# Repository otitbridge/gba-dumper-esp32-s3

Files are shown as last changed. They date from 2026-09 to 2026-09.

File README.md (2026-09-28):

# GBA専用ダンパー V1 — WeAct ESP32S3-A N16R2

**状態：4層配線・AD6短縮・シルク最終整理・最終DRCまで完了。WeAct版ガーバー・ドリル・CPL出力と照合まで完了。JLCPCBへ5枚発注済み（2026-09-28）。実機未検証。**

正本ブランチは `main`（WeAct版）。識別子 `WEACT_ESP32S3_A_N16R2_GBA_V1_20260928`。WeAct本体の部品取り外し・パターンカットなし。N16R8やESP32S3-Bには適用しない。

- [最終シルク確認PNG](output/pcb/final_review/front_silk.png) / [出力前レビュー](docs/fabrication_review.md)
- [回路図SVG](output/schematic/gba_dumper.svg) / [PNG](output/schematic/gba_dumper.png) / [KiCad回路図](hardware/gba_dumper.kicad_sch)
- [配線概要PNG](output/pcb/routed/routing_overview.png) / [GND面](output/pcb/routed/ground_plane.png) / [配線記録](docs/routing.md) / [配線長比較](docs/routing_comparison.md)
- [配線前配置図PNG](output/pcb/placement.png) / [SVG](output/pcb/placement.svg) / [PCB](hardware/gba_dumper.kicad_pcb)
- [全体BOM](hardware/bom/preliminary.csv) / [調達表](hardware/bom/assembly_parts.csv) / [PCBA BOM](hardware/bom/jlcpcb_pcba.csv)
- [ピンマップ](docs/pinmap.md) / [ファームウェア定義](firmware/main/pinmap.hpp)
- [設計仕様](docs/design_spec.md) / [移行レビュー](docs/weact_migration_review.md)
- [ソケット・機械条件](docs/weact_footprint.md) / [配置条件](docs/pcb_placement.md) / [製造ルール](docs/manufacturing_rules.md)
- [未完了事項](docs/open_items.md) / [立上げ手順](docs/bringup.md)

UART0 TX43/RX44→CH343。GPIO35/36はSAVEデータ兼上位アドレス、GPIO37は/WR。GPIO19/20/48はGBAバスに接続しない。Native USBは本V1では使わずPCはUART端子へ接続。JP1初期OPEN、JP2通常CLOSE。カートリッジ・ジャンパ・子基板の挿抜はUSBを抜いてから。

基板のランド表面仕上げは**鉛含有HASL（通常のHASL）**を指定。注文番号 **[order-id-redacted]**、送料・SMT実装込み **4,609円**でユーザーが注文完了。[注文記録・費用内訳](docs/jlcpcb_order_20260928.md)を参照。

R1〜R33・C1/C2の35個を上面PCBA（5品種、既選定Basic）。J1/J2/J3/JP1/JP2は手はんだ。ソケットは秋月110073の40極品2本から22極を各1本切り出す。WeAct付属ヘッダとの嵌合は到着後確認。ファームウェア成果物はピン定義のみで、ドライバ・ホストは未実装。

旧FNK0099設計は過去コミット `6403600` に保持。[旧製造データ・検査履歴](archive/fnk0099/README.md)はWeAct版に使用禁止。WeAct用Gerber・ドリル・CPLは[製造レビュー出力](output/fabrication_review/README.md)を参照。

## 再生成と確認

KiCad 10.0.5のCLIと、pcbnewを含むKiCad同梱Pythonを使う。`KICAD_PYTHON`と`KICAD_CLI`は各環境の実行パスに設定する。

```sh
python3 tools/generate_design.py
"$KICAD_CLI" sch export netlist --format kicadxml -o hardware/verification/gba_dumper.xml hardware/gba_dumper.kicad_sch
"$KICAD_CLI" sch erc -o hardware/verification/erc.rpt hardware/gba_dumper.kicad_sch
"$KICAD_PYTHON" tools/generate_placement.py
"$KICAD_PYTHON" tools/configure_manufacturing.py
"$KICAD_PYTHON" tools/sync_pcb_metadata.py
"$KICAD_CLI" pcb drc --schematic-parity --format json -o hardware/verification/placement_drc.json hardware/gba_dumper.kicad_pcb
python3 tests/hardware/check_design.py
"$KICAD_PYTHON" tests/hardware/check_placement.py
python3 tests/hardware/check_manufacturing.py
c++ -std=c++17 -Wall -Wextra -pedantic -fsyntax-only tests/pinmap/compile.cpp
```

生成元に変更を反映してから再生成する。配置スクリプトは配線済み基板への上書きを拒否する。配線前の描画手順はtools/export_review.sh。現在の配線画像はtools/export_routing.shで出力する。WeAct向けの配線スクリプトをtoolsへ追加。旧座標に依存するFNK版と製造出力スクリプトはarchiveへ保存。配線済みPCBに対して上記のgenerate_placement.pyは実行せず、配線の再生成は配線前コミットef14faeを別作業コピーに展開して行う。

現行配線の検査はKiCad同梱Pythonでtests/hardware/check_routing.pyとtests/hardware/check_route_lengths.py。前工程の確認記録はdocs/weact_migration_review.md。部品位置・銅箔は維持し、シルク文字のみ更新済み。tests/hardware/check_silkscreen.pyで変更範囲を検証する。

## ライセンス

自作ハードウェア・設計文書はCERN-OHL-P-2.0、ソフトウェアはMIT。[適用範囲と本文](LICENSE.md) / [第三者資料の表示](THIRD_PARTY_NOTICES.md)。実機未検証で、現時点では動作するダンパーファームウェアを提供していません。

## 公開履歴と参照資料

この公開版は新しいGit履歴で開始します。文書中の過去コミットIDは非公開の開発履歴を指し、この公開リポジトリでは参照できません。旧設計の内容はarchive/fnk0099を参照してください。WeAct公式参考PDFは同梱せず、hardware/reference/weact/sources.jsonの公式リポジトリから取得してください。設計・製造ファイルは発注時の内容を維持しています。

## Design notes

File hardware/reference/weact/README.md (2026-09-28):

WeAct公式の回路図・外形図は公開版に同梱していません。原著作権はWeActStudioに帰属します。

公式配布元: https://github.com/WeActStudio/WeActStudio.ESP32S3-AorB

取得時のSHA-256とファイル名はsources.jsonを参照。ファイル名のみASCIIへ変更して記録しています。

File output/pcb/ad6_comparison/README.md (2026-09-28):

# AD6経路比較

変更前はarchive/fnk0099/gba_dumper.kicad_pcb、変更後はAD6再配線前のhardware/verification/ad6_reroute/before.kicad_pcb。上面視・同一縮尺。基板輪郭は100 mm角。全配線を薄灰色、AD6のMCU側とカートリッジ側を層別の色で強調。丸枠はビア、黄色丸は接続パッド、R7両端の破線は抵抗本体。

- before_fnk0099.png: 変更前
- after_weact.png: 変更後
- comparison.png: 左右比較

図の強調はAD6ネット全体（小さな枝も含む）。表示長は比較資料と同じ最短の主経路で、パッド内部・抵抗内部・ビア垂直長は除く。FNKは65.33 mm、WeActは83.23 mm。WeActの全トラック合計は83.32 mmで、主経路との差は約0.09 mm。層間の移動は丸枠で追える。実際のKiCadトラック座標から描画し、線の視認性を上げるため描画幅のみ強調している。基板や配線は変更していない。

再生成: KiCad同梱Pythonでtools/render_ad6_comparison.pyを実行し、SVGをNode sharpでPNGへラスタライズする。

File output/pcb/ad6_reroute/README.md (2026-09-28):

# WeAct AD6再配線前後

左:83.23 mm、右:73.69 mm。詳細は[検証記録](../../../docs/ad6_reroute.md)。実PCB座標を描画。赤F.Cu、橙In2.Cu、青B.Cu。

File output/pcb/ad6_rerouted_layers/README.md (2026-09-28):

# AD6再配線後の4層配線図

2026-09-28。正式PCBからKiCad CLIで各銅箔層とEdge.Cutsを出図。全層を部品面から透視した向き・同一縮尺で表示し、裏面も反転していない。In1.CuはGND面。銅箔・パッド・ビア・穴を表示し、シルクは省略。

- four_layers.png: 4層一覧、上段F.Cu／In1.Cu、下段In2.Cu／B.Cu
- F.Cu.png、In1.Cu.png、In2.Cu.png、B.Cu.png: 各層2000×2000 px
- 同名SVG: ベクトル原図
- source.json: 出図元PCBとSHA-256

AD6主経路73.69 mmの再配線後。PCB自体は変更していない。閲覧用資料であり製造出力ではない。

再生成: 各層について `kicad-cli pcb export svg --layers <layer>,Edge.Cuts --mode-single --page-size-mode 2 --exclude-drawing-sheet -o output/pcb/ad6_rerouted_layers/<layer>.svg hardware/gba_dumper.kicad_pcb`、続いてsharpが使えるNodeで `tools/render_routing_layers.js` を実行。

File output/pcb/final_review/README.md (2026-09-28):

# シルク最終確認

front_silk.png / SVGは上面視。濃紺シルク、灰色マスク開口。tools/export_final_review.shで再生成。製造出力ではない。検証結果はdocs/fabrication_review.mdとhardware/verification/silkscreen/summary.json。

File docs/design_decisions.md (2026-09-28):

# 現行設計の変更履歴

## 2026-09-28 WeAct 4層配線・比較完了

承認済み配置・既存シルクを維持して配線。未配線/DRC/回路図不一致0、In1はGND単一充填領域。総配線長はFNK版比−3.51%、AD6主経路は+27.39%。ユーザー指示に従い比較結果を記録して停止し、シルク最終整理や追加の配線最適化には進まない。詳細はrouting.mdとrouting_comparison.md。

## 2026-09-28 WeAct版・配線前へ移行

ユーザー承認によりWeAct N16R2へ設計変更。GPIO19→35、20→36、48→37。J1/J2は22極・列間27.94 mm、3V3両端子とGND4端子を親基板で接続。ソケット購入は40極品2本。旧Native USB封止部材を除外。回路値・J3・JP・TP・固定脚は維持。子基板無改造。現行仕様はdesign_spec.md、配置判断はpcb_placement.md。旧配線・出力はarchiveへ移し、WeAct版は配線直前で停止。

以下はFNK0099版の過去の判断であり、現行WeAct版を上書きしない。

# 設計判断・変更履歴

## 2026-09-28 WeAct N16R2の調達・機械条件

ユーザーがWeAct ESP32S3-A N16R2を発注済み。販売業者確認として、FNK0099比で長手+5.08 mm・短手+2.54 mm、下面部品なし、USB位置・実装高さは同様との条件を受領。[移行検討記録](weact_n16r2_assessment.md)に採用条件と残作業をまとめた。現行FNK0099のCAD・製造データは未変更。実物の検証済みを意味しない。

## 2026-09-27 初版

提供仕様の論理配線をそのまま採用。28信号、R1〜R33、C1/C2、JP1/JP2、TP12個を作成。FNK0099そのものは購入ボードであり、親基板BOMのJ1/J2ソケットとは別途1台必要。封止部材・固定部材も別途必要。

追記「FNK0099の表面実装部品を外す。改造行為は許容」を、元の無改造制約に優先する変更として採用する。改造は許容されたが、対象部品・実装リビジョン・作業手順は未確定。現時点で部品取り外しは実施していない。

GPIO2 LED負荷の切離し、GPIO48 WS2812入力負荷の切離しは調査候補。部品番号・直列抵抗・分岐点は現物導通で特定する。GPIOへの経路や必須電源部品まで除去しない。GPIO19/20の物理USB配線はソフト設定だけでは消えない。コネクタや保護部品を外す場合も、端子封止不要と即断せず導通・容量を再評価する。

改造許容後もGPIO35〜37予約、UART43/44、GPIO配列、外付けロジックICを追加しない方針は維持する。GPIO割付変更は別途仕様変更として扱う。

## 回路図の表現

J1/J2は独自端子番号とGPIO名を併記した受動ソケットシンボル。J3は論理番号を持つ受動スロットシンボル。FNK0099内部やカートリッジICの駆動能力をERCモデルで推定しない。実在する受動インターコネクトなので全ピンpassiveとした。PWR_FLAGによる警告の一括抑制は行っていない。

電源供給源はJ1-1。JP2→CART_3V3、J2-20→GND。/WRのR31はJP1のカートリッジ側。R32はJP2装着時にGPIO3をR28経由でHIGH保持する。JP2開放時の起動ストラップを保証しない。

ERC 0件は電源余裕・起動時波形・部品改造・基板設計の検証ではない。初版時点ではフットプリントは全て未割付。抵抗0805は候補に留める。PCBとDRCは機械寸法確定後に実施する。

## USB給電についての追加確認

5 V・2 A電源は入力電源の候補とする。ただし、この表示だけではカートリッジを含むシステムの給電能力を確定できない。給電経路はCH343側USB-Cの5 V → FNK0099搭載レギュレータ → 3.3 V → ESP32とカートリッジ。外部電源の2 A定格は3.3 V端子の取り出し可能電流ではない。

搭載レギュレータの型番・供給能力・放熱条件を確認し、対象カートリッジ読出し中の電圧低下・発熱・リセットを評価する。現時点では給電能力を検証済みとしない。

PCへのダンプはCH343側USB一本で給電・データ通信する方針を維持する。充電器だけではPC転送できない。Native USB側はGPIO19/20をGBAバスに使うため、給電目的でも使用しない。複数電源を無検討で並列接続しない。

## FNK0099ソケット形状の採用

2026-09-27のユーザー指定に基づき、kariya-iot-pcbの1×20ソケットをJ1/J2へ割当。ピッチ2.54mm、列中心間25.40mm、穴径1.02mm。詳細は[fnk0099_footprint.md](fnk0099_footprint.md)。現行GPIO割付を維持し、全体の機械干渉確認は未完了。

## FNK0099実装高さ・下面部品の条件採用

2026-09-27のユーザー追加指定により、kariya-iot-pcbのESP32-WROVERと同一として設計する。FH2.54-40U1GF8.5-0.5（ハウジング高さ8.5mm）、下面部品突出最大2.0mm、基板間隔最低2.5mm・目標3.0mm以上を採用。ボード直下にはJ1/J2以外の表面実装部品を配置しない。詳細は[fnk0099_footprint.md](fnk0099_footprint.md)。基板間隔は組立後の受入検査として維持し、既存設計からの採用を新規実測済みとは記録しない。

## PCBA受動部品の選定

2026-09-27、工程1として抵抗3種類・コンデンサ2種類を0805のJLCPCB Basicで選定。片面SMT、手はんだソケット類はPCBA BOMから除外。型番・定格・DCバイアス評価は[pcba_parts.md](pcba_parts.md)に記録。回路値とGPIO配線は変更しない。

## JP1/JP2の型式確定

2026-09-27、秋月PH-1X2SG（108593）とつまみ付き2228GG黒（103890）を共通採用。ヘッダは各1個を手はんだ、キャップは計2個を用意しJP1は初期別保管・JP2は装着。推奨穴径1.02mmのフットプリントへ割当。詳細は[jumper_parts.md](jumper_parts.md)。

## J3フットプリントのユーザー裁定

2026-09-27、「渡してあるGitHubのリポジトリのフットプリントで確定」との明示裁定に従い、GekkioのGameBoy_Cartridge_AGB_1x32_P1.50mm_Socket_Horizontalを原本のままJ3へ割当。説明文および32番端子位置を理由とする採用保留を解除。実測済みへの書換えは行わず、採用根拠をユーザー裁定として記録。

## 2026-09-27 TP・組立部材と調達情報

TP全12点にφ2mm露出銅箔パッドを割当。J1/J2のRonmee型番・秋月110073を回路図/BOMへ補完し、ユーザーの嵌合確認済み回答を記録。J3はユーザー指定AliExpress商品1005005472303111を調達先として記録し、メーカー型番は不明と明示した。承認済みフットプリントを維持。

Native USB封止にTK-CAP6BK＋No.21赤絶縁テープ、親基板下面脚に秋月101861を選定。部材の詳細と配置・組立確認はmechanical_parts.md。調達数量を回路図実装数量から分離したassembly_parts.csvを追加。封止材と脚は選定済みだが実物適合・配置検証済みではない。

## 2026-09-27 PCB仮配置

100×100mm、4層、上面に全52部品と4個の固定穴を配置。J1/J2列間25.40mm、J3原本形状を維持。FNK0099外形・アンテナ・USB位置は仮占有範囲として明示し、未配線86件を残した配置成果物。DRCは未配線以外0件。詳細はpcb_placement.md。製造承認は行わない。

## 2026-09-27 FNK0099機械範囲のユーザー確認

ユーザー回答「ユーザ側で問題ないことが確認できています」に基づき、e5463f8のFNK0099外形・USB・アンテナ範囲と配置を確認済みとして採用。該当範囲の確認待ちを解除し、配置変更なしで次工程へ進める。文書のみ更新し、既存PCB・画像の仮注記より本確認記録を優先する。新規採寸・電気検証・製造承認の完了は意味しない。

## 2026-09-27 配置・アクセスのユーザー確認

「配置調整、固定穴・ジャンパ・TPへのアクセス確認」について、ユーザーから問題ないことを確認済みとの回答を受領。現配置のH1〜H4、JP1/JP2、TP1〜TP12へのアクセスを確認完了とし、追加の配置調整は不要とする。文書のみ更新し、PCB形状・座標は維持。新規実測や固定強度・封止保持性・電気的検証の完了とは区別する。

## 2026-09-27 製造ルール設定

JLCPCB公式能力に照合し、最小配線幅・間隔0.20mm、標準ビア0.60/0.30mm、電源標準0.80mm・最小0.50mm等をKiCadに設定。配置・機械寸法は変更せず、製造シルク基準による既存120警告を残項目として記録。カスタムルールの読込とDRC実行に成功。未配線86件。製造承認は行わない。

## 2026-09-27 4層配線完了

既存配置を維持してF.Cu/In2.Cu/B.Cuを配線、In1.Cuを連続GND面とした。未配線0、電気・幾何DRCエラー0、回路図等価性問題0。貫通ビア63個。シルク120警告は別工程で修正。詳細はrouting.md。製造承認は行わない。

## 2026-09-27 シルク整理・出図前CAD確認

可視シルク文字を高さ1.0mm以上・線幅0.15mmへ統一し、Native USB禁止・USBを抜いてからの操作・ジャンパ初期状態を表示。既知120警告を全解消。配線・ビア・パッド・部品位置は維持。DRC違反0・未配線0・回路図不一致0。PCBA上面35部品と5行BOMも照合。実機条件未完了のため製造承認は行わない。

## 2026-09-28 — AD6のみの再配線

ユーザー指示により他配線を固定し、AD6のGPIO10→R7区間だけを短縮。全主経路83.23→73.69 mm、ビア2→3個。他ネットとCART_AD6のトラック・ビア624要素は変更前と完全一致。配置・シルク不変、DRC/未配線/回路図等価性問題0。最短性の証明ではなく、長さ短縮とビア追加のトレードオフを採用。[記録](ad6_reroute.md)。

## 2026-09-28 — WeAct版シルク最終整理

ユーザー承認の工程範囲に従い、WeAct型番とUSB-UART通信経路、Native USB非使用、電源を抜いてからの操作対象を表示。UNROUTED表記を更新。シルク文字のみ変更し、AD6再配線後の全銅箔・配置・パッド・穴を維持。DRC/未配線/回路図等価性問題0。ガーバー・ドリル・CPLは出力せず停止。[出力前レビュー](fabrication_review.md)。

### シルク表示の追加修正

ユーザー指示によりNATIVE USB: UNUSEDを削除。J1/J2間の手前（USB側）のJ1寄りX=64、Y=98 mmへPCを追加。PC通信UART0→CH343の方針は維持し、Native USBホスト機能の正式採用を意味しない。DRC・未配線・回路図等価性問題0、銅箔と部品配置は不変。

ユーザーの追加指示により左側のPC: USB-UART表示を削除。J1寄りのPC表示とUART0→CH343の通信方針は維持。

ユーザー指示によりR32手前を「GBA DUMPER / WEACT ESP32S3-A」「S3-WROOM-1-N16R2 / REMOVE USB FIRST」の2行へ変更。中央左の旧型番表示と独立したREMOVE USB FIRSTを削除。配線・配置は維持。

ユーザー承認によりジャンパ表示を用途→初期状態の順に統一。JP1はWR ENABLE / DEFAULT OPEN、JP2はPOWER LINK / DEFAULT CLOSED。シルクのみ変更し、電気的仕様は維持。

ユーザー指示により中央のJP1 / JP2 / CARTRIDGEを削除。JP2をCARTRIDGE / POWER LINK / DEFAULT CLOSED、JP1をCARTRIDGE / WR ENABLE / DEFAULT OPENの3行へ変更。

ユーザー確定のリポジトリURLとQRを左中央へ追加。読み取り先はhttps://github.com/otitbridge/gba-dumper-esp32-s3。リポジトリ作成・公開は未実施。DRC0、画像復号一致、銅箔・配置不変。詳細はfabrication_review.md。

2026-09-28、ユーザーが「シルクは以上で確定」と承認。URL・QRを含む現行シルクを確定し、コミットする。次工程のGerber・ドリル・CPL出力と照合は、ユーザーの「まだ作業はしない」に従い未着手。シルク確定は実機検証完了や発注承認を意味しない。

## 2026-09-28 — 鉛含有HASLを指定

費用低減のため、ユーザー指定により現行WeAct版の裸基板ランド表面仕上げを鉛含有HASL（通常のHASL）へ確定。「HASL候補」の曖昧な表記を修正。PCBAはんだペースト組成の指定とは区別する。旧FNK版の見積り・製造前提は履歴として保持し、現行仕様には適用しない。金額はWeAct版の見積り時に確認する。

## 2026-09-28 WeAct製造レビュー出力

ユーザー指示によりHASL指定文書をd64897fでコミット後、Gerber・ドリル・CPLを作成・照合。output/fabrication_reviewにWeAct専用レビュー出力を保存。DRC0、PTH142、NPTH6、PCBA35個/BOM5品種一致、Gerber上のQR復号一致。実機ゲートと製造承認は未完了のまま維持。

## 2026-09-28 WeAct版をユーザーが発注完了

JLCPCB注文番号 **[order-id-redacted]**、送料・上面SMT実装込み **4,609円**で注文完了とのユーザー報告を記録。5枚、鉛含有HASL、Economic PCBA、35部品/枚、配送OCS Express。[注文記録と費用内訳](jlcpcb_order_20260928.md)。注文完了と実機検証完了は区別し、残件はopen_items.mdに維持する。

## 2026-09-28 WeAct版をmainの正本へ移行

ユーザー承認により、注文記録を `275fde3` でコミット後、`main` を `6403600` から `feat/weact-n16r2` の `275fde3` へfast-forwardで更新。main側に独自の追加コミットがなかったため、マージコミットや履歴の強制上書きは不要だった。正本はmainのWeAct ESP32S3-A N16R2版とし、旧FNK0099版は過去コミットとarchive/fnk0099に保持。作業ブランチは削除せず残す。

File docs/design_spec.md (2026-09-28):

# WeAct ESP32S3-A N16R2 設計仕様

2026-09-28。正本識別子 `WEACT_ESP32S3_A_N16R2_GBA_V1_20260928`。元のGBAバス・ROM/SAVE・UART要求を継承し、ボード固有条件は本書とpinmap.mdを優先する。初期引継ぎ原文はarchive/fnk0099/docs/handoff.mdの履歴に保存。

- ESP32-S3-WROOM-1-N16R2（16 MB Flash、2 MB Quad SPI PSRAM）搭載のWeAct ESP32S3-A専用。GPIO35/36/37を使用可能な型番であることを到着時に確認。R8やB版へ転用しない。
- 子基板は無改造。GPIO2にLED負荷なし。RGB用48、Native USB用19/20、BOOT0、KEY45、ストラップ46、UART43/44はGBAバスに使わない。
- GPIO3=/CS2は100 Ω直列＋カートリッジ側10 kΩでHIGH保持。JP2装着で共通給電し、起動・リセット・UART書込み確認が必要。GPIO39〜42は通常GPIOへ設定。
- AD16本、AH8本、制御4本。ADはbank0内、AHはbank0/1跨ぎ。方向切替の排他制御、制御線HIGHを先にラッチして出力有効化、異常終了時の非選択復帰を維持。64ビットGPIOマスクを使用。
- R1〜24=330 Ω、R25〜28=100 Ω、R29〜32=10 kΩプルアップ、R33=10 kΩ PHIプルダウン。/REQはTPのみ。/WRはR27→JP1→カートリッジ、R31はJP1よりカートリッジ側。
- BOARD_3V3はJ1-1/2、GNDはJ1-22とJ2-1/21/22を接続。JP2→CART_3V3。C1=100 nF、C2=10 µF。5 Vは親基板NC。3.3 Vの供給能力は未検証。
- JP1初期OPEN、JP2通常CLOSE。EEPROM要求・Flash識別/バンク選択にはJP1装着が必要。読出し用プロトコル書込みとSAVE内容変更の許可を分離する。
- PCはUART側USB-C→CH343→UART0 TX43/RX44。115200 bpsで立上げ、921600は検証後。Native USBはV1では使用しない。GBAバスとは非接続なのでバス保護用の封止部材はBOMから除外。二つのUSB端子を同時給電しない。
- ESP-IDF+C/C++、内部RAM約4 KiBバッファ、PSRAMはV1では初期化しない。無線・RGB LEDドライバは起動しない。PSRAM無効化はGPIO解放のためではない。
- ROMはワードアドレス=byte_offset/2、16ビットをリトルエンディアンで保存。1ワードごとにアドレス再提示、初期待ち各1 µs・読出し待ち2 µsを評価出発点にする。容量は明示指定、ヘッダと境界検査、独立2回SHA-256照合。
- SAVEはSRAM/FRAM・Flash・EEPROM別ドライバ。未知種別への試し書き禁止。変更許可・バックアップ・型番/サイズ照合後のみ書戻し、全量ベリファイ。特殊カートリッジは対象外または個別検証。
- 通信のCRC・連番・オフセット・ACK/再送・タイムアウト・ABORT・書込み冪等性はprotocol.mdの要求を維持。ドライバ、確定通信仕様、無負荷試験FWは本段階では未実装。
- 100×100 mm FR-4 4層。In1.Cuを連続GND面として使う計画。配線工程でトラック・ビア・In1 GND面を作成済み。シルクの最終整理は次工程。Gate1〜3完了前は発注不可。

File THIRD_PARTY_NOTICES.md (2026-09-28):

# Third-party notices

## Gekkio cartridge socket footprint

Author: Gekkio. Source: https://github.com/Gekkio/gekkio-kicad-libs

`hardware/lib/Gekkio_Connector_PCBEdge.pretty/GameBoy_Cartridge_AGB_1x32_P1.50mm_Socket_Horizontal.kicad_mod` is redistributed unmodified under CC BY 4.0. Its placement within boards and rendered design outputs does not transfer ownership of the original library material. Attribution and hash: [docs/slot_footprint.md](docs/slot_footprint.md). License: [Gekkio-CC-BY-4.0.txt](hardware/lib/licenses/Gekkio-CC-BY-4.0.txt). Archived copies retain these same terms.

## KiCad libraries

Copyright: KiCad library contributors. Source: https://github.com/KiCad/kicad-footprints

KiCad standard footprints used or embedded in the design include 0805 resistors/capacitors, mounting holes and test points. The redistributed TestPoint_Pad_D2.0mm in GBA_Mechanical.pretty retains KiCad library terms. KiCad-derived library material and any modified copies retain CC BY-SA 4.0 with the KiCad library exception; project-level hardware licensing does not replace their terms. See [KiCad license and exception](hardware/lib/licenses/KiCad-LICENSE.md) and https://www.kicad.org/libraries/license/.

## WeAct reference documents

Source: https://github.com/WeActStudio/WeActStudio.ESP32S3-AorB

Reference circuit and mechanical PDFs are vendor documents, not original project material. Public snapshots omit these PDFs pending redistribution review; source URLs and SHA-256 records remain under hardware/reference/weact. Obtain originals from the vendor.

## External tools

KiCad, Gerbonara, sharp, macOS Vision, Freerouting and KiCad's bundled QR library are external build/review dependencies. Their executables/source packages are not bundled here. Their licenses are not replaced by this project's licenses.

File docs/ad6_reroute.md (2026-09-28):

# AD6単独再配線の結果

2026-09-28。ユーザー指示「他の線は変更せず、この線だけ再配線」に基づく。正式PCBへ短縮案を反映。シルク整理・製造出力には進んでいない。

|項目|再配線前|再配線後|
|---|---:|---:|
|GPIO10 / J1-16 → R7-1|35.66 mm|26.12 mm|
|R7-2 → J3-12|47.57 mm|47.57 mm（変更なし）|
|AD6主経路合計|83.23 mm|73.69 mm|
|AD6ビア数|2|3|

9.54 mm（11.47%）短縮できたため、旧経路には改善余地があった。新経路はIn2.Cuから追加の貫通ビアでB.Cuへ移動し、下側への迂回を短縮する。R7側の既存F.Cu引出し・ビア、カートリッジ側全経路は維持。追加ビアは径0.60 mm／穴0.30 mm、変更区間の線幅は0.25 mm。任意角度の直線を含む。設計ルールの緩和はしていない。

短い経路とビア1個追加の交換条件であり、波形品質の改善を保証するものではない。可能な全経路の探索・最短性の証明はしていない。長さはトラック中心線の主経路で、ビア垂直長・パッド内部・抵抗内部を含めない。

## 他配線の保持と検証

- /MCU_AD6以外の全トラック・ビア624要素をKiCadファイルのブロック単位で比較し、完全一致。/CART_AD6も含む。
- 部品位置・回転、パッドネット、部品フィールド、シルク、図形は承認済み配置と一致。
- GNDゾーンは再充填。追加ビアに伴う局所的な銅箔除外が変化するが、In1.Cuは連続1領域を維持（8936.57 mm²）。
- 正式PCBの再充填・保存・回路図等価性を含むDRC: 違反0、未配線0、等価性問題0。
- ピンマップ/BOM/ERC、配置、製造ルール、配線、経路長計算・元ファイルハッシュ、C++17定義の検査が合格。

## 比較画像と再現資料

[変更前後PNG](../output/pcb/ad6_reroute/comparison.png)。左が再配線前、右が再配線後。実PCB座標、同一縮尺の上面視。赤=F.Cu、橙=In2.Cu、青=B.Cu、白丸=ビア。灰色は他の配線。

hardware/verification/ad6_reroute/に変更前PCB、変更前集計、探索用障害物、採用座標manual_path.json、結果result.jsonを保存。router.logは既存配線を保護したFreerouting試行がMCU側を完結できなかった記録で、採用結果ではない。続いて0.15 mm格子の層別探索と経路簡略化で短縮案を生成し、KiCad DRCで実際の形状に対して検証した。

再現時は同ディレクトリのbefore.kicad_pcbとmanual_path.jsonをtmp/ad6-reroute/へコピーし、KiCad同梱Pythonでtools/apply_ad6_path.pyを実行する（候補PCBのみ生成）。正式採用時にはプロジェクトルール下でDRC・再充填が必要。tools/export_ad6_obstacles.pyとtools/search_ad6_path.pyは探索補助（後者はNumPyが必要）。画像生成はtools/render_ad6_reroute.pyとNode sharp。画像は線幅を視認用に強調している。

旧FNK比較画像output/pcb/ad6_comparison/は、AD6再配線前の83.23 mm時点の履歴として維持。現行のFNK比較は[配線長比較](routing_comparison.md)を参照。

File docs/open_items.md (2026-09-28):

# WeAct N16R2 未完了事項

今回の区切りはWeAct版ガーバー・ドリル・CPLの作成と照合完了。DRC違反・未配線・回路図不一致は0。2026-09-28、ユーザーがJLCPCB注文完了を報告（[order-id-redacted]、4,609円）。[注文記録](jlcpcb_order_20260928.md)を参照。実機未確認項目は維持する。

2026-09-28、ユーザーがコミット `797bb73` の設計変更を配置含めて確認し、問題なしと回答。配置レビュー待ちは解消済み。以下は到着品の照合・実機試験・後続工程の残件として維持する。

|項目|残る作業・根拠|
|---|---|
|到着品|N16R2刻印、ESP32S3-A基板版、公式22極端子順・GPIO35〜37の照合|
|ソケット|秋月110073の細ピン用22極カット品とWeAct付属ヘッダの嵌合。旧FNKの確認を転用しない|
|機械|未寸法の端子〜外形起点、USB突出とプラグ空間、到着品寸法・組立間隔・挿抜性・固定強度の確認。下面部品なし・高さ同等は販売業者回答を採用済み|
|GPIO3|JP2装着＋10 kΩプルアップで起動・リセット・UART書込み確認|
|GPIO・波形|全28本を安全な無負荷治具で確認。35/36/37および39〜42通常GPIO設定、制御線HIGH・起動グリッチ|
|電源|レギュレータ型番・許容電流・放熱、カートリッジ負荷で3.3 V・温度・リセットを確認|
|シルク・出力前レビュー|シルク文字整理・最終DRC完了。確認画像と結果はfabrication_review.md。2026-09-28、ユーザーがURL・QRを含むシルクを確定。製造出力と照合まで完了|
|製造出力|WeAct版Gerber・ドリル・CPL作成・照合済み（output/fabrication_review）。旧FNK版は使用禁止。注文画面で5品種Basic・実装プレビューを確認し発注済み。メーカー最終CAM・DFM、追加穴・捨て板の確認は残る|
|FW/ホスト|ピン定義のみ。ESP-IDF版固定、無負荷試験、ROM/SAVE・通信実装は後続工程|

GPIO19/20はGBAバス非接続、GPIO48も使用しない。部品取り外しとNative USBバス保護用封止は不要。V1のPC接続はUART端子のみ、二つのUSBを同時給電しない。元の発注条件はGate1〜3の完了だったが、未確認項目を残した状態でユーザーが発注を完了した。Gate完了・実機検証済みとは記録しない。

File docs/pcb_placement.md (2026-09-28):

# WeAct N16R2 配線前配置の記録

以下は承認済み配置の記録。部品位置は維持して4層配線を完了した。現行PCBの接続・DRC状態は[routing.md](routing.md)を参照。

## ユーザー配置確認（2026-09-28）

コミット `797bb73` の設計変更・配置図について、ユーザーから「配置含めて問題ありません」と回答を受領。USB側本体が親基板から約2.4 mm出る想定、ソケット・固定穴・ジャンパ・TPの配置を含む現配置を承認済みとして維持する。配置レビュー待ちは解除する。これは提示設計への確認であり、到着品の寸法照合・嵌合・電気試験を実施済みとするものではない。今回、CADや部品位置は変更していない。

2026-09-28。100×100 mm、4層、1.6 mm。52個の回路図部品＋固定穴4個。トラック0・ビア0・銅箔ゾーン0、ルール領域のみ。未配線90接続。DRC違反0、回路図等価性問題0。

|部品|配置（mm、上面視）|
|---|---|
|J1|1番=(57,44.5)、回転0°、22極|
|J2|1番=(84.94,44.5)、回転0°、22極|
|J3|基準=(28,27)、従来のユーザー指定フットプリントを維持|
|JP1|=(32,72)、WeAct本体より左側|
|JP2|=(13,38)、WeAct本体より左側|
|H1〜H4|=(5,5),(95,5),(5,95),(95,95)、φ3.2 mm丸穴、8 mm角銅箔禁止域|

J1/J2の列中心間27.94 mm、最終端子Y=97.84 mm。旧基板の22極化に合わせ両列位置を調整。C1/C2はJ3電源付近、R1〜16はJ1左、R17〜24はJ2右に配置。部品・JP・TPはWeAct本体の投影外。JPキャップと指・測定リードの空間は左側へ確保し、旧ソケット範囲のまま流用しない。

配置用本体枠はX=55.349〜86.591、Y=39.635〜102.391。USB側で親基板から約2.4 mm出る想定で、USBケーブルは親基板の下辺外へ抜ける。元図で未寸法の端子起点は読み取り値のため、外形枠とUSB突出は到着後照合する。USBプラグの実物寸法は未評価。アンテナ側はGBAスロットの外接範囲Y≈28.6より下に置き、投影が重ならない。

アンテナの投影周辺を全4銅層で禁止（X=59.97〜81.97、Y=32.595〜39.635）。これは無線を使わないV1のアンテナ直下保護領域で、メーカーのRF性能を狙う周囲15 mm空間を満たす保証ではない。Wi-Fi/BLE/ESP-NOWを将来有効化するならGBAスロットを含め配置を再評価する。WeAct直下にはソケット以外の部品を置かず、内側を部品禁止領域で保護する。

画像: [PNG](../output/pcb/placement.png) / [SVG](../output/pcb/placement.svg)。回路図と全パッドネットを照合済み、固定穴周囲への銅箔パッド侵入なし。実物の挿抜性・固定強度・ソケット嵌合は未確認であり、CADチェックとは区別する。

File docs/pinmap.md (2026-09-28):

# GPIO・ソケット配線正本

識別子: `WEACT_ESP32S3_A_N16R2_GBA_V1_20260928`。実機未検証。

J1/J2は部品面、アンテナ上・USB下で左/右、上から1–22。

|GBA端子|信号|GPIO|ソケット|直列抵抗|
|---:|---|---:|---|---|
|1|3V3|—|J1-1 → JP2|—|
|2|PHI|—|R33 → GND + TP|—|
|3|nWR|37|J2-11|R27 / 100 Ω|
|4|nRD|2|J2-5|R26 / 100 Ω|
|5|nCS|47|J2-17|R25 / 100 Ω|
|6|AD0|4|J1-4|R1 / 330 Ω|
|7|AD1|5|J1-5|R2 / 330 Ω|
|8|AD2|6|J1-6|R3 / 330 Ω|
|9|AD3|7|J1-7|R4 / 330 Ω|
|10|AD4|8|J1-12|R5 / 330 Ω|
|11|AD5|9|J1-15|R6 / 330 Ω|
|12|AD6|10|J1-16|R7 / 330 Ω|
|13|AD7|11|J1-17|R8 / 330 Ω|
|14|AD8|12|J1-18|R9 / 330 Ω|
|15|AD9|13|J1-19|R10 / 330 Ω|
|16|AD10|14|J1-20|R11 / 330 Ω|
|17|AD11|15|J1-8|R12 / 330 Ω|
|18|AD12|16|J1-9|R13 / 330 Ω|
|19|AD13|17|J1-10|R14 / 330 Ω|
|20|AD14|18|J1-11|R15 / 330 Ω|
|21|AD15|21|J2-18|R16 / 330 Ω|
|22|A16_D0|1|J2-4|R17 / 330 Ω|
|23|A17_D1|35|J2-13|R18 / 330 Ω|
|24|A18_D2|36|J2-12|R19 / 330 Ω|
|25|A19_D3|38|J2-10|R20 / 330 Ω|
|26|A20_D4|39|J2-9|R21 / 330 Ω|
|27|A21_D5|40|J2-8|R22 / 330 Ω|
|28|A22_D6|41|J2-7|R23 / 330 Ω|
|29|A23_D7|42|J2-6|R24 / 330 Ω|
|30|nCS2|3|J1-13|R28 / 100 Ω|
|31|nREQ|—|TPのみ|—|
|32|GND|—|J2-22 (共通GND)|—|

|位置|J1|J2|
|---:|---|---|
|1|3V3|GND|
|2|3V3|GPIO43|
|3|EN|GPIO44|
|4|GPIO4|GPIO1|
|5|GPIO5|GPIO2|
|6|GPIO6|GPIO42|
|7|GPIO7|GPIO41|
|8|GPIO15|GPIO40|
|9|GPIO16|GPIO39|
|10|GPIO17|GPIO38|
|11|GPIO18|GPIO37|
|12|GPIO8|GPIO36|
|13|GPIO3|GPIO35|
|14|GPIO46|GPIO0|
|15|GPIO9|GPIO45|
|16|GPIO10|GPIO48|
|17|GPIO11|GPIO47|
|18|GPIO12|GPIO21|
|19|GPIO13|GPIO20|
|20|GPIO14|GPIO19|
|21|5V|GND|
|22|GND|GND|

GPIO0/19/20/43/44/45/46/48、EN、5Vは親基板でNC。UART0はWeAct上のCH343に接続されたまま。/WRはR27→JP1→CART_nWR、R31はJP1よりカートリッジ側。/CS2プルアップはJP2装着時のみ給電される。

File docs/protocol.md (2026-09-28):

# PC通信仕様 — 要求のみ、未確定・未実装

UART0→CH343、115200bps 8N1、RTS/CTSなし。HELLO/GET_INFO/READ_HEADER/READ_ROM/READ_SAVE/WRITE_SAVE/ABORTを候補とする。

各フレームに版・種別・連番・絶対バイトoffset・長さ・CRC。チャンクACK/再送、同期前ブートログ破棄、バイナリ開始後非フレームログ禁止。CRC検査後のみファイルへ反映し、未完了は.partial。奇数ROMアドレス、不正長、範囲外、timeoutはエラー。WRITE_SAVEは成功済みIDを認識し再送で二重実行しない。

同期語、CRC多項式・初期値、エンディアン、フィールド幅、ACK/timeout/再送回数、切断検出と冪等性保持期間は実装前に固定する。本ファイルを完成したwire protocolと扱わない。

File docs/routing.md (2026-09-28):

# WeAct N16R2 4層配線 — シルク最終整理前

この文書は配線工程の記録。現在はシルク整理・最終DRCも完了し、[出力前レビュー](fabrication_review.md)で停止。以下のシルク未更新の記述は配線工程当時の履歴。

2026-09-28。ユーザー承認済み配置を維持して配線。DRC違反0、未配線0、回路図等価性問題0。**シルクの最終整理・追加と製造出力には進まず、この工程で停止。実機未検証、発注不可。**

|層|役割|トラック数|延長 mm|
|---|---|---:|---:|
|F.Cu|部品面の信号・電源・GND引出し|228|849.60|
|In1.Cu|連続GND面、トラック禁止|0|0|
|In2.Cu|主な信号・電源経路|297|1705.30|
|B.Cu|補助経路|45|346.72|

総トラック長2901.62 mm、貫通ビア62個。信号最小幅0.20 mm、電源/GND最小幅0.50 mmを確認。GND充填領域は1個、面積8936.57 mm²。禁止領域と非GND穴の離隔を反映し、接続検査で未配線なし。面の連続性は確認したが、実機の信号品質を保証するものではない。

## 検証と比較

- 全52回路図部品の位置・回転、全パッドのネット、固定穴を確認。部品フィールド・シルク・図形も配線前と一致。hardware/verification/routing/approved_layout.jsonへ照合用情報を保存。
- ERC、ピンマップ/BOM、C++17定義、配置、製造ルール、配線の検査が合格。ゾーン再充填・保存と回路図等価性を含む最新DRCはhardware/verification/routing_drc.json。
- [FNK0099比較](routing_comparison.md): 総延長−3.83%、最長主経路+0.18%。AD6は個別再配線後、FNK比+8.35 mm（+12.79%）。[AD6のみの再配線記録](ad6_reroute.md)を参照。
- [配線概要PNG](../output/pcb/routed/routing_overview.png) / [SVG](../output/pcb/routed/routing_overview.svg)。赤F.Cu・橙In2.Cu・青B.Cuを上面から表示。
- [GND面PNG](../output/pcb/routed/ground_plane.png) / [SVG](../output/pcb/routed/ground_plane.svg)。In1.Cuは別図で表示し、概要図で他の配線を塗りつぶさない。

## 手順と再現資料

ローカルFreerouting 2.4.1とTemurin JRE 25を既存環境から使用。GUI・API/MCPサーバー・利用状況送信を無効化し、外部配線APIを使わない。JAR SHA-256は251101c3eeac22d7e7dfcf6796603279e5d1000283eb82d8f093780f7afc6aa9。

prepare_routing.pyはWeActの配置からGND引出しを作り、DSN/層ルールを準備する。KiCadのDSN変換が部品禁止領域を銅箔禁止に解釈するため、出力用コピーのみWEACT_UNDERSIDE_NO_COMPONENTSを除去。正式PCBには残す。アンテナ・固定穴の銅箔禁止域とJ3長穴の追加余裕を維持。旧FNKのA16固定経路は持ち込まない。

run_router.shでローカル配線、import_routing.pyでSESとIn1 GND面を取り込み。finish_routing.pyは最小線幅未満だったAD0の2セグメント（0.1874 mm）を0.20 mmへ修正。正式PCBをKiCad DRCで再充填・保存・検査し、違反0を確認。DRC除外や製造ルールの緩和は行っていない。

DSN・ルール・SES・実行ログはhardware/verification/routing/。SESは幅修正・面追加前の中間結果。正本はhardware/gba_dumper.kicad_pcb。配線前の検査記録とplacement画像は履歴として残し、現行結果と区別する。

## 次工程に残すもの

シルクのV1 PLACEMENT / UNROUTEDは意図的に配線前のまま残している。次工程で恒久表記・ボード識別・端子用途表示等と合わせて更新する。DRCが0件でも文言の最終整理完了を意味しない。ガーバー・ドリル・CPL、製造承認、到着品の寸法・嵌合・GPIO起動・電源試験は未完了。

参照: [Freerouting 2.4.1](https://github.com/freerouting/freerouting/releases/tag/v2.4.1)、[同版CLI仕様](https://github.com/freerouting/freerouting/blob/v2.4.1/docs/command_line_arguments.md)。閲覧用出図はtools/export_routing.sh。

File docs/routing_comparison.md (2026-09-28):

# FNK0099版とWeAct版の配線長比較

2026-09-28。同じ集計スクリプトで配線済みPCBを比較。FNK0099はmainの6403600時点を保存したarchive/fnk0099/gba_dumper.kicad_pcb、WeActは今回のhardware/gba_dumper.kicad_pcb。元ファイルのSHA-256はJSONに記録。

**総延長は約3.8%減、最長のGPIO〜カートリッジ経路はほぼ同じ。個別信号には増減があるため、全信号が同等とは扱わない。ユーザー指示によりAD6のみを追加短縮した。シルク整理には進んでいない。**

|項目|FNK0099|WeAct|差|
|---|---:|---:|---:|
|総トラック長|3017.07 mm|2901.62 mm|-115.45 mm（-3.83%）|
|信号トラック長（分岐含む）|2678.75 mm|2568.69 mm|-110.06 mm（-4.11%）|
|3.3 V電源トラック長|157.54 mm|152.84 mm|-4.70 mm（-2.98%）|
|GNDトラック長（面を除く）|180.78 mm|180.09 mm|-0.70 mm（-0.38%）|
|貫通ビア数|63|62|-1|
|最長の主経路（AD15）|134.84 mm|135.08 mm|+0.24 mm（+0.18%）|

AD6は当初65.33→83.23 mm（+17.90 mm、+27.39%）だったが、[単独再配線](ad6_reroute.md)により73.69 mm（FNK比+8.35 mm、+12.79%）へ短縮。現在も増加率・増加量ともAD6が最大。最大減少はAD13:113.20→86.69 mm（−26.50 mm、−23.41%）。部品位置は承認済みWeAct配置を維持しており、これらはピン配置・禁止域・ルーター経路の違いを含む今回の結果である。ボード変更だけによる必然的増減や、最短配線の限界を示すものではない。

## 測定方法と限界

- 総延長・ネット合計はKiCadの全トラック中心線長の総和。TPやプルアップへの枝線を含む。GND面は長さに換算せず、面積・連結領域数を別集計。
- 主経路はGPIOソケット→抵抗pin1と、抵抗pin2→J3の中心線グラフ最短経路を合算。/WRはR27→JP1とJP1→J3も含む。T分岐を分割し、同ネットの導電パッドと貫通ビアで層間を接続する。
- 抵抗内部、ジャンパシャント、パッド内部、ビアの垂直バレル長、子基板上のESP32からヘッダまでの配線は含めない。親基板上の経路比較であり、電気的遅延・実装全体の配線長ではない。
- 経路を「合計ネット長」と混同しない。枝線を除いた主経路と、枝線を含む合計をCSVで併記。アークは今回存在せず、将来アーク追加時はスクリプトが拒否する。
- 等長配線、高速動作、波形品質を保証しない。立上げは従来の低速タイミングで行う。個別の増加が許容できるかは波形・実機読出しで確認する。

## 全28信号の主経路

|信号|FNK0099 mm|WeAct mm|差 mm|差 %|
|---|---:|---:|---:|---:|
|AD0|48.55|48.02|-0.53|-1.08|
|AD1|41.52|43.23|+1.71|+4.13|
|AD2|45.58|48.32|+2.74|+6.02|
|AD3|47.00|48.24|+1.23|+2.62|
|AD4|54.85|60.62|+5.77|+10.52|
|AD5|62.77|65.27|+2.50|+3.98|
|AD6|65.33|73.69|+8.35|+12.79|
|AD7|64.95|69.89|+4.95|+7.62|
|AD8|74.20|74.08|-0.12|-0.16|
|AD9|73.61|69.79|-3.82|-5.19|
|AD10|77.96|81.07|+3.11|+3.99|
|AD11|103.55|82.23|-21.33|-20.59|
|AD12|101.87|86.43|-15.44|-15.15|
|AD13|113.20|86.69|-26.50|-23.41|
|AD14|108.46|116.65|+8.20|+7.56|
|AD15|134.84|135.08|+0.24|+0.18|
|A16_D0|79.43|61.82|-17.61|-22.17|
|A17_D1|100.85|81.87|-18.98|-18.82|
|A18_D2|104.95|86.62|-18.32|-17.46|
|A19_D3|80.88|77.25|-3.63|-4.49|
|A20_D4|85.34|70.27|-15.08|-17.67|
|A21_D5|85.48|79.76|-5.72|-6.69|
|A22_D6|91.32|82.60|-8.72|-9.55|
|A23_D7|100.53|91.72|-8.80|-8.76|
|nCS|125.15|121.71|-3.44|-2.75|
|nRD|121.36|119.20|-2.15|-1.78|
|nWR|132.53|128.80|-3.73|-2.81|
|nCS2|134.33|130.29|-4.04|-3.01|

## 層別トラック長

|層|FNK0099 mm|WeAct mm|
|---|---:|---:|
|F.Cu|801.24|849.60|
|In1.Cu|0.00|0.00|
|In2.Cu|1908.07|1705.30|
|B.Cu|307.77|346.72|

[信号別CSV](../hardware/verification/routing_comparison.csv) / [ネット別CSV](../hardware/verification/routing_nets.csv) / [全数値・ハッシュJSON](../hardware/verification/routing_comparison.json)。再計算はKiCad同梱Pythonでtools/compare_routing.py。tests/hardware/check_route_lengths.pyでT分岐・ビア・枝線除外と元ファイルの一致を検査する。

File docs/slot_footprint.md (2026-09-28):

# J3スロットの確定フットプリント

2026-09-27、ユーザー裁定により提示GitHubフットプリントを確定採用。原本を変更せずプロジェクト内ライブラリに保存し、J3へ割当済み。採用根拠はユーザー裁定であり、新規実測の完了を意味しない。

- 著者・配布元: Gekkio / [gekkio-kicad-libs](https://github.com/Gekkio/gekkio-kicad-libs)
- [取得URL](https://raw.githubusercontent.com/Gekkio/gekkio-kicad-libs/main/Gekkio_Connector_PCBEdge.pretty/GameBoy_Cartridge_AGB_1x32_P1.50mm_Socket_Horizontal.kicad_mod)
- ライセンス: CC BY 4.0。原文はhardware/lib/licenses/Gekkio-CC-BY-4.0.txt。原本は無保証で提供される。
- KiCad形式: version 20260206、generator_version 10.0。
- SHA-256: `4a1884ea326590eea102b43216ce3d89ce4204e4d52d5eff547ab522a2feaf7b`
- 取得時のmainから保存。コミットIDは未取得。内容の同定には上記ハッシュを用いる。

## ファイルから確認できる寸法（mm）

|項目|内容|
|---|---|
|信号パッド|1〜32、各番号1個、スルーホール|
|X方向配置|1.5刻み。1番(0,0)、31番(45,0)|
|通常の偶数端子|2〜30番はY=-1.5|
|32番端子|**(46.5,-3)**。通常の偶数列と異なる|
|信号穴|直径1.0|
|銅箔パッド|1番1.4×1.4の矩形、2〜32番直径1.6の円|
|固定用NPTH|中心(-15.2,-1.4)、(54.7,-1.4)、穴1.6×4.6の長穴|
|Courtyard外接寸法|72.9×22.1（X=-16.7〜56.2、Y=-20.5〜1.6）|

上記外接寸法にはカートリッジの挿入・取り外し空間やWeActを含まない。100mm角への全体配置成立は別途確認する。

## 原本の特徴と裁定記録

ファイル名はAGBだがdescrは「Game Boy cartridge slot, Super Game Boy and Super Game Boy 2」。この説明文と32番端子のY=-3mm配置を含め、ユーザー裁定で原本のまま採用する。これらを理由とするフットプリント採用・割付の保留は解除した。

購入するスロットの型番または購入先は調達記録として別途記載する。組立時には採用形状に合う部品であることと接点の導通を受入検査する。汎用1×32一直線コネクタと交換可能とは扱わない。

3Dモデル参照は${KICAD10_3DMODEL_DIR}/Gekkio_Connector_PCBEdge.3dshapes/...wrl。モデル本体は未取得なので表示できると保証しない。今回のフットプリント確定は基板全体のGate3完了・製造承認とは別である。

調達先追記（2026-09-27）：ユーザーから https://ja.aliexpress.com/item/1005005472303111.html を指定。商品番号を調達識別子としてBOMへ反映。商品ページ本文は取得できず、メーカー型番や注文バリエーションは推測していない。フットプリント確定の裁定は維持する。

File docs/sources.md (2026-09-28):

# 現行WeAct版の参照資料

2026-09-28: WeActStudio公式ESP32S3-A回路図・外形図を取得、回路・ピン配列と機械寸法を確認。原本とSHA-256はhardware/reference/weact、照合結果はweact_footprint.md。Espressif WROOM-1データシートv1.8のTable1-1（N16R2 Quad SPI PSRAM）と3-1を再確認。秋月110073の切断可能構造、寸法、推奨穴径を再確認。下記S1/S2と旧S3のGPIO35〜37 NC方針はFNK0099版の履歴でありWeActへ適用しない。

# 参照資料・確認状況

基準日2026-09-27。ユーザー提示のS番号を維持する。再取得・再確認済みと、提供仕様から継承した根拠を区別する。

|ID|資料|今回の扱い|
|---|---|---|
|S1|[Freenove Preface](https://docs.freenove.com/projects/fnk0099/en/latest/fnk0099/codes/Python/Preface.html)|2026-09-27閲覧。ボードとCH343の背景確認。35〜37再利用記述は設計に採用しない|
|S2|[公式ピンアウト](https://raw.githubusercontent.com/Freenove/Freenove_ESP32_S3_WROOM_Board_Lite/main/ESP32S3_Lite_Pinout.png)、[公式リポジトリ](https://github.com/Freenove/Freenove_ESP32_S3_WROOM_Board_Lite)|2026-09-27画像を取得しJ1/J2全端子を視認照合。リポジトリmainツリーのパス検索では回路図を特定できず。現物寸法・取り外し部品番号は未確認|
|S3|[Espressif WROOM-1/1U datasheet](https://www.espressif.com/sites/default/files/documentation/esp32-s3-wroom-1_wroom-1u_datasheet_en.pdf)|提供資料のv1.8、印刷p12 Table3-1注bという根拠を継承。今回PDFの版を再確認していない。35〜37をNCとするユーザー指定を厳守|
|S4|[ESP-IDF GPIO](https://docs.espressif.com/projects/esp-idf/en/stable/esp32s3/api-reference/peripherals/gpio.html)|実装時に採用ESP-IDF版へ固定して再確認。今回ドライバ未実装|
|S5|[GBATEK GBA-only mirror](https://rust-console.github.io/gbatek-gbaonly/)|提示仕様のGBA論理番号・バス要求を継承。今回はプロトコル詳細を新規確定していない|
|S6|[gba-cartridge](https://github.com/jojolebarjos/gba-cartridge)|バス実装参考として継承。今回コードの転用なし|
|S7|[sanni/cartreader GBA.ino](https://github.com/sanni/cartreader/blob/master/Cart_Reader/GBA.ino)|提示blob SHA 6990b7c7b9d02da5d35fb39be63d971dfa922ccfはコミットではない。実装採用コミット・ライセンスは未確認、転用なし|
|S8|[ESP-IDF UART](https://docs.espressif.com/projects/esp-idf/en/stable/esp32s3/api-reference/peripherals/uart.html)|実装時に採用版と照合。今回未実装|

本回路図の値・GPIO配置・検証条件の直接の正本はユーザー提示仕様。閲覧していない資料を今回検証済みとはしない。

## S9 — ユーザー指定J3候補

Gekkio/gekkio-kicad-libsのAGB 32極ソケットフットプリントを2026-09-27に取得。原本・CC BY 4.0本文を同梱。出典URL、SHA-256、寸法、不整合は[slot_footprint.md](slot_footprint.md)へ記録。実物適合は未検証。

## S10 — PCBA部品とC2特性

2026-09-27にJLCPCB公式のC17630/C17408/C17414/C49678/C15850の商品ページで仕様とBasic区分を確認。Samsung公式製品ページおよび同社特性図を確認。各URLと確認範囲は[pcba_parts.md](pcba_parts.md)へ記録。

## S11 — JP1/JP2の秋月選定

2026-09-27、秋月電子108593/103890商品ページおよび添付メーカー図面を照合。ヘッダ・キャップの定格3A、寸法、推奨穴径、価格と販売単位を[jumper_parts.md](jumper_parts.md)へ記録。

## TP・組立部材（2026-09-27取得・確認）

- KiCad 10.0.5同梱TestPoint_Pad_D2.0mm：F.Cu/F.Maskのみ、φ2mm。https://www.kicad.org/libraries/license/ （標準ライブラリのライセンス）
- https://akizukidenshi.com/catalog/g/g110073/ ：Ronmeeソケット型番と分割使用。嵌合は同日のユーザー回答で確認。
- https://ja.aliexpress.com/item/1005005472303111.html ：ユーザー指定のJ3調達先。ページ本文は取得不可、MPN未確認。
- https://www.sanwa.co.jp/product/syohin?code=TK-CAP6BK ：PE製Type-Cメス用キャップ、寸法・数量。
- https://www.nitto.com/jp/ja/products/construction/protection002/ ：No.21赤色絶縁テープ19mm。
- https://akizukidenshi.com/catalog/g/g101861/ ：樹脂スペーサー14mm×4、ネジ7mm×8のセット。
- https://akizukidenshi.com/goodsaffix/OS-SCREW-3PL-1_oldvsnew_20250321.pdf ：新旧寸法図。現行供給品は販売ページ上Bタイプ。

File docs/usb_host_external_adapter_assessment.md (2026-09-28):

# 外付けUSBホスト給電アダプターの追加調査

調査日: 2026-09-28。検討資料でありV1の採用仕様・動作確認済みBOMではない。PC通信UART0→CH343を維持。PCB、BOM、シルク、製造状態は変更しない。

## 結論

外部5VでUSB機器を給電し、ESP32-S3のNative USBをホストとして使う方法には公開事例がある。一方、WeAct ESP32S3-A N16R2＋下記市販アダプター＋USBメモリの組合せを検証した一次資料は今回の検索では確認できなかった。したがって「基板無改造で評価可能な候補」であり、「購入して挿すだけで動作保証」とはしない。

## 動作実績の範囲

1. Espressif ESP-IDF v5.5のMSCホスト公式例はESP32-S3対象を明記し、USBメモリ上の作成・読出し・書込みを実装。FATを対象とする。READMEの速度例をESP32-S3の実測値として転用しない（複数チップ向け）。[公式MSC例](https://github.com/espressif/esp-idf/blob/v5.5/examples/peripherals/usb/host/msc/README.md)
2. K7MDL2のIC-905 Band DecoderはESP32-S3でUSB-UARTとUSBホストを併用する実動プロジェクト。非給電OTG端子にはYケーブル等による5V追加が必要と説明。ただし周辺機器は無線機のCDC/VCPで、USBメモリではない。筆者が最終的に1kΩジャンパを使用した記述もあり、Yケーブル単体の型式付き実測保証とは扱わない。無線機のVBUS検知向け1kΩ接続はバス給電USBメモリへ流用しない。[作者README](https://github.com/K7MDL2/IC-905_Band_Decoder_on_ESP32-S3/blob/main/README.md)
3. touchgadgetのUSBホスト実験ではUSBブレークアウトへの別5V供給、ケーブルVBUSを切り離す接続方法と動作例を公開。対象はESP32-S2・MIDI等であり、S3＋MSCの直接実績ではない。[作者README](https://github.com/touchgadget/esp32-usb-host-demos)

## WeAct回路に対する判断

保存済み公式ESP32_S3_A_Sch.pdf（SHA-256 ad44dcae89c68d47c769958268a52bd499d6cb76730602efbe738c1fd79d63f7）のUSB2がNative USB。GPIO19=D−、GPIO20=D+。D5はUSB2 VBUS→基板+5V方向で、基板+5V→USB2へは給電できない。CC1/CC2はR4/R8の5.1kΩでGNDへ接続。USB-Cホスト用のRp・電源供給制御はない。

[公式Hardware](https://github.com/WeActStudio/WeActStudio.ESP32S3-AorB/tree/main/ESP32S3-A/Hardware) / [保存回路図](../hardware/reference/weact/README.md)

ESP-IDF v5.5のusb_phy_otg_set_mode()はHOST時にIDDIG、VBUSVALID、AVALIDを内部定数へ接続し、ホスト動作を設定する。従ってWeAct Native端子のVBUSを給電しない構成でも、外部給電した機器とD+/D−で通信する技術的根拠はある。ただしファームウェアによる固定ホスト設定はType-CのCC制御を追加するものではない。[Espressif実装](https://github.com/espressif/esp-idf/blob/v5.5/components/usb/usb_phy.c)

## 具体的な市販候補

|役割|製品|確認済み|残る確認|
|---|---|---|---|
|Type-C→A変換|StarTech USB31CAADGCP|メーカー資料でPassive、USB2.0互換、Type-Cオス→Aメス|WeActでの接続実測、内部回路図は未確認|
|VBUS遮断|PortaPow USB Power Blocker / PPUSBBP1|メーカーがD+/D−/GNDを通し5Vを遮断、USB2.0対応と明記|実物導通と電源投入時の遮断確認。メーカーも機器によって通信不可と注記|
|USBメモリへ外部5V注入|Comprehensive USB3-AMF-PT|USB-Aホスト側オス／機器側メス／電源側オス、USB1.1/2.0/3.0、最大5V 0.9A、Bulk対応|内部回路・逆流防止・電流制限特性は公開記述から確定できない。ホスト側VBUSなしで機能するか確認が必要|

メーカー資料:
- [StarTech USB31CAADGCPデータシート](https://media.startech.com/cms/pdfs/usb31caadgcp_datasheet.pdf)
- [PortaPow PPUSBBP1](https://portablepowersupplies.co.uk/product/usb-power-blocker)
- [Comprehensive USB3-AMF-PT](https://comprehensiveco.com/products/usb-3-0-power-injector-adapter-cable-with-up-to-5gbps-data-transfer.html)

価格比較・国内調達確定・購入は未実施。Comprehensiveの0.9Aは表示上の最大仕様であり、過電流遮断値や各USBメモリの利用可能電流を保証しない。インジェクターの逆流防止を推測せず、別のVBUS遮断器でWeAct側への電源経路を断つ。

## 基板無改造で評価する接続案（未検証）

```text
PC または5V電源 ── WeAct UART端子（従来どおり）

WeAct Native USB-C
  └─ USB31CAADGCP
       └─ PPUSBBP1（ここでVBUSを遮断。D+/D−/GNDのみ通す）
            └─ USB3-AMF-PTのHOST側
                 ├─ DEVICE側 ── USB-Aメモリ
                 └─ POWER側  ── 保護された安定化5V電源
```

WeActへの外部5V逆給電と、PC電源・USBメモリ電源の直接並列を遮断する。GNDは共通で、ガルバニック絶縁ではない。電源は5V固定、必要な過電流保護を備えたものとする。ハブを介さないため、機器が単一MSCならハブドライバーを不要にできる構成。

この構成はNative Type-Cの標準的な接続・電源役割交渉によるものではなく、データ線を利用してS3を固定ホストにする専用評価接続。WeAct側Rdは変わらず、C→Aアダプターを挿しても標準準拠のType-Cホストにはならない。汎用スマートフォンOTG、PDパススルー、Type-Cハブの動作へ一般化しない。[TIのCC役割説明](https://www.ti.com/product/TUSB322I)

## 回路を明確にした自作外付け案

市販インジェクターがホストVBUSを必要とする場合は、外付けケーブル／小基板を製作すれば接続を明確にできる。WeActやGBA親基板を改造する必要はない。

- Native側D−→USB-Aメモリ端子2、D+→端子3、GND→端子4。
- Native側VBUSはメモリのVBUSへ接続しない。
- 外部安定化5V→電流制限付きUSB電源スイッチ→メモリ端子1。
- メモリ電源のコンデンサと必要なESD保護、シールド・短いUSBデータ配線を用意する。
- EspressifのESP32-S3-USB-OTGにはMIC2005Aを使った500mA電流制限回路の公開例がある。これを回路参考とするが、部品・容量・ENの接続を確定した完成設計は今回作成していない。[公式給電回路説明](https://docs.espressif.com/projects/esp-dev-kits/en/latest/esp32s3/esp32-s3-usb-otg/user_guide.html)

## 採用前の評価条件

1. 無通電でD+/D−/GND導通、VBUSの確実な遮断を確認。
2. WeAct/カートリッジへ接続する前に、外部給電でメモリ側5V・Native側への非給電を測定。PC側から外部電源コネクタへの逆供給も確認。
3. S3をUSBホストに固定し、MSC公式例で認識・ファイル書込み・読戻し・ハッシュ一致を検証。消去してよい検証用FAT32メモリを使う。
4. Cプラグ両向き、電源投入順、挿抜、突入時電圧、連続書込みを確認。基板OFF時はメモリ側も切り、データ線経由の部分給電を避ける。
5. その後GBA読出しと組み合わせ、チャンク境界でバスを非選択にしてファイル書込み。USB切断・電源断時に完了扱いにしない。

セルフパワーハブは外部電源があるだけでは成立を保証できない。上流VBUS検知で接続を拒む製品があり、Type-CハブはCC/PD条件も増える。現状では具体的な検証済みハブを採用候補に確定しない。

判断: ハード改版前に上記の外付け構成で単体PoCを行う価値はある。現行PCBへの部品追加は必須とまでは言えないが、未検証のためUSBメモリ保存対応済みとは表示しない。

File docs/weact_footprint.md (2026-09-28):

# WeAct N16R2のソケットと機械条件

公式ESP32S3-A外形図と回路図はhardware/reference/weactへ原本保存。各列22極・ピッチ2.54 mm・列中心間27.94 mm、端子列長53.34 mm。上面視でアンテナ上・USB下、左J1/右J2、上から1〜22の独自番号。モジュール端子番号と区別する。

J1/J2は `GBA_Mechanical:PinSocket_1x22_P2.54mm_D1.02mm`。穴径1.02 mm、パッド1.70 mm、1番矩形。2.54 mmピッチの22極形状を生成し、公式の列間隔で配置。旧20極の電気接続を流用しない。

採用品はRonmee FH2.54-40U1GF8.5-0.5（秋月110073）。40極品を2本購入し、各1本から22極を切り出す。計44極実装、余り各18極。メーカー/販売ページのピッチ2.54 mm、ハウジング高さ8.5 mm、推奨実装穴1.02 mmを2026-09-28再確認。細ピン用なのでWeAct付属ヘッダとの嵌合は未確認。FNK0099での嵌合確認をWeActへ転記しない。

[販売ページ](https://akizukidenshi.com/catalog/g/g110073/)

公式図の本体外形62.756×31.242 mm、アンテナ側の突出6.040 mm、モジュール幅18.017 mm。USB側の突出を除く長さ68.796 mm。端子中心と基板端のオフセットのうち幅方向1.651 mmは図示値。長手方向の1番端子〜アンテナ側基板端約4.865 mmは図の形状からの読み取り値であり、公差付きの寸法指示ではない。Dwgs.Userの外形配置はこの読み取り値を用いた配置レビュー用。到着時に照合する。

ユーザーから販売業者確認として、下面部品なし、USB位置・実装高さはFNK0099と同様との条件を受領。基板間隔最低2.5 mm・目標3.0 mm以上を組立検査の条件として維持する。下面のはんだ・端子突出にも接触しないこと。ハウジング高さをそのまま基板間隔と扱わない。

前のFNK0099配置に対するユーザー確認は新配置の実機検証とはしない。新しい配置はpcb_placement.mdと配置画像でレビューする。

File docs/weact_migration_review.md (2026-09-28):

# WeAct移行レビュー — 4層配線直前の履歴

この記録は前工程（797bb73/ef14fae）。現在は4層配線と比較まで完了し、最新状態は[routing.md](routing.md)を参照。

2026-09-28。ユーザーと合意した区切りまで実施。**未配線・実機未検証・製造不可。**

- 回路図52部品と28 GPIOを変更。公式22極端子配列と独立テストで照合。AH=[1,35,36,38,39,40,41,42]、/WR=37。他のGBA信号番号・抵抗値・JP1保護構造は維持。
- ERC 0件、ピン配列C++17コンパイル成功、PCBA 5品種35個と手はんだBOMの照合成功。
- 新22極フットプリント、列間27.94 mm。固定穴4個とJ3の形状は維持。配置チェックは全パッドネット・部品UUID・ネジ銅箔離隔を照合。
- DRC違反0、未配線90接続、回路図不一致0。トラック0・ビア0・銅箔ゾーン0。GND面は次工程で作成。
- 回路図とPCB配置のSVG/PNGを作成。旧FNK0099の出力・検査・座標依存スクリプトをarchive/fnk0099へ分離。旧mainの6403600を保持。
- 40極ソケットは2本購入し各22極を切出し。GPIO19/20非使用のためNative USB封止キャップ・テープを必須BOMから除外。WeAct本体の改造なし。

## レビュー上の注意

外形寸法は公式図、未寸法の長手方向起点は図からの読み取り。USB側本体は親基板より約2.4 mm外へ出す配置。無線不使用V1としてアンテナ投影直下の銅箔を禁止し、RF性能を保証する周囲15 mm空間は確保していない。これらを含む配置の詳細はpcb_placement.md。

到着品の細ピンソケット嵌合・USBプラグ空間・起動と給電試験は未完了。旧FNK版のユーザー確認やDRC合格を新基板の実物検証へ転用しない。詳細はopen_items.md。

2026-09-28、ユーザーから「配置含めて問題ありません」と回答を受領。コミット `797bb73` の設計変更・現配置のレビューを完了し、配置レビュー待ちを解除した。到着品の実物検証は別途残る。

次工程は4層配線。今回は確認記録のコミットのみで、配線には着手しない。配線スクリプトはWeAct座標へ適合させてから使用し、旧FNK版のスクリプトを直接実行しない。Gerber・ドリル・CPLは配線と検査の完了後に再作成する。

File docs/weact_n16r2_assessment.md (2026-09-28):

# WeAct ESP32S3-A N16R2への移行検討

## 状態（2026-09-28）

ユーザーがAliExpressで発注済み。販売業者への問い合わせ結果をユーザーから受領し、以下を移行設計の入力条件として採用する。到着品の実測・電気試験を完了した記録ではない。本節は調査時点の記録。その後ユーザー承認によりWeAct版へ移行し、配線前までの更新を実施。現在の状態はweact_migration_review.md参照。

## 機械条件

|項目|受領した条件|
|---|---|
|長手方向|FNK0099比 +5.08 mm（各列2極増加、20極→22極）|
|短手方向|FNK0099比 +2.54 mm（1ピッチ広がる）|
|下面部品|なし|
|USB位置|FNK0099と同様|
|実装高さ|FNK0099と同様|

ソケットピッチ2.54 mmの場合、各列の1番〜22番の中心距離は53.34 mm。列中心間は、現行25.40 mmに2.54 mmを加えた27.94 mmを移行設計の想定とする（「短手方向1ピッチ増」を列間隔にも適用した値）。基板外形幅と列中心間は別の寸法として扱い、到着時に照合する。現行図のFNK0099占有枠は厳密な基板外形寸法ではないため、その枠からWeActの絶対外形寸法を断定しない。

USB位置が同様との回答はケーブル取り回しの設計条件として採用する。22極ヘッダの1番端子を基準にしたUSB・外形・アンテナ位置の座標は、フットプリント作成時に資料と照合する。下面部品なしは受領条件として確定し、はんだ突出やソケットによる組立後の間隔は別途確認する。

## 公式外形図との照合（2026-09-28）

GitHubの[ESP32S3-A Board Shape 外形.pdf](https://github.com/WeActStudio/WeActStudio.ESP32S3-AorB/blob/main/ESP32S3-A/Hardware/ESP32S3-A%20Board%20Shape%20%E5%A4%96%E5%BD%A2.pdf)を描画して確認した。

|寸法|公式図の値・読み取り|既存設計との照合|
|---|---|---|
|端子ピッチ|2.540 mm|一致|
|左右列中心間|27.940 mm|現行25.40 mm比+2.54 mm、想定を公式図で確認|
|端子数|各列22極|現行20極比+2極|
|端子列の端から端の中心距離|53.34 mm（21×2.54から算出）|現行48.26 mm比+5.08 mm|
|基板本体の長さ|62.756 mm|FNK0099の厳密な外形基準値が未記録のため外形長差は未照合|
|基板本体の幅|31.242 mm|同上、外形幅差は未照合|
|アンテナ側のモジュール突出|6.040 mm|基板長に加えると68.796 mm。USB側突出はこの合計に含めない|

販売業者回答の「2極増・1ピッチ広がる」は端子配置として公式図と一致する。一方、基板外形そのものがFNK0099比で正確に+5.08/+2.54 mmであることまでは、比較元の公式外形寸法なしに確定しない。前述の列間隔27.94 mmは想定から公式図確認済みへ更新する。

この図は上面の外形・部品配置図であり、下面部品なし・実装高さが同一であることは検証できない。USB位置の厳密な比較寸法も記載されていない。これらは販売業者確認という出典を維持する。

## 電気的な移行案

N16R2は2 MB Quad SPI PSRAM搭載であり、N16R8のOctal SPI PSRAMによるGPIO35〜37占有とは異なる。WeAct ESP32S3-Aの公開回路図ではGPIO35〜37はヘッダへ接続され、GPIO2にはLED負荷がない。GPIO48のRGB LEDとGPIO19/20のNative USBをバスから外すことで、部品取り外し・パターンカットなしの構成を目指す。

```text
AD[0..15] = [4,5,6,7,8,9,10,11,12,13,14,15,16,17,18,21]
AH[0..7]  = [1,35,36,38,39,40,41,42]
/CS=47, /RD=2, /WR=37, /CS2=3
UART TX=43, RX=44
```

28本の重複なしを機械的に確認済み。現行案との差はA17/D1:19→35、A18/D2:20→36、/WR:48→37。GPIO3の起動ストラップ条件と/CS2の10 kΩプルアップは維持する。GPIO0/19/20/43/44/45/46/48はGBAバスに使用しない。現行FNK0099のGPIO35〜37使用禁止は解除せず、この案を別ボード用として管理する。

## 移行時の作業と残る確認

- J1/J2を各22極へ変更し、電源・GNDを含む全端子番号をWeAct回路図に合わせる。既存20極ソケットへの差し替えは不可。
- ソケット型式・フットプリント、配置、アンテナ禁止領域、配線、BOM、ファームウェアのピン定義を改版する。
- 変更後の固定穴・ジャンパ・TP・カートリッジへのアクセスを確認する。従前の配置確認はFNK0099版に対するもの。
- 到着品のN16R2刻印・基板版・端子配列、寸法、ソケット嵌合を照合する。
- GPIO3の電源投入・リセット・UART書込み、全28 GPIOの無負荷試験、制御線の起動波形を確認する。
- 3.3 Vレギュレータとカートリッジ負荷時の電圧・発熱を確認する。5 V・2 A入力だけで給電余裕を確定しない。
- ERC/DRCと出力照合をやり直し、新しいガーバー・ドリル・CPLを生成する。既存製造データはWeAct版には使用しない。

## 根拠

- 機械条件・発注状況：2026-09-28のユーザー回答（販売業者への問い合わせ結果）。
- [WeAct公式リポジトリ](https://github.com/WeActStudio/WeActStudio.ESP32S3-AorB)
- [ESP32S3-A公式回路図](https://github.com/WeActStudio/WeActStudio.ESP32S3-AorB/blob/main/ESP32S3-A/Hardware/ESP32_S3_A_Sch.pdf)
- [Espressifモジュールデータシート](https://www.espressif.com/sites/default/files/documentation/esp32-s3-wroom-1_wroom-1u_datasheet_en.pdf) v1.8、Table 1-1／3-1。

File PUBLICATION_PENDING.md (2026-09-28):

# GitHub公開状況

公開リポジトリ https://github.com/otitbridge/gba-dumper-esp32-s3 は作成済みで、mainへpush済みです。

公開用初回コミット: `dff766035c589fe986bd2bf9e1148445d33679bf`。GitHub側のコミットSHAとの一致を確認済み。元の開発履歴は送信せず、独立した公開履歴で開始しました。

設計・製造データは公開時点のローカル正本と同一で、既存ハードウェア検査は合格しています。文書中の過去コミットIDは非公開開発履歴です。

個人情報・認証情報は既知値と代表パターンの検査で該当なしでした。あらゆる秘密情報の不在を保証する検査ではありません。

ファイル名は従来のPUBLICATION_PENDING.mdを維持していますが、公開待ちではありません。実機未検証の状態は公開後も変わりません。

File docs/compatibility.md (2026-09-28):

# 実機対応表

確認済みの組合せはまだありません。対応目標を動作確認済みとして記載しません。

今後の記録項目: カートリッジ識別、ROM長/SHA-256、SAVE種別/容量/ID、WeAct N16R2刻印・基板版（本設計は無改造）、FW/ESP-IDF版、JP1状態、電圧・波形、読出し/書戻し結果、試験日。

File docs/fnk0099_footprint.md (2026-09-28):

# FNK0099版の履歴資料

この資料は現行WeAct設計には適用しません。

[保存したFNK0099版](../archive/fnk0099/docs/fnk0099_footprint.md)を参照。履歴内の相対リンクは旧mainの構成を前提とします。旧完成設計はGitコミット6403600からも参照できます。

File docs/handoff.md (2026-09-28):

# FNK0099版の履歴資料

この資料は現行WeAct設計には適用しません。

[保存したFNK0099版](../archive/fnk0099/docs/handoff.md)を参照。履歴内の相対リンクは旧mainの構成を前提とします。旧完成設計はGitコミット6403600からも参照できます。

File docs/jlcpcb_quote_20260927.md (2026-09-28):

# FNK0099版の履歴資料

この資料は現行WeAct設計には適用しません。

[保存したFNK0099版](../archive/fnk0099/docs/jlcpcb_quote_20260927.md)を参照。履歴内の相対リンクは旧mainの構成を前提とします。旧完成設計はGitコミット6403600からも参照できます。

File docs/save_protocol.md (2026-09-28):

# SAVEプロトコル — 未確定・未実装

SRAM/FRAM 32KiB、Flash64/128KiB、EEPROM512B/8KiBを独立ドライバで検証する。EEPROMはAD0専用シリアルでありI²CやSRAMルーチンを使わない。

allow_protocol_writesは既知の読出し要求/識別/バンク選択だけ。allow_save_mutationは既定false、種別確認・バックアップとハッシュ保存・明示許可後のみ。未知Flash IDへ消去や試し書きをしない。JP1 OPENでは全SAVE形式を読めない。

メーカー別コマンド、EEPROMビット列、アドレス長、タイムアウト、復帰シーケンスは部品仕様と参照実装を確認後に確定する。既存実装のコピーは未実施。使用時にはライセンスとコミットを記録。書込み後は全量読出し比較し、送信完了を成功判定にしない。

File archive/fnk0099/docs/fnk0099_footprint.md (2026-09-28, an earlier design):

# FNK0099ソケットの採用形状

2026-09-27、ユーザーから「FNK0099は../kariya-iot-pcbのFreenove ESP32-WROOMとフットプリントが同一」と指定。これを根拠として、同プロジェクトのソケットフットプリントと列間隔を採用する。新規実測を実施したという意味ではない。

- 取得元: `../kariya-iot-pcb/kicad/kariya_IoT_PCB.pretty/PinSocket_1x20_P2.54mm_D1.02mm.kicad_mod`
- 元ファイルSHA-256: `38db4e1f582338bfe43e85dd4059aa29d27521afe2348da5d606d1a33de4c56f`
- プロジェクト内コピー: `hardware/lib/GBA_Mechanical.pretty/PinSocket_1x20_P2.54mm_D1.02mm.kicad_mod`（変更なし）
- ライブラリID: `GBA_Mechanical:PinSocket_1x20_P2.54mm_D1.02mm`
- 元プロジェクト資料ではFNK0060B WROVER表記。WROOM対応の記録もあるが、その電気接続は本設計へ流用しない。
- 元形状はKiCad標準PinSocket_1x20_P2.54mm_Verticalから穴径等を調整したもの（元プロジェクトdocs/FOOTPRINT_ASSIGNMENTS.md）。

|寸法・定義|採用値|
|---|---|
|ソケット|1×20を2本、手はんだ|
|ピッチ|2.54 mm|
|1番〜20番の中心距離|48.26 mm|
|左右列の中心距離|25.40 mm|
|完成穴径|1.02 mm|
|パッド|1.70×1.70 mm、1番は矩形、2〜20番は円|
|上面視|アンテナ上、USB下。左J1・右J2、上から1〜20|

## PCB配置時の拘束

PCB上面でJ1 pad1を(X,Y)、J2 pad1を(X+25.40,Y)に置き、両フットプリントを0度とする。各pad nの位置はY+2.54×(n−1)。上面視でY増加方向がUSB側。2つの独立ソケットフットプリントなので、列間隔はフットプリントファイル自体には含まれない。配置時に相対位置を拘束・検査する。

元PCBの配置はJ1=(57.3,70.47)、J2=(82.7,70.47)、どちらも回転0度で25.40mmの列間隔を確認した。絶対座標は今回へ流用しない。

## 実装高さ・下面部品の採用条件

2026-09-27の追加指定「FNK0099の実装高さ・下面部品はkariya-iot-pcbのFreenove ESP32-WROVERと同一」に基づき、以下を設計入力として採用する。高さ・下面部品は未確定事項から外し、組立後の検査項目と区別する。

出典: `../kariya-iot-pcb/docs/MECHANICAL_LAYOUT.md` §4.1〜4.2、`docs/DECISIONS.md` D-012。

|項目|採用値・条件|
|---|---|
|ソケット|FH2.54-40U1GF8.5-0.5、1本を1×20の2本に分割|
|ソケットのハウジング高さ|8.5 mm|
|ボード下面からの最大部品突出|2.0 mm|
|ボード下面〜親基板表面の間隔|最低2.5 mm、目標3.0 mm以上|
|最大下面部品と親基板表面の空隙|最低条件で0.5 mm、目標条件で1.0 mm以上|
|親基板上のボード直下|J1/J2を除く表面実装部品を置かない|

ハウジング高さ8.5 mmを基板間隔そのものとは扱わない。基板間隔はヘッダ・ソケットの嵌合状態を含む組立寸法であり、上記は組立後の受入条件。今回新規実測した数値ではなく、ユーザーの同一性指定と既存設計に基づく。

USB・カートリッジ・アンテナ周辺の全体配置干渉は引き続き確認する。今回の追加指定から基板外形寸法やアンテナの禁止領域までは自動確定しない。

J1/J2へ形状を割当済み。GPIO35〜37 NC、UART43/44などの現行電気配線は維持。Gate3の寸法根拠は前進したが、基板全体の干渉確認・DRCは未完了。

2026-09-27：細ピンソケットとの嵌合についてユーザーから「確認済みです。問題ないです」と回答あり。採用を維持し、BOMへRonmee製FH2.54-40U1GF8.5-0.5／秋月110073を記載した。購入は40極1本、実装は20極2本。

## 現配置の確認（2026-09-27）

ユーザーがFNK0099外形・USB・アンテナ範囲と現PCB配置に問題ないことを確認済み。上記のこれらに関する全体配置干渉確認待ちは解除する。新規採寸値の提供ではなく現配置の成立確認として記録する。対象は[PCB配置記録](pcb_placement.md)を参照。

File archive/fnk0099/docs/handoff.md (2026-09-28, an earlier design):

# 引き継ぎ仕様の実装用要約

出典: ユーザーが2026-09-27に本タスクへ提示した「GBA専用ダンパー V1 — FNK0099 N16R8 / Codex・KiCad引き継ぎ仕様」全14章。**このファイルは原文の逐語保存ではなく要約。原文と食い違う場合は提示原文と最後の改造許容追記を優先する。**

- 識別子FNK0099_GBA_DIRECT_V1_20260927。GPIO割付はpinmap.mdおよびpinmap.hppへ転記。
- FNK0099 N16R8を1台使用。最後の追記により搭載表面実装部品の取り外し改造を許容。対象は未確定。
- GPIO35〜37はPSRAM無効化後も使用禁止。0/45/46も不使用、43/44はCH343 UART専用。
- GBA専用3.3V・32極、AD16+AH8+制御4本。GB/GBC/SFC、特殊機能、ROM書換えは対象外。
- R1〜24=330Ω、R25〜28=100Ω、R29〜32=10kΩでCART_3V3へ制御プルアップ。R33=10kΩでPHIをGNDへ。/REQはTPのみ。
- JP1はR27後段、初期OPEN。R31はJP1後段。JP2は3.3V電流測定・切離し用、通常CLOSE。C1=100nF/C2=10µF。
- Native USB端子を封止し使用禁止表示。GPIO19/20を通常GPIO化。RGB/LEDライブラリを起動しない。
- 電源投入前に装着。カートリッジ、ジャンパ、FNK0099の挿抜は全体無給電で行う。別電源並列・5V給電を禁止。
- まず無負荷→192Bヘッダ→ROMを2回取得・SHA-256比較→SAVE読出し→許可後の書戻し。
- バス所有者は単一タスク。制御ラッチHIGHを先に用意し、出力有効化。AD/AH待機時入力・内部プルなし。/CSと/CS2同時選択を禁止。
- ROMはバイトオフセット/2を24bitワードアドレスとして出力。読出しはlittle endian。1ワード毎に/CS解除し、方向切替前後に待機。
- 初期評価待機は設定/保持/切替/終了各1µs、/RD後2µs程度。保証値ではない。UART待ちを選択中にしない。
- ROM長1/2/4/8/16/32MiBは明示指定又は検証済情報。ヘッダだけでサイズ断定しない。未実装領域とEEPROM重複に注意。
- ESP-IDF+C/C++、16MB Flash、PSRAMなし、無線なし、内部RAM約4KiB、UART0 TX43/RX44 115200 8N1 フロー制御なし。921600は検証後の目標。
- SAVEはSRAM/FRAM 32KiB、Flash64/128KiB、EEPROM512B/8KiBを別ドライバで対応目標。未知SAVEへ試し書き禁止。
- allow_protocol_writesとallow_save_mutationを分離。後者は初期false、バックアップ・種別確認・利用者の明示許可が必要。書戻し後は全量比較。
- チャンク版/種別/連番/絶対offset/長さ/CRC、ACK再送、ABORT、範囲検査、書込み重複実行防止が必要。正式通信仕様は未確定。
- Gate1〜3完了前の発注禁止。機械寸法と実機試験は生成ソフトで代替しない。

現時点の成果は回路図とピンマップ。完成基板、動作FW、確定フットプリントは含まない。

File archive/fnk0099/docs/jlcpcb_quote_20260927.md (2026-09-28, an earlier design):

# JLCPCB製造・実装見積もり

確認日：2026-09-27。JLCPCBの実際の見積画面・注文確定前画面で確認した金額。

**5枚・実装・日本向け送料込みの見積総額：5,286円（1枚あたり約1,057円）。注文送信・支払いは未実施。**

## 見積条件

- 対象：GBA専用ダンパー FNK0099 N16R8。製造データを保存したコミットは `d452ee6`。
- ガーバー：`output/fabrication_review/gba_dumper_gerbers_REVIEW_ONLY.zip`。
- 部品表・座標：同フォルダの `assembly/jlcpcb_bom.csv`、`assembly/jlcpcb_cpl.csv`。
- 基板：FR-4、4層、100×100mm、5枚、厚さ1.6mm、緑、白シルク、鉛フリーHASL。
- 実装：Economic PCBA、上面、5枚。抵抗33個・コンデンサ2個／枚、計175個。
- 5品種すべてBasicとして一致。JLCPCB配置プレビューで部品の位置・向きを目視確認。
- 位置決め穴：JLCPCB追加。追加CAMの確認は別途必要。
- 通常納期：基板3〜4日、実装3〜4日と表示。輸送日数は別。
- 配送：日本、郵便番号[postal-code-redacted]の配送先で計算。見積重量644.7g。
- 別売ステンシルや追加加工などの任意オプションは追加せず、選択可能な配送方法を比較。

## 費用内訳

| 項目 | 5枚分 |
|---|---:|
| 4層基板製造 | 1,257円 |
| 鉛フリーHASL | 833円 |
| 実装セットアップ | 1,295円 |
| 実装用ステンシル | 244円 |
| 部品代（Basic 5品種・計175個） | 198円 |
| SMT実装作業 | 93円 |
| 詳細見積と注文確定前画面の商品計の差額 | 4円 |
| 送料：OCS Express | 1,362円 |
| **合計** | **5,286円** |

詳細見積画面の商品小計は3,920円（基板2,090円＋PCBA1,830円）、注文確定前画面の商品計は3,924円。上表は差額を明示して注文確定前総額と整合させたもので、差額の原因は確認していない。

詳細見積画面にはVia Covering、Panel、Large Size、通常納期の各欄に「¥1」という表示もあったが、それらを加算すると表示小計と一致しないため、確定した追加料金として上表に重ねて計上していない。

部品照合時の行別表示は以下。合算197.80円に対し、費用内訳の部品計は198円と表示された。

| 部品 | JLCPCB番号 | 数量（5枚分） | 行別表示額 |
|---|---|---:|---:|
| C1・100nF | C49678 | 5 | 15.00円 |
| C2・10µF | C15850 | 5 | 61.90円 |
| R1〜R24・330Ω | C17630 | 120 | 92.38円 |
| R25〜R28・100Ω | C17408 | 20 | 13.20円 |
| R29〜R33・10kΩ | C17414 | 25 | 15.32円 |

## 配送比較

| 配送方法 | 送料 | 表示輸送日数 |
|---|---:|---|
| **OCS Express（選択）** | **1,362円** | **4〜6営業日** |
| UPS Worldwide Express Saver | 1,566円 | 2〜4営業日 |
| DHL Express | 2,982円 | 1〜3営業日 |
| S.F Express Economy | 3,002円 | 5〜9営業日 |
| FedEx Express | 3,924円 | 4〜5営業日 |

基板だけの初期見積ではOCS NEPが最安候補だったが、実装後の見積重量644.7gが同サービスの600g上限を超え、最終配送候補には表示されなかった。最終比較ではOCS Expressが最安。

## HASL（鉛入り）への変更時の差額

2026-09-27、JLCPCBで同じ基板条件（4層・100×100mm・厚さ1.6mm・5枚）の表面処理料金を比較した。

| 表面処理 | 追加料金（5枚分） |
|---|---:|
| HASL（鉛入り） | 0円 |
| 鉛フリーHASL | 833円 |

**通常のHASL（鉛入り）なら5枚分で833円安い。送料・実装費などが変わらなければ、総額は5,286円 − 833円 ＝ 4,453円（1枚あたり約891円）となる。**

4,453円は確認済み差額を元の総額から引いた計算値であり、変更後の決済前総額は未確認。カートの仕様は鉛フリーHASLのままで、設計・製造仕様の変更や注文は行っていない。

## 金額に含まないもの・状態

- 配送条件はCPT。輸入時の税金・通関取扱手数料等は別途となる表示であり、上記総額へ含めたとは扱わない。
- FNK0099、J1/J2/J3、JP1/JP2などの手はんだ部品、封止・固定部材、手はんだ作業費は含まない。
- クーポン割引は計上していない。価格・在庫・為替換算・送料は再見積もり時に変動し得る。
- JLCPCBカートへ基板・実装セットを保存し、注文確定前画面まで確認した。**Submit Orderは押していない。注文送信・支払い・製造承認は未実施。**
- 製造前の実機確認と追加CAM確認は引き続き残る。見積取得を製造承認と扱わない。

参照：[JLCPCBカート](https://cart.jlcpcb.com/shopcart/cart)。個別の配送先氏名・番地・電話番号や決済セッションURLは本記録に保存しない。

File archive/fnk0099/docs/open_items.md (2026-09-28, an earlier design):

# 未確定事項 — 発注を止める項目

以下に残る確認項目を管理する。ユーザー指定で採用した寸法と、新規実測・動作検証を区別する。

2026-09-28：WeAct ESP32S3-A N16R2をユーザーが発注済み。販売業者確認の機械条件を[移行検討記録](../../../docs/weact_n16r2_assessment.md)へ反映した。以下は現行FNK0099版の管理表であり、WeAct版の確認状態と混同しない。

|項目|必要な証拠・次の作業|
|---|---|
|FNK0099現物|N16R8刻印、リビジョン、J1/J2論理端子順の導通照合|
|改造対象|GPIO2 LEDとGPIO48 WS2812の回路・部品番号を現物で特定。取り外し前後の写真・導通・負荷を記録|
|GPIO3|JP2装着・R32相当のプルアップで電源投入、リセット、CH343経由の書込み復旧を試験|
|GPIO19/20|Native USB未接続、機能無効化後の入出力と残存負荷を測定。封止はTK-CAP6BK＋赤色No.21を採用、装着・保持確認|
|GPIO39〜42|パッドJTAGを使わず通常GPIOとして動作確認|
|制御線|/CS、/CS2、/WRの起動時HIGHと、/RD駆動時HIGH電圧・立上がり・負荷測定|
|電源|搭載レギュレータ型番・余裕電流・発熱、選定C2（C15850、3.3V時典型約7µF）との適合、実負荷で3.3V維持を確認|
|ソケット|ピッチ2.54mm・列間25.40mm・穴径1.02mmはユーザー指定の既存形状から採用済み。実装高さ・下面部品も追加指定で既存条件を採用済み。J1/J2との嵌合はユーザー確認済み。FNK0099外形・USB・アンテナ範囲と現配置はユーザー確認済み。組立後の基板間隔検査は残る|
|GBAスロット|フットプリントはユーザー裁定で確定・J3へ割当済み。購入先はユーザー指定AliExpress商品1005005472303111。メーカー型番と注文バリエーションは未記録（フットプリント確定を妨げない）|
|機械|FNK0099外形・USB・アンテナ範囲と現配置はユーザー確認済み。配置調整・固定穴・JP1/JP2・TP1〜TP12へのアクセスもユーザー確認済み。残りはカートリッジ挿抜・組立後の固定強度と安定性などの確認|
|PCB|100mm角・4層の仮配置を作成。部品ネット照合済み、未配線以外DRC違反0。FNK0099外形・USB・アンテナ範囲との配置照合はユーザー確認で完了。製造ルール設定済み。配線・連続GND面は作成済み、未配線0・電気幾何エラー0・回路図等価性問題0。シルク整理後のDRC違反0・未配線0・回路図不一致0を確認済み。製造データ出力・出力後の照合と実機検証が残る|
|FW|ESP-IDF版を固定してから無負荷試験FWを実装。現時点ではピン定義のみ|

GPIO2/48の部品を外しても、そのまま検証済みにしない。改造が必要と判明した場合、実機対応表には未改造品と区別した構成を記録する。

## J3確定（2026-09-27）

ユーザー裁定によりGekkio製AGBフットプリントを原本のまま確定採用・J3へ割当。従前の採用保留を解除。[寸法と裁定記録](../../../docs/slot_footprint.md)を参照。

## FNK0099ソケット形状採用（2026-09-27）

ユーザー指定のkariya-iot-pcbからJ1/J2形状と列間隔を採用。[採用記録](fnk0099_footprint.md)を参照。電気接続は流用せず本プロジェクトのピンマップを維持。

## PCBA部品選定完了（2026-09-27）

R1〜R33、C1/C2の5品種35個をBasic・0805で選定し、BOMと回路図へ反映。[選定記録](../../../docs/pcba_parts.md)を参照。発注時の在庫・区分再確認、PCB配線とCPL出力・照合は完了。実機検証は残る（fabrication_review.md参照）。

## TP・封止・脚（2026-09-27）

TP全12点はφ2mmの銅箔パッドを割当済み。親基板の脚は秋月101861、Native USB封止はTK-CAP6BK＋赤色No.21を採用。脚穴の位置とアクセス、ジャンパ・TPへのアクセスはユーザー確認済み。組立後の固定強度・安定性と封止材の保持性は別途確認する。詳細は[機械部材](mechanical_parts.md)。

## FNK0099外形・USB・アンテナ範囲（2026-09-27）

ユーザーが現配置で問題ないことを確認済み。該当範囲の保留を解除し、現配置を維持する。根拠・対象座標・既存図中の仮表記の扱いは[PCB配置記録](pcb_placement.md)を参照。

## 配置・アクセス確認完了（2026-09-27）

現配置の固定穴H1〜H4、JP1/JP2、TP1〜TP12へのアクセスと配置調整について、ユーザーが問題ないことを確認済み。該当する確認待ちを解除し、現配置を維持する。[確認記録](pcb_placement.md)を参照。

## 製造ルール設定（2026-09-27）

[製造ルール](manufacturing_rules.md)を設定済み。現在のDRC記録はmanufacturing_drc.json。未配線86件、シルク高さ68件・線幅52件の警告。エコノミーPCBA用の位置決め穴はJLCPCB追加を基本とし、CAM確認で位置を照合する。M3固定穴とは別物。捨て板・フィデューシャルの注文条件確認も残る。

## 4層配線完了（2026-09-27）

[配線記録](routing.md)を参照。最新検査はrouting_drc.json。未配線0件、電気・幾何エラー0件、回路図等価性問題0件。従前のmanufacturing_drc.jsonとplacement_drc.jsonは配線前の履歴。シルク警告120件・PCBA製造準備・実機確認は残る。

## シルク整理・製造前CADチェック（2026-09-27）

120件のシルク警告を解消。現在のrouting_drc.jsonは違反0・未配線0・回路図不一致0。上記の120警告は以前の履歴であり現在の残件ではない。製造前CADチェックでもPCBA上面35部品・BOM5行の整合を確認。残項目は[製造前レビュー](fabrication_review.md)に記録。

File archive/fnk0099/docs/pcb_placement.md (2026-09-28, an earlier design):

# PCB仮配置 V1

2026-09-27、KiCad 10.0.5で生成・再読込・DRC確認。**仮配置、未配線、製造不可。**

- ネイティブデータ：`hardware/gba_dumper.kicad_pcb`
- 上面確認図：`output/pcb/placement.svg` / `output/pcb/placement.png`
- 配置座標：`hardware/verification/placement.json`
- DRC：`hardware/verification/placement_drc.json`

## 外形・層構成

外形100×100mm、基板厚1.6mmを仮採用。F.Cu / In1.Cu / In2.Cu / B.Cuの4層。内層1を連続GND面とする計画だが、今回銅箔ゾーンや配線は作成していない。積層材・各層厚・表面処理・配線ルールは製造設計段階で確定する。

上面に回路図の全52部品、基板専用の固定穴H1〜H4を配置。PCBA対象の35個は上面に統一。TPは無部品、固定穴はBOM/CPL対象外。

|部品|位置・意図|
|---|---|
|J3|原点(28,27)mm、0°。承認済み形状を変更せず上辺側へ配置。カートリッジの挿抜方向・突出範囲は実物確認対象|
|J1|pad1=(58,46)mm、0°。pad20はY=94.26mm|
|J2|pad1=(83.4,46)mm、0°。列間25.40mm、J1と同じ向き|
|R1〜R16|J1左側、交換・測定可能な配置|
|R17〜R24|J2右側。経路長や交差は配線検討で調整|
|C1/C2|J3電源ピン付近。実配線で電源・GNDループを短くする|
|JP1/JP2|FNK0099下を避けて手操作可能な左側に配置|
|TP1〜TP12|仮の占有範囲外へ配置、信号名を表示。近傍GNDパッドの追加は波形測定位置とともに配線工程で検討|
|H1〜H4|中心(5,5)、(95,5)、(5,95)、(95,95)mm。φ3.2mm NPTH、14mm樹脂脚用|

ネジ周囲8×8mmは配線・ビア・ゾーン禁止。NPTH自体が禁止されないよう領域ではパッド禁止を無効にし、銅箔パッドの侵入は別検査で確認する。部品実体・工具の空間も配置更新時に再確認する。

## FNK0099の機械範囲・配置のユーザー確認

2026-09-27、ユーザーから「仮表示になっているFNK0099外形・USB・アンテナ範囲の確定と配置調整」について「ユーザ側で問題ないことが確認できています」と回答を受領。コミット `e5463f8` の現配置について、FNK0099外形・USB・アンテナ範囲と配置上の成立性をユーザー確認済みとして採用し、この範囲の確認待ちを解除する。追加の配置変更は必要なしとする。

Dwgs.UserのFNK0099占有枠はX=54〜88、Y=35〜100mm。アンテナ用の全銅層禁止領域はX=51〜91、Y=30〜43mm、ソケット間の部品禁止領域はX=60〜81、Y=43〜99mm。これらの設計範囲と現配置を維持する。確認根拠はユーザー回答であり、正確な外形寸法の新規採寸やメーカー指定寸法の独立検証を行った記録ではない。

今回の変更は文書への確認記録で、PCB・生成スクリプト・既存画像のTBD/VERIFY表記は変更していない。これらは確認前の作図注記であり、上記範囲の確認状態は本記録を優先する。Native USB使用禁止の恒久シルクは、製造用シルク整理時に配置する。

今回の確認はFNK0099外形・USB・アンテナ範囲と現配置に適用する。カートリッジ挿抜、固定部・封止材の保持性など、別項目の組立検査や電気的な検証を一括完了とはしない。ジャンパ・固定穴・TPへのアクセスは後述の追加ユーザー確認で完了した。今後部品配置を変更する場合は、変更箇所への影響を確認する。

## 検証結果

- 全52部品のフットプリントと回路図UUIDの対応を照合。
- すべての番号付きパッドのネットをエクスポート済み回路図ネットリストと照合。GPIO35〜37等のNCは維持。
- 外形100mm角、4銅層、列間25.40mm、1〜20ピン間48.26mm、固定穴径とネジ周囲の銅箔パッド離隔を検査。
- KiCad DRC：**未配線以外の違反0、未配線86件**。未配線を除外設定で隠していない。全DRC合格・発注可能という意味ではない。
- SVGをPNGへ変換し、ラベル・上面配置を目視確認。3Dモデル・筐体・カートリッジ形状の検証は未実施。

macOSサンドボックス内ではDRCがGUI初期化時に異常終了したため、許可されたサンドボックス外実行で検査完了した。pcbnewスクリプト実行時にはwxApp関連の診断が出るが、保存後のCLI再読込・SVG出力・DRCと独立検査は成功。

## 再生成

`tools/generate_placement.py` をKiCad同梱Pythonで実行。ネットリストが入力で、既存PCBを上書きするため、手動配置を保存したい場合は実行しない。配線があるPCBは上書き拒否する。生成後にKiCad DRCと `tests/hardware/check_placement.py` を実行する。

次工程は製造ルール設定と配線検討。FNK0099外形・USB・アンテナ範囲の確認待ちは解消済み。カートリッジ挿抜範囲などの残項目とGate1〜3の電気的確認条件は引き続き管理する。

回路図生成器は既存 `.kicad_pro` を上書きしないよう変更した。KiCadが保存したPCBルール・設定を回路図再生成で失わないため。今回のプロジェクト設定はKiCad標準値であり、JLCPCB向け製造ルールの最終設定ではない。

## 配置・固定穴・ジャンパ・TPアクセスのユーザー確認（2026-09-27）

ユーザーから「配置調整、固定穴・ジャンパ・TPへのアクセス確認」について「ユーザ側で問題ないことが確認できています」と回答を受領。現配置の固定穴H1〜H4、JP1/JP2、TP1〜TP12へのアクセスと配置をユーザー確認済みとして記録し、この範囲の確認待ちを解除する。追加の配置調整は不要とする。

確認対象の固定穴は中心(5,5)、(95,5)、(5,95)、(95,95)mm、φ3.2mm丸穴・NPTH。PCBデータは変更していない。根拠はユーザー確認であり、Codexによる新規実測ではない。以後この配置を変更した場合は、変更箇所のアクセスへの影響を確認する。カートリッジ挿抜、封止材の保持性、組立後の固定強度・安定性および電気的な検証は別項目として管理する。

## 配線への引継ぎ（2026-09-27）

現在のPCBは本配置を維持して4層配線済み。本文の未配線86件は仮配置時点の履歴。最新状態はrouting.mdとrouting_drc.jsonを参照。全52部品の位置と回転が維持されたことを再検査済み。

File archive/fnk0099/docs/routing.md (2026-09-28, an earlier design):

# 4層配線 V1

2026-09-27。確認済み配置を維持して配線を完了した。**未配線0件、電気・幾何DRCエラー0件、回路図等価性の問題0件。** シルク文字の既知警告120件と製造前の残項目があるため、発注承認ではない。

## 層構成と結果

|層|用途|配線セグメント数|
|---|---|---:|
|F.Cu|部品面の信号・電源、GND引出し|197|
|In1.Cu|連続GND面、信号トラック禁止|0|
|In2.Cu|信号・電源の主配線|361|
|B.Cu|補助経路・電源|38|

貫通ビア63個、配線総延長約3017mm。信号線は原則0.25mm（一部0.20mm）、電源の配線幅は最小0.50mm以上。集計は `hardware/verification/routing_summary.json`。ネット別延長は分岐を含む総和で、端点間の電気長・伝搬遅延ではない。等長配線・高クロック動作の保証は行っていない。立上げは仕様の低速タイミングから開始する。

GND面は1個の連続した充填領域、面積約8582.84mm²。アンテナ・ネジ周辺の禁止領域と非GND穴の離隔を反映済み。GNDのSMD部品・TP2からビアで接続し、J2/J3のGNDも面へ接続。GND面を信号で分断しないようIn1.Cu上のトラック禁止ルールを追加した。銅箔が連続していることはKiCadの充填ポリゴン数と接続検査で確認したもので、実機信号品質の保証ではない。

## 配置・接続の維持

- 52部品の位置・回転を仮配置座標と照合し、変更なし。M3固定穴・スロット形状・ソケット列間隔も維持。
- 全パッドのネットを回路図ネットリストと独立照合。GPIO35〜37、BOOT/UART等の予約ピンへ配線を追加していない。
- 回路図とPCBの等価性検査に備えてメーカー・型番等の非表示フィールドをPCBへ同期。TPは論理BOMへ含める回路図側の属性と一致させた。PCBA対象から除外する既存BOM/CPL方針は維持。
- H1〜H4を「基板のみ」の属性として明示。穴を電気シンボルとして新設していない。

## 配線手順・ツール

KiCad 10.0.5のDSN/SESインターフェースと、ローカル実行の[Freerouting 2.4.1](https://github.com/freerouting/freerouting/releases/tag/v2.4.1)を使用。JavaランタイムはEclipse Temurin 25.0.4.1+1 JRE、ツール本体は一時フォルダへ配置。配線時はGUI/APIサーバー・利用状況送信を無効にした。配線データを外部配線APIへ送っていない。

`prepare_routing.py` は無配線PCBの作業コピーにGND引出しとA16経路を準備。KiCad DSN出力が「部品だけ禁止」のFNK下面領域を銅箔禁止として出力するため、エクスポート用コピーからその領域だけを除いた。正式PCB上の部品禁止領域は維持。アンテナとネジの銅箔禁止は常に有効。スロット長穴には配線用の追加マージンを設定した。

内層1をルーターの非配線層とし、GND面はKiCad側で追加・充填。長穴の距離不足、細すぎる局所配線、TP9の未接続をKiCad検査で検出・修正した。最終的に `import_routing.py`、`finish_routing.py`、`sync_pcb_metadata.py` とKiCad DRCで仕上げた。製造ルールやDRC除外を緩めて解消していない。

経路入力・出力を `hardware/verification/routing/` に保存。SESはルーター出力であり、TP9補完・局所線幅修正・GND面充填・属性同期前の中間成果物。正本は `hardware/gba_dumper.kicad_pcb`。配線済みPCBを仮配置生成器で上書きしない。再実行する場合は無配線版を別作業コピーで使用する。

## 検証・閲覧

- `hardware/verification/routing_drc.json`：ゾーン再充填、保存、回路図等価性を含む最終DRC。
- `tests/hardware/check_routing.py`：位置・パッドネット・線幅・ビア・内層1・GND領域・DRC結果の照合。
- 既存の回路図、配置、製造設定の検査も合格。
- `output/pcb/routed/routing_overview.png` / `.svg`：4層の上面透視図。B.Cuも裏返さず上面基準で表示。
- `output/pcb/placement.*` は配線前の配置確認図として保存。

残り：シルク文字高さ68件・線幅52件の修正、恒久注意表示の整理、PCBA位置決め穴・捨て板等の製造準備、出図前の最終確認、ガーバー／ドリル／BOM・CPL出力。Gate1〜3の実機確認条件は引き続き管理する。

使用ツールのSHA-256：

- Freerouting JAR: `251101c3eeac22d7e7dfcf6796603279e5d1000283eb82d8f093780f7afc6aa9`
- Temurin JRE配布アーカイブ: `5b02bcc908da092e7e00b9772d4f9bbb87f44a60b7c90f7cf5a91a1d98f37e1b`

## シルク整理後の状態（2026-09-27）

既存120警告を解消し、現在のrouting_drc.jsonは違反0・未配線0・回路図等価性問題0。配線・ビア・パッドの形状とネット、全部品位置が配線完了コミット8d5587cと一致することを照合した。本文の120警告は整理前の履歴。[製造前レビュー](fabrication_review.md)を参照。

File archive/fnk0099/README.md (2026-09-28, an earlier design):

# FNK0099 N16R8の履歴専用

WeAct版に使用禁止。mainの6403600までの回路・製造出力・検査結果を保存。内部の相対リンクは旧構成のまま。現行WeAct版は未配線、製造出力なし。

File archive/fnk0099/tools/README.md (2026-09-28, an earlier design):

FNK0099版の履歴用。ハードコードした座標・シルク条件を含むためWeAct版には実行しない。Git 6403600の旧ディレクトリ構成用。次工程でWeAct向けに適合させる。

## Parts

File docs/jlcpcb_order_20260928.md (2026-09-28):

# WeAct版 JLCPCB注文記録 — 2026-09-28

**注文番号：[order-id-redacted]／注文総額：4,609円。**

ユーザーから「注文完了」と注文番号・金額の報告を受領。注文の確定操作はユーザーが実施した。注文完了の根拠はユーザー報告であり、注文履歴・決済明細・製造進捗を別途取得した記録ではない。

## 注文内容

- WeAct ESP32S3-A N16R2用GBAダンパー親基板、5枚。
- FR-4、100×100 mm、4層、厚さ1.6 mm、外層1 oz・内層0.5 oz、緑マスク・白シルク。
- ランド表面仕上げ：HASL(with lead)、鉛含有HASL。
- Economic PCBA、上面35部品×5枚＝175部品。R1〜R33・C1/C2、5品種すべてBasicとして一致確認。
- J1/J2/J3/JP1/JP2は手はんだ。子基板・スロット等の別途調達費は今回の金額に含めない。
- 配送：OCS Express。画面の輸送目安は4〜6営業日で、製造日数を含まない。
- 注文準備対象はWeAct版のカート項目Y6。旧FNK版Y5は今回のチェックアウト対象から除外した。

## 金額

|項目|金額|
|---|---:|
|基板5枚＋PCBA・部品代（最終チェックアウト）|3,243円|
|送料：OCS Express|1,366円|
|**注文総額（ユーザー報告と一致）**|**4,609円**|

想定4,500円との差は＋109円。到着時に税・通関手数料等が発生する場合は別途とする配送条件だった。

### PCBA見積画面の参考内訳

|項目|表示額|
|---|---:|
|裸基板5枚|1,261円|
|実装セットアップ費|1,298円|
|ステンシル費|244円|
|部品代（175個）|199円|
|SMT実装作業費|94円|
|窒素リフロー費|143円|
|上記の単純合計|3,239円|

PCBA見積画面の集計は3,240円、最終チェックアウトの商品合計は3,243円だった。表示項目の単純合計との相違理由は未確認。円換算・端数処理等と断定せず、注文総額は最終チェックアウトおよびユーザー報告の4,609円を採用する。

窒素リフローは設定画面で「Yes (for Economic)」と表示され、143円が計上された。こちらから追加オプションとして選択したものではない。Economicで必須か、解除可能かは未確認。

## 製造データと確認範囲

対象はコミット `20030d6` の[製造出力一式](../output/fabrication_review/README.md)。Gerber・ドリルZIP、BOM、CPLはユーザーがアップロードし、画面でWeAct型番・確定シルク・QRを含むプレビュー、5品種の部品番号、上面35部品の位置・向きを確認した。

出力一式のREVIEW_ONLY表記とmanifestは、出力時点の検査記録として変更しない。本注文記録を後続の発注実績とする。メーカーによる最終CAM・DFM確認済みとは扱わない。

発注完了によって、[未完了事項](open_items.md)の到着品照合・ソケット嵌合・GPIO起動試験・電源評価が検証済みになるわけではない。元のGate 1〜3の未確認項目を残した状態でユーザーが発注を完了した事実を記録する。以後はメーカー確認事項への対応、到着品検査、手はんだ組立、無負荷試験・ROM読出しの順に進める。

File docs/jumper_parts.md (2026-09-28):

# JP1・JP2の部品選定 — 2026-09-27

ユーザー合意の2.54mmピッチ・1×2ピンヘッダ＋着脱キャップ方式を採用。JP1/JP2は同一部品とし手はんだする。購入操作は未実施。

|用途|メーカー・型番|秋月販売コード|1基板分|販売単位・確認時価格|
|---|---|---|---:|---|
|JP1・JP2ヘッダ|Chang Enn PH-1X2SG|[108593](https://akizukidenshi.com/catalog/g/g108593/)|2個|10個入25円（税込）|
|着脱キャップ|Neltron 2228GG、黒、つまみ付き|[103890](https://akizukidenshi.com/catalog/g/g103890/)|2個|20個入150円（税込）|

両商品とも確認時に在庫あり表示。1基板なら各1パックで足り、商品合計175円（送料別）。価格・在庫は注文時に再確認する。JP1用キャップは初期状態では装着せず保管し、JP2用だけ装着する。初期OPENはヘッダ自体を未実装にする意味ではない。

## 寸法・定格確認

- ヘッダ: 2.54mmピッチ、0.64mm角ピン、定格3A、接触抵抗20mΩ以下。推奨完成穴径1.02mm。ハウジング約5.08×2.5mm、高さ約2.5mm、基板側リード3.0±0.25mm。
- ヘッダの差込み側長さは商品欄6.1mm、[メーカー図面](https://akizukidenshi.com/goodsaffix/PH-1xXXSG_20260114.pdf)6.00±0.25mm。図面の寸法公差範囲で扱い、6.1mmを独立した厳密値としない。
- キャップ: 2.54mmピッチ、外形約5.0×2.44×13.5mm。メーカーの[2228XGシリーズ図面](https://akizukidenshi.com/goodsaffix/2228XG-XX.pdf)に定格3A AC/DC、接触抵抗30mΩ以下、2228GGつまみ付き形状を確認。
- 図面上の規格・構造から組合せを選定。実物での嵌合・着脱・導通確認は組立受入時に実施する。3A定格はWeActの3.3V出力が3A供給できるという意味ではない。

## フットプリントと接続

`GBA_Mechanical:PinHeader_1x02_P2.54mm_D1.02mm`をJP1/JP2へ割当。KiCad 10.0.5標準`Connector_PinHeader_2.54mm:PinHeader_1x02_P2.54mm_Vertical`を元に、穴径のみ1.00→1.02mmへ変更。パッドは1.70mm、pad1は矩形、中心は(0,0)/(0,2.54)。元形状の出典はKiCad同梱ライブラリ（kicad-footprints、CC-BY-SA-4.0 with KiCad libraries exception）。3Dモデルは標準ヘッダの参考表示で、キャップの高さは含まれない。

|部品|pad1|pad2|初期状態|
|---|---|---|---|
|JP1|WR_LINK（R27後段）|CART_nWR|OPEN、キャップ別保管|
|JP2|BOARD_3V3|CART_3V3|CLOSE、キャップ装着|

## 配置・運用

キャップ底面がヘッダハウジング上に近接すると、親基板面から約16mmの高さになる。これは概算。高さ公差・完全嵌合位置と着脱空間は配置レビューで確認し、WeAct下、カートリッジ下、USBプラグの通路には置かない。つまみを指で掴め、JP2の2ピンへ絶縁付き測定リードを接続できる空間を確保する。

JP1はWR ENABLE、JP2はPOWER LINK - REMOVE USB FIRSTと表示。操作は必ずUSB電源を抜いてから行う。JP2で電流測定する際も、無給電でキャップを外し電流計を直列接続してから給電し、再び無給電にして復旧する。JP1の状態をソフトで検出できるとはしない。

## BOM

全体BOMにはJP1/JP2のMPN・秋月販売コード・フットプリントを記録。`hardware/bom/akizuki_jumpers.csv`はヘッダとキャップの購入表。キャップは回路図の追加部品ではなく着脱付属品として扱う。JLCPCB PCBA BOMは5種類35個のまま。

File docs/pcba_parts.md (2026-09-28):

# PCBA受動部品選定 — 2026-09-27

抵抗33個とコンデンサ2個、計5種類35個を選定。全て0805、JLCPCB商品ページでBasicおよびEconomic and Standard対応を確認。片面SMTとし、J1/J2/J3およびJP1/JP2は手はんだ、TPは露出パッドとしてPCBA部品から除外する。

|Ref|数量|値・定格|メーカー型番|LCSC・根拠|
|---|---:|---|---|---|
|R1〜R24|24|330 Ω、1%、125 mW|UNI-ROYAL 0805W8F3300T5E|[C17630](https://jlcpcb.com/partdetail/C17630)|
|R25〜R28|4|100 Ω、1%、125 mW|UNI-ROYAL 0805W8F1000T5E|[C17408](https://jlcpcb.com/partdetail/0805W8F1000T5E/C17408)|
|R29〜R33|5|10 kΩ、1%、125 mW|UNI-ROYAL 0805W8F1002T5E|[C17414](https://jlcpcb.com/partdetail/0805W8F1002T5E/C17414)|
|C1|1|100 nF、50 V、X7R、10%|YAGEO CC0805KRX7R9BB104|[C49678](https://jlcpcb.com/partdetail/YAGEO-CC0805KRX7R9BB104/C49678)|
|C2|1|10 µF、25 V、X5R、10%|Samsung CL21A106KAYNNNE|[C15850](https://jlcpcb.com/partdetail/CL21A106KAYNNNE/C15850)|

抵抗は最大使用電圧150 V、温度係数±100 ppm/℃の掲載。電圧定格は許容電力の制限を解除しない。3.3 Vが抵抗両端に掛かる場合の計算は330 Ωで33 mW、100 Ωで109 mW、10 kΩで1.09 mW。特に100 Ωは125 mW定格に近い。通常の制御信号は入力負荷であり、この計算は短絡を許容する根拠ではない。GPIO保護はバス方向制御と非選択状態の確保が主対策。

## フットプリント

- 抵抗: `Resistor_SMD:R_0805_2012Metric`
- コンデンサ: `Capacitor_SMD:C_0805_2012Metric`

KiCad 10.0.5同梱の標準SMTパッドを採用。HandSolder拡大パッドではない。R1〜R33/C1/C2に割当済み。メーカー・MPN・LCSC・定格を回路図の非表示プロパティにも記録。J1/J2の既存割付は維持し、J3は後続のユーザー裁定で提示GitHubフットプリントに確定。

## C2のDCバイアスと電源適合

[メーカー製品情報](https://product.samsungsem.com/mlcc/CL21A106KAYNNN.do)で0805、2.00±0.20×1.25±0.20×1.25±0.20 mm、10 µF、25 V、X5Rを確認。

[Samsung特性図（DigiKey配布）](https://media.digikey.com/pdf/Data%20Sheets/Samsung%20PDFs/CL21A106KAYNNNE_Char.pdf)のDC Bias図を視認した。3.3 V付近では容量減少が約30%であり、公称10 µFに対して典型的に約7 µFという読み取り。曲線の概算であり、温度・公差・経時変化・測定AC条件を含む最低容量保証ではない。25 V定格だけを根拠に3.3 V時の容量低下を無視しない。

本仕様の10 µFはPoC初期の公称値なので、本品を選定する。実効10 µF以上という新規要件が生じた場合は容量・サイズを見直す。WeActのレギュレータ型番、セラミック容量追加との安定性、立上がり、対象負荷での電圧低下・発熱は未検証として残す。

## BOMと発注時の確認

- `hardware/bom/selected_parts.json`: 5品種の型番・定格・出典の生成元。
- `hardware/bom/preliminary.csv`: 全52参照部品の一覧。選定部品も実機未検証と明示。
- `hardware/bom/jlcpcb_pcba.csv`: 5行・35個、JLCPCB用Comment/Designator/Footprint/LCSC Part Number形式。

同じMPNでも別LCSC番号にExtended区分の登録があるため、上表のLCSC番号で指定する。Basic区分は確認日時点の掲載であり固定保証ではない。在庫全5品種の数量を確定したとは扱わず、注文数量と実装ロスを含め発注画面で在庫・Basic区分・Economic対応を再確認する。

WeAct版は配線・シルク・DRC・CPL作成と照合まで完了。CPLはoutput/fabrication_review/assembly/jlcpcb_cpl.csv。2026-09-28、注文画面で5品種すべてBasicとして一致確認し、ユーザーが発注完了（[order-id-redacted]、送料込み4,609円）。[注文記録](jlcpcb_order_20260928.md)を参照。実機検証済みとはしない。

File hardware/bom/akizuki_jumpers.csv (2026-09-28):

Usage | MPN | Akizuki Code | Quantity per board | Pack Quantity | Source
JP1,JP2 | PH-1X2SG | 108593 | 2 | 10 | https://akizukidenshi.com/catalog/g/g108593/
JP1 cap supplied loose; JP2 cap installed | 2228GG | 103890 | 2 | 20 | https://akizukidenshi.com/catalog/g/g103890/

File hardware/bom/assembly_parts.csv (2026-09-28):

Usage | MPN | Supplier | Supplier Code | Quantity per board | Pack Quantity | Source | Status
JP1,JP2 | PH-1X2SG | Akizuki | 108593 | 2 | 10 | https://akizukidenshi.com/catalog/g/g108593/ | SELECTED_NOT_BENCH_VERIFIED
JP1 cap supplied loose; JP2 cap installed | 2228GG | Akizuki | 103890 | 2 | 20 | https://akizukidenshi.com/catalog/g/g103890/ | SELECTED_NOT_BENCH_VERIFIED
J1/J2: two 40-way strips, one 22-way socket cut from each | FH2.54-40U1GF8.5-0.5 | Akizuki | 110073 | 2 | 1 | https://akizukidenshi.com/catalog/g/g110073/ | SELECTED_WEACT_MATING_PENDING
J3 | N/A - manufacturer part number not identified | AliExpress | 1005005472303111 | 1 | Listing variant not recorded | https://ja.aliexpress.com/item/1005005472303111.html | FOOTPRINT_APPROVED_USER_SUPPLIED_SOURCE
Carrier feet: four 14mm spacers and four screws; four screws spare | M3 plastic screw 7mm + spacer 14mm set | Akizuki | 101861 | 1 | 4 spacers + 8 screws | https://akizukidenshi.com/catalog/g/g101861/ | SELECTED_LAYOUT_PENDING
MCU daughterboard | WeAct ESP32S3-A ESP32-S3-WROOM-1-N16R2 | AliExpress / user ordered | N/A | 1 | 1 | https://github.com/WeActStudio/WeActStudio.ESP32S3-AorB | ORDERED_USER_20260928_NOT_BENCH_VERIFIED

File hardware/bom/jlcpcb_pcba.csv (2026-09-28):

Comment | Designator | Footprint | LCSC Part Number
330 | R1,R2,R3,R4,R5,R6,R7,R8,R9,R10,R11,R12,R13,R14,R15,R16,R17,R18,R19,R20,R21,R22,R23,R24 | R_0805_2012Metric | C17630
100 | R25,R26,R27,R28 | R_0805_2012Metric | C17408
10k | R29,R30,R31,R32,R33 | R_0805_2012Metric | C17414
100nF | C1 | C_0805_2012Metric | C49678
10uF | C2 | C_0805_2012Metric | C15850

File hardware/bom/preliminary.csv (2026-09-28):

Reference | Value | Footprint | Status | MPN | LCSC Part Number | Rating | Source | Supplier | Supplier Code
J1 | WEACT_LEFT | GBA_Mechanical:PinSocket_1x22_P2.54mm_D1.02mm | SELECTED_WEACT_MATING_PENDING | FH2.54-40U1GF8.5-0.5 |  | 3A; 2.54mm; housing 8.5mm; WeAct header mating pending | https://akizukidenshi.com/catalog/g/g110073/ | Akizuki | 110073
J2 | WEACT_RIGHT | GBA_Mechanical:PinSocket_1x22_P2.54mm_D1.02mm | SELECTED_WEACT_MATING_PENDING | FH2.54-40U1GF8.5-0.5 |  | 3A; 2.54mm; housing 8.5mm; WeAct header mating pending | https://akizukidenshi.com/catalog/g/g110073/ | Akizuki | 110073
J3 | GBA_32_LOGICAL_PINS | Gekkio_Connector_PCBEdge:GameBoy_Cartridge_AGB_1x32_P1.50mm_Socket_Horizontal | FOOTPRINT_APPROVED_USER_SUPPLIED_SOURCE | N/A - manufacturer part number not identified |  | GBA 32 contacts; user-approved footprint; AliExpress item 1005005472303111 | https://ja.aliexpress.com/item/1005005472303111.html | AliExpress | 1005005472303111
R1 | 330 | Resistor_SMD:R_0805_2012Metric | SELECTED_NOT_BENCH_VERIFIED | 0805W8F3300T5E | C17630 | 125mW; 150V; +/-1%; +/-100ppm/C | https://jlcpcb.com/partdetail/0805W8F3300T5E/C17630 | JLCPCB | C17630
R2 | 330 | Resistor_SMD:R_0805_2012Metric | SELECTED_NOT_BENCH_VERIFIED | 0805W8F3300T5E | C17630 | 125mW; 150V; +/-1%; +/-100ppm/C | https://jlcpcb.com/partdetail/0805W8F3300T5E/C17630 | JLCPCB | C17630
R3 | 330 | Resistor_SMD:R_0805_2012Metric | SELECTED_NOT_BENCH_VERIFIED | 0805W8F3300T5E | C17630 | 125mW; 150V; +/-1%; +/-100ppm/C | https://jlcpcb.com/partdetail/0805W8F3300T5E/C17630 | JLCPCB | C17630
R4 | 330 | Resistor_SMD:R_0805_2012Metric | SELECTED_NOT_BENCH_VERIFIED | 0805W8F3300T5E | C17630 | 125mW; 150V; +/-1%; +/-100ppm/C | https://jlcpcb.com/partdetail/0805W8F3300T5E/C17630 | JLCPCB | C17630
R5 | 330 | Resistor_SMD:R_0805_2012Metric | SELECTED_NOT_BENCH_VERIFIED | 0805W8F3300T5E | C17630 | 125mW; 150V; +/-1%; +/-100ppm/C | https://jlcpcb.com/partdetail/0805W8F3300T5E/C17630 | JLCPCB | C17630
R6 | 330 | Resistor_SMD:R_0805_2012Metric | SELECTED_NOT_BENCH_VERIFIED | 0805W8F3300T5E | C17630 | 125mW; 150V; +/-1%; +/-100ppm/C | https://jlcpcb.com/partdetail/0805W8F3300T5E/C17630 | JLCPCB | C17630
R7 | 330 | Resistor_SMD:R_0805_2012Metric | SELECTED_NOT_BENCH_VERIFIED | 0805W8F3300T5E | C17630 | 125mW; 150V; +/-1%; +/-100ppm/C | https://jlcpcb.com/partdetail/0805W8F3300T5E/C17630 | JLCPCB | C17630
R8 | 330 | Resistor_SMD:R_0805_2012Metric | SELECTED_NOT_BENCH_VERIFIED | 0805W8F3300T5E | C17630 | 125mW; 150V; +/-1%; +/-100ppm/C | https://jlcpcb.com/partdetail/0805W8F3300T5E/C17630 | JLCPCB | C17630
R9 | 330 | Resistor_SMD:R_0805_2012Metric | SELECTED_NOT_BENCH_VERIFIED | 0805W8F3300T5E | C17630 | 125mW; 150V; +/-1%; +/-100ppm/C | https://jlcpcb.com/partdetail/0805W8F3300T5E/C17630 | JLCPCB | C17630
R10 | 330 | Resistor_SMD:R_0805_2012Metric | SELECTED_NOT_BENCH_VERIFIED | 0805W8F3300T5E | C17630 | 125mW; 150V; +/-1%; +/-100ppm/C | https://jlcpcb.com/partdetail/0805W8F3300T5E/C17630 | JLCPCB | C17630
R11 | 330 | Resistor_SMD:R_0805_2012Metric | SELECTED_NOT_BENCH_VERIFIED | 0805W8F3300T5E | C17630 | 125mW; 150V; +/-1%; +/-100ppm/C | https://jlcpcb.com/partdetail/0805W8F3300T5E/C17630 | JLCPCB | C17630
R12 | 330 | Resistor_SMD:R_0805_2012Metric | SELECTED_NOT_BENCH_VERIFIED | 0805W8F3300T5E | C17630 | 125mW; 150V; +/-1%; +/-100ppm/C | https://jlcpcb.com/partdetail/0805W8F3300T5E/C17630 | JLCPCB | C17630
R13 | 330 | Resistor_SMD:R_0805_2012Metric | SELECTED_NOT_BENCH_VERIFIED | 0805W8F3300T5E | C17630 | 125mW; 150V; +/-1%; +/-100ppm/C | https://jlcpcb.com/partdetail/0805W8F3300T5E/C17630 | JLCPCB | C17630
R14 | 330 | Resistor_SMD:R_0805_2012Metric | SELECTED_NOT_BENCH_VERIFIED | 0805W8F3300T5E | C17630 | 125mW; 150V; +/-1%; +/-100ppm/C | https://jlcpcb.com/partdetail/0805W8F3300T5E/C17630 | JLCPCB | C17630
R15 | 330 | Resistor_SMD:R_0805_2012Metric | SELECTED_NOT_BENCH_VERIFIED | 0805W8F3300T5E | C17630 | 125mW; 150V; +/-1%; +/-100ppm/C | https://jlcpcb.com/partdetail/0805W8F3300T5E/C17630 | JLCPCB | C17630
R16 | 330 | Resistor_SMD:R_0805_2012Metric | SELECTED_NOT_BENCH_VERIFIED | 0805W8F3300T5E | C17630 | 125mW; 150V; +/-1%; +/-100ppm/C | https://jlcpcb.com/partdetail/0805W8F3300T5E/C17630 | JLCPCB | C17630
R17 | 330 | Resistor_SMD:R_0805_2012Metric | SELECTED_NOT_BENCH_VERIFIED | 0805W8F3300T5E | C17630 | 125mW; 150V; +/-1%; +/-100ppm/C | https://jlcpcb.com/partdetail/0805W8F3300T5E/C17630 | JLCPCB | C17630
R18 | 330 | Resistor_SMD:R_0805_2012Metric | SELECTED_NOT_BENCH_VERIFIED | 0805W8F3300T5E | C17630 | 125mW; 150V; +/-1%; +/-100ppm/C | https://jlcpcb.com/partdetail/0805W8F3300T5E/C17630 | JLCPCB | C17630
R19 | 330 | Resistor_SMD:R_0805_2012Metric | SELECTED_NOT_BENCH_VERIFIED | 0805W8F3300T5E | C17630 | 125mW; 150V; +/-1%; +/-100ppm/C | https://jlcpcb.com/partdetail/0805W8F3300T5E/C17630 | JLCPCB | C17630
R20 | 330 | Resistor_SMD:R_0805_2012Metric | SELECTED_NOT_BENCH_VERIFIED | 0805W8F3300T5E | C17630 | 125mW; 150V; +/-1%; +/-100ppm/C | https://jlcpcb.com/partdetail/0805W8F3300T5E/C17630 | JLCPCB | C17630
R21 | 330 | Resistor_SMD:R_0805_2012Metric | SELECTED_NOT_BENCH_VERIFIED | 0805W8F3300T5E | C17630 | 125mW; 150V; +/-1%; +/-100ppm/C | https://jlcpcb.com/partdetail/0805W8F3300T5E/C17630 | JLCPCB | C17630
R22 | 330 | Resistor_SMD:R_0805_2012Metric | SELECTED_NOT_BENCH_VERIFIED | 0805W8F3300T5E | C17630 | 125mW; 150V; +/-1%; +/-100ppm/C | https://jlcpcb.com/partdetail/0805W8F3300T5E/C17630 | JLCPCB | C17630
R23 | 330 | Resistor_SMD:R_0805_2012Metric | SELECTED_NOT_BENCH_VERIFIED | 0805W8F3300T5E | C17630 | 125mW; 150V; +/-1%; +/-100ppm/C | https://jlcpcb.com/partdetail/0805W8F3300T5E/C17630 | JLCPCB | C17630
R24 | 330 | Resistor_SMD:R_0805_2012Metric | SELECTED_NOT_BENCH_VERIFIED | 0805W8F3300T5E | C17630 | 125mW; 150V; +/-1%; +/-100ppm/C | https://jlcpcb.com/partdetail/0805W8F3300T5E/C17630 | JLCPCB | C17630
R25 | 100 | Resistor_SMD:R_0805_2012Metric | SELECTED_NOT_BENCH_VERIFIED | 0805W8F1000T5E | C17408 | 125mW; 150V; +/-1%; +/-100ppm/C | https://jlcpcb.com/partdetail/0805W8F1000T5E/C17408 | JLCPCB | C17408
R26 | 100 | Resistor_SMD:R_0805_2012Metric | SELECTED_NOT_BENCH_VERIFIED | 0805W8F1000T5E | C17408 | 125mW; 150V; +/-1%; +/-100ppm/C | https://jlcpcb.com/partdetail/0805W8F1000T5E/C17408 | JLCPCB | C17408
R27 | 100 | Resistor_SMD:R_0805_2012Metric | SELECTED_NOT_BENCH_VERIFIED | 0805W8F1000T5E | C17408 | 125mW; 150V; +/-1%; +/-100ppm/C | https://jlcpcb.com/partdetail/0805W8F1000T5E/C17408 | JLCPCB | C17408
R28 | 100 | Resistor_SMD:R_0805_2012Metric | SELECTED_NOT_BENCH_VERIFIED | 0805W8F1000T5E | C17408 | 125mW; 150V; +/-1%; +/-100ppm/C | https://jlcpcb.com/partdetail/0805W8F1000T5E/C17408 | JLCPCB | C17408
JP1 | WR ENABLE / DEFAULT OPEN | GBA_Mechanical:PinHeader_1x02_P2.54mm_D1.02mm | SELECTED_NOT_BENCH_VERIFIED | PH-1X2SG |  | 3A; 2.54mm pitch; 0.64mm square pins | https://akizukidenshi.com/catalog/g/g108593/ | Akizuki | 108593
R29 | 10k | Resistor_SMD:R_0805_2012Metric | SELECTED_NOT_BENCH_VERIFIED | 0805W8F1002T5E | C17414 | 125mW; 150V; +/-1%; +/-100ppm/C | https://jlcpcb.com/partdetail/0805W8F1002T5E/C17414 | JLCPCB | C17414
R30 | 10k | Resistor_SMD:R_0805_2012Metric | SELECTED_NOT_BENCH_VERIFIED | 0805W8F1002T5E | C17414 | 125mW; 150V; +/-1%; +/-100ppm/C | https://jlcpcb.com/partdetail/0805W8F1002T5E/C17414 | JLCPCB | C17414
R31 | 10k | Resistor_SMD:R_0805_2012Metric | SELECTED_NOT_BENCH_VERIFIED | 0805W8F1002T5E | C17414 | 125mW; 150V; +/-1%; +/-100ppm/C | https://jlcpcb.com/partdetail/0805W8F1002T5E/C17414 | JLCPCB | C17414
R32 | 10k | Resistor_SMD:R_0805_2012Metric | SELECTED_NOT_BENCH_VERIFIED | 0805W8F1002T5E | C17414 | 125mW; 150V; +/-1%; +/-100ppm/C | https://jlcpcb.com/partdetail/0805W8F1002T5E/C17414 | JLCPCB | C17414
JP2 | POWER LINK / DEFAULT CLOSED | GBA_Mechanical:PinHeader_1x02_P2.54mm_D1.02mm | SELECTED_NOT_BENCH_VERIFIED | PH-1X2SG |  | 3A; 2.54mm pitch; 0.64mm square pins | https://akizukidenshi.com/catalog/g/g108593/ | Akizuki | 108593
C1 | 100nF | Capacitor_SMD:C_0805_2012Metric | SELECTED_NOT_BENCH_VERIFIED | CC0805KRX7R9BB104 | C49678 | 50V; X7R; +/-10% | https://jlcpcb.com/partdetail/CC0805KRX7R9BB104/C49678 | JLCPCB | C49678
C2 | 10uF | Capacitor_SMD:C_0805_2012Metric | SELECTED_NOT_BENCH_VERIFIED | CL21A106KAYNNNE | C15850 | 25V; X5R; +/-10% | https://jlcpcb.com/partdetail/CL21A106KAYNNNE/C15850 | JLCPCB | C15850
R33 | 10k / PHI pulldown | Resistor_SMD:R_0805_2012Metric | SELECTED_NOT_BENCH_VERIFIED | 0805W8F1002T5E | C17414 | 125mW; 150V; +/-1%; +/-100ppm/C | https://jlcpcb.com/partdetail/0805W8F1002T5E/C17414 | JLCPCB | C17414
TP1 | 3V3 | GBA_Mechanical:TestPoint_Pad_D2.0mm | PCB_FEATURE_NO_PURCHASE
TP2 | GND | GBA_Mechanical:TestPoint_Pad_D2.0mm | PCB_FEATURE_NO_PURCHASE
TP3 | nCS | GBA_Mechanical:TestPoint_Pad_D2.0mm | PCB_FEATURE_NO_PURCHASE
TP4 | nRD | GBA_Mechanical:TestPoint_Pad_D2.0mm | PCB_FEATURE_NO_PURCHASE
TP5 | nWR | GBA_Mechanical:TestPoint_Pad_D2.0mm | PCB_FEATURE_NO_PURCHASE
TP6 | nCS2 | GBA_Mechanical:TestPoint_Pad_D2.0mm | PCB_FEATURE_NO_PURCHASE
TP7 | AD0 | GBA_Mechanical:TestPoint_Pad_D2.0mm | PCB_FEATURE_NO_PURCHASE
TP8 | AD15 | GBA_Mechanical:TestPoint_Pad_D2.0mm | PCB_FEATURE_NO_PURCHASE
TP9 | A16_D0 | GBA_Mechanical:TestPoint_Pad_D2.0mm | PCB_FEATURE_NO_PURCHASE
TP10 | A23_D7 | GBA_Mechanical:TestPoint_Pad_D2.0mm | PCB_FEATURE_NO_PURCHASE
TP11 | PHI | GBA_Mechanical:TestPoint_Pad_D2.0mm | PCB_FEATURE_NO_PURCHASE
TP12 | nREQ | GBA_Mechanical:TestPoint_Pad_D2.0mm | PCB_FEATURE_NO_PURCHASE

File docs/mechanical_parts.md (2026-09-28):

# TP・固定部材・ソケット

WeAct版、2026-09-28。TP1〜12は直径2 mmの露出銅箔パッド。F.Cu＋F.Mask、ペーストなし、穴なし。無部品でPCBA対象外。TP信号はpinmap.mdと回路図で確認。

H1〜4はφ3.2 mm NPTH丸穴。秋月101861のM3樹脂ねじ7 mm＋スペーサ14 mmセット1組（脚4個・ねじ8本、4本余り）を維持。固定穴周囲8 mm角はトラック・ビア・銅箔ゾーン禁止。機械寸法はpcb_placement.md参照。組立後の安定性と固定強度は未確認。

J1/J2は各22極へ変更し、秋月110073を2本購入。weact_footprint.md参照。JP1/JP2のヘッダとキャップはjumper_parts.mdの選定を維持。

GPIO19/20をGBAから外したため、以前のNative USB封止キャップTK-CAP6BKと赤テープNo.21は必須調達品から除外。V1はUART側USBを使用し、二つのUSBから同時給電しない。

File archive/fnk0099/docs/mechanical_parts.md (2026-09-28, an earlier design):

# TP・封止・固定部材の選定

選定日：2026-09-27。部材選定と配置・実機検証を区別する。PCBAは従来の5品種35個、手はんだはJ1/J2/J3/JP1/JP2。封止・脚は手組立。

## テストポイント

TP1〜TP12を `GBA_Mechanical:TestPoint_Pad_D2.0mm` に割当。KiCad 10.0.5同梱 `TestPoint:TestPoint_Pad_D2.0mm` を変更せずローカルへコピー。銅箔φ2.0mm、表面レジスト開口、F.Pasteなし、穴なし、別購入部品なし。KiCad標準ライブラリ由来（CC-BY-SA 4.0＋ライブラリ例外）。

測定針・ポゴピン用。フックを保持するループ端子ではない。PCBでは上面からアクセスでき、ボードやカートリッジで隠れない場所に配置する。TPを信号から長く引き出さず、信号名をシルク表示。波形測定用GNDは測定対象の近傍に追加の同形状パッドを配置する方針とし、追加点はPCB設計時に回路図にも反映する。購入MPN/LCSCが空欄なのは基板そのものの形状だからである。

## BOM補完

- J1/J2：Ronmee FH2.54-40U1GF8.5-0.5、[秋月110073](https://akizukidenshi.com/catalog/g/g110073/)。40極1本を20極2本へ分割。BOM回路図行はJ1とJ2、調達数量は合計1本。細ピン用である点を照会し、ユーザーが嵌合確認済み・問題なしと回答。新規測定結果ではなくユーザー確認として記録。
- J3：[ユーザー指定購入先](https://ja.aliexpress.com/item/1005005472303111.html)、商品番号1005005472303111、必要数1個。追跡パラメータは保存しない。商品本文は取得できず、メーカー型番・注文バリエーション・梱包数は推測しない。商品番号をメーカーMPNと混同しない。確定済みGekkio形状は維持する。
- FNK0099 N16R8本体、ジャンパキャップ、封止材、脚を `assembly_parts.csv` に含めた。TPは調達品に含めない。PCB本体の外形・製造データ・表面処理はレイアウト後に確定する。

## Native USB封止

[サンワサプライTK-CAP6BK](https://www.sanwa.co.jp/product/syohin?code=TK-CAP6BK)を1個使用。PE製、Type-Cメス用、9.8×4×6.5mm、5個入り。導電接点を持つUSBプラグや金属キャップで代用しない。

キャップ装着後、[日東電工No.21](https://www.nitto.com/jp/ja/products/construction/protection002/)赤・19mm×10mの絶縁テープを必要幅へ切り、外側から覆って保持する。1台あたり使用長は実装時に決定。テープ上と基板に `DO NOT CONNECT - GBA BUS` を表示。CH343側ポート、ボタン、アンテナ、発熱部を塞がない。接着剤をコネクタ内部へ注入しない。

これは誤挿入防止用の取り外し可能な封止であり、鍵付きロックではない。USBを抜いて施工し、キャップが浮かずケーブルを挿せないこと・テープが剥がれないことを確認する。TK-CAP6BKのFNK0099への適合は組立確認項目。保持できない場合は封止完了にしない。

## 親基板の固定・脚

[秋月101861](https://akizukidenshi.com/catalog/g/g101861/)「3mmプラネジ(7mm)＋六角スペーサー(14mm)セット」を1セット採用。セットは樹脂ネジ8個・スペーサー4個。4個のスペーサーを親基板の下面脚とし、上面から4個のネジで固定、残り4個は予備。FNK0099と親基板の間隔を決める部品ではない。

PCB設計条件：H1〜H4はM3用φ3.2mm NPTH、銅箔パッドなし。穴中心から半径4mm以上を全部品・配線・全層銅箔の禁止領域として初期確保し、ネジ頭と工具の干渉を確認する。穴中心は基板端から5mm以上離し、支持範囲を広くとる。四隅相当の位置はJ3・USB・アンテナと調整し、基板外形と一緒に確定する。現段階では座標やPCB上の穴は未作成。

寸法資料：[秋月新旧寸法図](https://akizukidenshi.com/goodsaffix/OS-SCREW-3PL-1_oldvsnew_20250321.pdf)。販売ページに2025-09-24以降はBタイプと記載。配置時に実際の供給品の頭径・ネジ長・ねじ込み深さを照合する。樹脂ネジは過締付けしない。脚下端よりリード・はんだが突出しないこと、挿抜時に傾かないことを組立で確認する。

FNK0099はJ1/J2の嵌合で保持する既存方針を維持。ボードに未知の固定穴を仮定してネジを追加しない。GBAスロットは承認フットプリントの構造に従って取り付ける。カートリッジの挿抜時はスロット付近を手で支える。筐体への取付けや挿抜荷重に耐える追加ブラケットは今回の卓上試作構成には含めない。

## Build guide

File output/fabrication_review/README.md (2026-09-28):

# 製造前レビュー用出力

2026-09-28 / KiCad 10.0.5 / WeAct ESP32S3-A N16R2 / PCB正本コミット d64897f。
**REVIEW ONLY — 製造承認前。実機ゲートとメーカー追加CAM確認が残る。**

- [ガーバー・ドリルZIP](gba_dumper_gerbers_REVIEW_ONLY.zip)：11層＋PTH/NPTHドリル。100×100mm、4層。
- [CPL](assembly/jlcpcb_cpl.csv)：上面35個、R1〜R33とC1/C2。
- [BOM](assembly/jlcpcb_bom.csv)：5品種。手はんだ・機構部品を含まない。
- [上面画像](review/gerber_top.png) / [裏面画像](review/gerber_bottom.png)：Gerbonaraによる実出力の再描画。SVGも同じフォルダ。
- [照合結果](review/verification.json) / [SHA-256一覧](manifest.json)。

全データはPCB絶対原点を共有し、Y座標は−100〜0mm。CPLだけを移動・反転しない。
メッキ穴142個、非メッキ穴6個（固定穴4・長穴2）、上面ペースト開口70個を照合済み。
JLCPCB側プレビューでは部品の重なり・向き、追加位置決め穴と銅箔離隔を別途確認する。

## 再生成

プロジェクトルートで以下を実行（kicad-cliはKiCad 10.0.5、prepareはpcbnew対応Python、verifyはGerbonara 1.6.3を使用）。

```sh
kicad-cli pcb export gerbers --layers F.Cu,In1.Cu,In2.Cu,B.Cu,F.Mask,B.Mask,F.Silkscreen,B.Silkscreen,F.Paste,B.Paste,Edge.Cuts --subtract-soldermask --disable-aperture-macros -o output/fabrication_review/gerbers hardware/gba_dumper.kicad_pcb
kicad-cli pcb export drill --format excellon --drill-origin absolute --excellon-units mm --excellon-zeros-format decimal --excellon-oval-format alternate --excellon-separate-th -o output/fabrication_review/gerbers hardware/gba_dumper.kicad_pcb
kicad-cli pcb export pos --side front --format csv --units mm --smd-only --exclude-fp-th --exclude-dnp -o output/fabrication_review/review/kicad_positions.csv hardware/gba_dumper.kicad_pcb
python3 tools/prepare_fabrication_review.py
python3 tools/verify_fabrication_exports.py
```

画像はGerbonara LayerStack.open(gerbers)のto_pretty_svg(side='top'/'bottom')から作成。画像更新後にverifyを再実行しmanifestを更新する。検査スクリプトは現在の部品・形状に限定した照合であり、設計変更時には検査条件も見直す。

## 注文条件・検査記録

表面仕上げは鉛含有HASL、4層・1.6 mm・外層1 oz/内層0.5 oz・緑マスク・白シルク。表面仕上げは注文画面で指定する。PCBAは上面の抵抗・コンデンサ35個のみで、J1/J2/J3/JP1/JP2は手はんだ。旧FNK版の見積額をWeAct版へ流用しない。

DRCは[記録](review/drc.json)のとおり違反・未配線・回路図等価性問題すべて0。実Gerberのシルクを白、背景を暗緑色として[QR確認画像](review/gerber_silk_qr.png)を生成し、予定URLへの復号一致を確認（[記録](review/qr_decode.json)）。画像上の細いQR横線はSVGラスタライズの境界表現で、矩形の座標は接している。実物印刷は未確認。

画像の再生成はtools/render_fabrication_review.py（Gerbonara 1.6.3）でSVGを生成後、sharpでPNG化。画像・文書更新後にverify_fabrication_exports.pyを再実行してmanifestを更新する。

### Gerber jobの扱い

KiCadが生成した.gbrjobは監査用としてgerbersフォルダに残すが、アップロードZIPから除外した。自動メタデータには外形線幅を含む100.1 mm、Finish=None、内層銅厚0.035 mmという既定値が含まれるため。実際の外形中心線は100×100 mm。注文は製造ルール文書の1.6 mm・外層1 oz/内層0.5 oz・鉛含有HASLを指定し、メーカー標準積層を確認する。PCBの積層メタデータはメーカー確定積層を意味しない。

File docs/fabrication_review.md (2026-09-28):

# WeAct N16R2 — 製造データ出力・照合レビュー

2026-09-28。ユーザー指示により鉛含有HASLの文書変更をd64897fでコミット後、WeAct版ガーバー・ドリル・CPLを作成し照合完了。**出力時点では実機未検証・製造承認なし。その後ユーザーが発注完了（下記）。**

## シルク

- R32手前にGBA DUMPER / WEACT ESP32S3-AとS3-WROOM-1-N16R2 / REMOVE USB FIRSTの2行を配置（X=28、Y=96.5/98.3 mm）。旧WEACT ESP32S3-A / N16R2と独立したREMOVE USB FIRSTは削除。
- PC: USB-UARTはユーザー指示により削除。ユーザー指示によりNATIVE USB: UNUSEDは削除し、J1/J2間のUSB側のJ1寄り（X=64、Y=98 mm）へPCを追加。PCは子基板装着時に隠れる可能性がある位置。子基板の下へ隠れる位置を避けた説明表示であり、端子位置を指す矢印ではない。WeActはGPIO19/20非使用のため旧FNKの「GBA BUS接続禁止」は追加しない。
- 中央のJP1 / JP2 / CARTRIDGE表示を削除。各ジャンパの用途表示の上にCARTRIDGEを配置。WR ENABLE / DEFAULT OPEN、POWER LINK / DEFAULT CLOSED、GBA ONLY / 3.3V、全TP信号名と部品番号は維持。
- 可視シルク文字の高さ・幅は1.0 mm以上、線幅0.15 mm以上。パッド・穴との干渉はDRC、表示の重なりと配置は確認画像で点検。部品位置から見た可視性の確認であり、到着実物の組立試験ではない。

[シルク確認PNG](../output/pcb/final_review/front_silk.png) / [SVG](../output/pcb/final_review/front_silk.svg)。上面視、濃紺がシルク、灰色がソルダーマスク開口。閲覧用に色のみ変更し、基板のシルク形状はKiCadから直接出力。

## 最終検証

- 基準コミット2289d84のPCBをhardware/verification/silkscreen/before.kicad_pcbに保存。シルク文字以外の内容が不変であることを機械比較。全銅箔、ビア、GND面、部品配置、パッド、穴、禁止域を維持。
- ゾーン再充填・保存と回路図等価性を含むDRC: 違反0、未配線0、等価性問題0。ルール緩和・違反除外なし。結果はhardware/verification/routing_drc.json。
- ピンマップ/BOM/ERC記録、配置、製造ルール、配線、シルク変更範囲、配線長とファイルハッシュ、C++17ピン定義を照合。
- AD6主経路73.69 mm、総トラック長2901.62 mm、貫通ビア62個を維持。
- hardware/verification/silkscreen/summary.jsonに対象PCBハッシュを保存。final_layout.jsonは今回作成した最終文字配置の検査用スナップショットであり、ユーザーの追加承認や実機検証を意味しない。

## 次工程

WeAct用Gerber・ドリル・CPL出力と照合は完了。[出力一式と検査結果](../output/fabrication_review/README.md)を参照。次は発注前の実機ゲートとJLCPCB側CAM・実装プレビューの確認。Gate1〜3の未完了事項（到着品、嵌合、起動GPIO、電源等）は[未完了事項](open_items.md)に維持し、DRC合格を発注承認へ読み替えない。

旧FNK版レビューは[履歴](../archive/fnk0099/docs/fabrication_review.md)へ分離。

ジャンパ表示は用途を上段、初期状態を下段に統一。JP1はWR ENABLE / DEFAULT OPEN、JP2はPOWER LINK / DEFAULT CLOSED。各表示はCARTRIDGEを最上段に加えた3行構成で、中心と行間2.5 mmを揃えた。

## リポジトリURLとQR

公開URL https://github.com/otitbridge/gba-dumper-esp32-s3 をQRへ格納。リポジトリは作成済みで、公開用初回コミット `dff766035c589fe986bd2bf9e1148445d33679bf` をmainへpush済み。GitHub側のコミットSHAとの一致を確認した。QRの画像復号一致は公開前に確認済みであり、実物の印刷・読取り確認とは区別する。左中央に追加し、表示URLはhttps://を省略してQR左側で4行に折り返す（改行はURLの一部ではない）。

QRは33×33セル、誤り訂正M、セル0.32 mm、周囲4セルの余白を含め13.12 mm角、中心X=29.5 / Y=53.3 mm。白シルクを背景とし、基板色を暗いモジュールに利用する反転シルク。通常の濃紺シルク確認図ではQRの明暗が逆に見える。実基板では白シルクに対して十分に暗いソルダーマスク色を用いる前提。

KiCadの描画を明暗反転したqr_decode_preview.pngからmacOS Visionで完全なURLを復号し一致。結果はhardware/verification/silkscreen/qr_decode.json。画面上の読取り確認であり、実物のシルク印刷・実装後の読取りは未検証。DRC0、銅箔・配置不変。

再生成はKiCad同梱Pythonでtools/add_repository_qr.py（同梱kicad_qrcodeを使用）。既存QRを置換するためのUUID・形状記録はqr.json。白背景の塗りつぶしはF.Silkscreenのみで、銅箔・マスク・ペーストは追加しない。

2026-09-28、ユーザーが「シルクは以上で確定」と承認。URL・QRを含む現行シルクを確定し、コミットする。この時点ではGerber・ドリル・CPL出力は未着手だったが、その後のユーザー指示で作成・照合を実施した。シルク確定は実機検証完了や発注承認を意味しない。

## 表面仕上げの注文指定

2026-09-28のユーザー指定により、裸基板のランド表面仕上げは鉛含有HASL（通常のHASL）とする。鉛フリーHASLではない。注文条件はmanufacturing_rules.mdを正本とし、WeAct版の見積額は別途確認する。HASL指定の変更自体は文書のみ。今回作成したガーバーには表面仕上げの選択は符号化されないため、注文画面で鉛含有HASLを指定する。

## 製造出力照合結果

11層のGerberとPTH/NPTHドリルをZIPへ格納。Gerbonara 1.6.3で再読込みし、100×100 mm外形、4銅層、PTH142個、NPTH6個（丸穴4・長穴2）、上面ペースト70開口をPCBと照合。CPL35部品の座標・回転とBOM5品種が一致。最終DRCは違反0・未配線0・回路図等価性問題0。PCB・配線・確定シルクは変更していない。

実Gerberから上下面PNG/SVGを生成し、上面シルク画像のQRをmacOS Visionで復号、予定URLと一致。実物の印刷品質検証ではない。ZIP、BOM、CPL、検査記録のSHA-256はmanifest.jsonへ記録。

### Gerber jobの扱い

KiCadが生成した.gbrjobは監査用としてgerbersフォルダに残すが、アップロードZIPから除外した。自動メタデータには外形線幅を含む100.1 mm、Finish=None、内層銅厚0.035 mmという既定値が含まれるため。実際の外形中心線は100×100 mm。注文は製造ルール文書の1.6 mm・外層1 oz/内層0.5 oz・鉛含有HASLを指定し、メーカー標準積層を確認する。PCBの積層メタデータはメーカー確定積層を意味しない。

## 2026-09-28 発注実績

ユーザーから注文完了の報告を受領。注文番号 **[order-id-redacted]**、総額 **4,609円**（5枚・SMT実装・OCS Express送料込み）。[注文記録](jlcpcb_order_20260928.md)に条件・内訳・確認範囲を保存。出力時点のmanifestとREVIEW_ONLYファイルは履歴として維持し、実機未確認項目を検証済みに変更しない。

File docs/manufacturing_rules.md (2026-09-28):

# 製造ルール — JLCPCB / GBA DIRECT V1

更新日：2026-09-28。WeAct N16R2版。KiCad 10.0.5。現在の配置を維持し、配線開始用の設計ルールを設定した。製造承認・注文は行っていない。

## 製造前提

FR-4、100×100mm、4層、1.6mm厚、外層1oz・内層0.5oz、緑レジスト・白シルクを基準とする。表面処理はユーザー指定により**鉛含有HASL（通常のHASL）**とする。鉛フリーHASLではない。費用低減を目的とした2026-09-28の確定方針で、WeAct版の金額は未見積り。これらは注文に入力する設計前提であり、発注・見積り済みではない。特定スタックアップの誘電体厚・材質は注文時に照合する。インピーダンス制御は要求しない。

この指定は裸基板のランド表面仕上げに適用する。PCBAで用いるはんだペーストの組成を指定するものではない。旧FNK0099版の鉛フリーHASL見積り・HASL差額記録は履歴として残し、旧計算額4,453円を現行WeAct版の確定見積りとは扱わない。

エコノミーPCBAは上面のR1〜R33・C1/C2のみ（5品種35個）。J1/J2/J3/JP1/JP2は手はんだ、TPは露出パッド、H1〜H4は固定穴。Basic区分・在庫は発注時に再確認。

## KiCadへ設定した値（mm）

|項目|設定|
|---|---|
|異ネット銅箔間隔の最小値|0.20|
|信号線幅|標準0.25、最小0.20|
|電源・GNDの線幅|標準0.80、最小0.50（カスタムDRCで強制）|
|銅箔〜基板端|0.50|
|穴〜異ネット銅箔|0.35|
|穴端〜穴端|0.45（ビアを含めて保守的に統一）|
|ビア|貫通のみ、標準外径0.60／穴0.30|
|最小ビア外径／最小穴径|0.60／0.30|
|最小ビア環状幅|0.15|
|PTHパッド最小環状幅|0.20（カスタムDRC）|
|NPTH最小径／長穴最小幅|0.50／1.00（カスタムDRC）|
|SMDパッド〜ビア穴|0.20以上（via-in-pad禁止）|
|レジスト拡張|0.00（パッドと1:1）、最小ブリッジ幅0.10|
|レジスト開口〜隣接銅箔|0.10|
|ペースト拡張・縮小率|0.00／0%（0805標準）|
|シルク文字高さ／線幅|最小1.00／0.15|
|シルク離隔|0.15|
|ゾーン初期値|離隔0.20、最小幅0.25、サーマルギャップ／スポーク幅各0.30|

上記は本設計の採用値であり、製造業者の絶対限界値一覧ではない。電源線幅は給電能力の保証ではなく、電源回路の評価・実負荷測定は別途必要。J3形状と固定穴位置は維持し、J1/J2は22極・列間27.94 mmへ更新。

`Default` と `GBA_SIGNAL` は0.25mm配線、`POWER_3V3` は0.80mm配線。BOARD_3V3、CART_3V3、GNDを電源クラスへ、MCU_*、AD/AH・制御信号・PHI・WR_LINKを信号クラスへ割当。実ネット名のルートシート接頭辞 `/` を含めて全62接続ネットのクラス照合を実施。ネットクラスの線幅はルーター初期値であるため、電源最小幅0.50mmは `.kicad_dru` にも明記した。信号最小幅0.20mmは基板全体の制約。

ブラインド／埋込／マイクロビア、下面部品実装をカスタムルールで禁止。貫通ビアは両面テント設定を維持し、樹脂充填・銅蓋を前提にしない。In1.Cuは連続GND面として使う計画で、ゾーンと配線の実作成は次工程。アンテナ禁止領域は維持する。

## 現在の配線前検査

2026-09-28 WeAct版: placement_drc.jsonで違反0・未配線90・回路図等価性問題0。未配線は本工程の意図した残件で、無視設定にはしていない。manufacturing_drc.jsonは同一チェック時点の写し。トラック・ビア・銅箔ゾーンは未作成。

エコノミーPCBAの位置決め穴・捨て板・フィデューシャルはメーカーCAMで確認。M3固定穴をPCBA位置決め穴とみなさない。旧FNK版のDRC・製造出力・価格はarchiveの履歴であり、WeAct版の製造確認ではない。

## 4層配線後の検査（2026-09-28）

routing_drc.jsonが現行PCBの検査結果。違反0・未配線0・回路図等価性問題0。配線幅・ビア・In1 GND単一領域を検査済み。placement_drc.jsonとmanufacturing_drc.jsonの未配線90件は前工程の履歴。製造ルールは変更していない。シルク最終文言整理・製造出力は次工程。

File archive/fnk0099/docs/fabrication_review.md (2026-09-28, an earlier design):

# シルク整理・製造前CADレビュー

2026-09-27。**CAD上のDRC違反0件、未配線0件、回路図等価性問題0件。製造承認は未実施。**

## 今回完了した作業

- 可視シルク文字を高さ1.0mm以上、線幅0.15mmへ修正。既知の高さ68件・線幅52件、計120件の警告を解消した。DRC設定・除外は緩めていない。
- `NATIVE USB / DO NOT CONNECT - GBA BUS` を左側の見える空間に表示。特定コネクタを指す矢印ではなく、Native USB全般への禁止表示。実物ポートの封止・表示と併用する。
- JP1は `WR ENABLE / DEFAULT OPEN`、JP2は `POWER LINK / NORMALLY CLOSED` と表示。
- `REMOVE USB FIRST / JP1 / JP2 / CARTRIDGE` を表示し、操作前の無給電を明示。GBA ONLY / 3.3V、TP信号名を維持。
- H1/H2の参照文字を基板内側へ移動。部品位置・穴位置は変更していない。
- 非製造層の確認前注記を整理。製造シルクからUNROUTED表記を削除。
- 配線完了コミット8d5587cとの比較で、全トラック・ビア形状、パッド形状とネット、部品位置・回転が同一であることを確認した。
- PCBA対象は上面35個、BOMは5品種で一致。手はんだ部品やTP・固定穴がJLCPCB部品表へ混入していない。

## 成果物

- `hardware/gba_dumper.kicad_pcb`：シルク整理済み正本。
- `hardware/verification/routing_drc.json`：全項目0件の最新DRC。ゾーン再充填・回路図照合を含む。
- `hardware/verification/fabrication_preflight.json`：出図前CADチェック。manufacturing_approvedはfalse。
- `output/pcb/final_top.svg` / `.png`：上面の配線・シルク図。部品実装後の3D表示ではない。穴の全体確認はPCBデータ・既存配置図も参照する。
- `tools/finish_silkscreen.py` / `tools/check_fabrication_readiness.py`：整理・検査用スクリプト。

## 出図・発注までに残ること

1. ガーバー・ドリル・CPLの出力と独立照合は完了（下記）。在庫・Basic区分は発注時に再確認する。
2. エコノミーPCBA用位置決め穴はメーカー追加を基本とし、追加CAMの位置・銅箔離隔を確認する。既存M3固定穴で代用しない。捨て板・フィデューシャルの条件も注文時に確認する。
3. `open_items.md` に残る実機GPIO・起動・電源・封止保持性・カートリッジ挿抜等を確認する。ユーザー確認済みの配置やアクセスを再度未確認には戻さない。

この段階でガーバーのレビュー用出力へ進むことは可能だが、出力したことを発注承認と扱わない。ガーバー・CPLはレビュー用として生成済み。購入・注文・アップロードは行っていない。

## ガーバー・ドリル・CPL照合（2026-09-27）

正本コミット `e7eb536` のPCBからKiCad 10.0.5で出力。PCB自体の変更なし。
成果物は [出力案内](../output/fabrication_review/README.md)、機械検査結果は [verification.json](../output/fabrication_review/review/verification.json)。

- 銅箔4層、マスク2層、シルク2層、ペースト2層、外形1層の計11ファイル。裏面シルク・裏面ペーストは空で正常。
- 独立パーサーGerbonara 1.6.3で再読込し、外形中心線100×100mmを確認。上下レンダリング画像を目視確認し、固定穴、J3長穴、シルクと実装パッドの配置を確認した。
- PTH139個＝部品穴76個＋ビア63個。NPTH6個＝φ3.2mm固定穴4個＋1.6×4.6mm長穴2個。位置・径・長穴端点をPCBから抽出した期待値と一対一照合。
- Excellonの座標出力は小数3桁mm。比較許容差0.000501mmは最大0.0005mmの丸めと浮動小数誤差だけを吸収する。GerbonaraのG90ヘッダ位置警告は残るが、絶対座標と全穴形状の照合は成功。
- CPL35個はR1〜R33、C1/C2のみ。全てTop、回転0°。BOM5品種の参照番号と一致。上面ペースト開口70個をPCBパッド形状の外接矩形と照合し、各CPL中心が対応する2開口の中点になることを確認。
- Gerber・ドリル・CPLは共通原点。+X右、+Y上で、現基板のYは−100〜0mm。CPLだけの原点変更やY符号変更をしない。裏面画像は裏面から見た左右反転表示。
- 全銅箔形状の独立ネット再構成やメーカーCAM照合までを完了した意味ではない。正本の最新DRCは違反・未配線・回路図等価性問題いずれも0件。
- ZIPは基板製造データ14ファイルのみ。CPL/BOMはassemblyフォルダで別管理。manifest.jsonに正本と出力ファイルのSHA-256を保存。

CPL列名は [JLCPCB公式KiCadガイド](https://jlcpcb.com/help/article/how-to-generate-the-bom-and-centroid-file-from-kicad) に合わせた。製造承認は引き続き未実施。位置決め穴の追加CAM確認および実機ゲートは残る。

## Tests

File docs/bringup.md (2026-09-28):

# 検証手順とゲート

## Gate 1 — 論理（2026-09-28）

機械的検査: 32極・J1/J2・C++配列、28本重複なし、予約GPIO不使用、2/3/37をデータ入力にしない、GPIO3のプルアップ、JP1後段/WRプルアップ。検査はtests/hardware/check_design.py。ERCはhardware/verification/erc.rpt。実際の起動時HIGHの保証はGate2で確認する。

## Gate 2 — WeAct N16R2単体（未実施）

1. カートリッジを接続しない。現物の型番・端子順・基板版（改造しない）を記録する。
2. Native USBは未接続。CH343側から給電・UART書込みする。GPIO3に回路相当プルアップを設け、起動・リセット・復旧を確認。
3. 将来の無負荷試験FWで28本を安全な治具へ出力しHIGH/LOWを確認。GPIO35/36は入出力、37は出力、39〜42は通常GPIO設定を確認。
4. GPIO2/37の波形、制御線HIGH電圧と起動時グリッチを測る。未知カートリッジとの競合試験をしない。

## Gate 3 — 機械・電源・PCB（未実施）

公式外形図と販売業者回答をweact_footprint.mdに記録。22極ソケット嵌合・未寸法の起点・組立間隔・USB空間・スロット導通・電源余裕を確認。配線後DRCは未配線・違反・回路図不一致0件。CAD検査と実機確認を区別する。3.3V-GND短絡・5V混入・抵抗バイパスがないことを確認し、Gate1〜3完了後に発注判断。

## Gate 4 — 到着後ROM（未実施）

ソケット組立後、WeAct N16R2下面と親基板表面の間隔が最低2.5mm（目標3.0mm以上）あること、下面部品が接触しないことを確認する。

JP1 OPEN、JP2 CLOSE。カートリッジなしで起動波形を測定。電源OFFで検証用カートリッジを挿入。供給電圧と/WR HIGH、AD方向切替順序を確認。192Bヘッダのタイトル/コード/固定値/チェックサム、先頭/境界/末尾を検査。明示サイズで2回独立に取得し長さ・SHA-256を比較。固定配線誤りは一致ハッシュのみでは排除できない。ABORT・切断・timeoutで非選択へ戻ることを確認。

## Gate 5 — SAVE（未実施）

既存SAVE退避、種別確定。EEPROM要求・Flash ID/バンク切替にはJP1装着が必要となるためUSBを抜いて操作。プロトコルコマンドと内容変更を分離。未知種別の書込み拒否、既知種別のタイムアウト、書戻し後全量比較を検証。対応表に構成・版・実測結果を記録。

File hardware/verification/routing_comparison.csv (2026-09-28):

signal | fnk_path_mm | weact_path_mm | path_delta_mm | path_delta_percent | fnk_net_sum_mm | weact_net_sum_mm | fnk_vias | weact_vias
AD0 | 48.549 | 48.024 | -0.525 | -1.081 | 48.549 | 48.024 | 1 | 1
AD1 | 41.519 | 43.233 | 1.714 | 4.128 | 41.519 | 43.233 | 1 | 2
AD2 | 45.581 | 48.324 | 2.742 | 6.017 | 45.581 | 48.324 | 1 | 2
AD3 | 47.004 | 48.237 | 1.233 | 2.623 | 47.004 | 48.237 | 1 | 2
AD4 | 54.847 | 60.618 | 5.77 | 10.521 | 55.313 | 60.618 | 2 | 4
AD5 | 62.77 | 65.266 | 2.496 | 3.976 | 63.286 | 65.266 | 3 | 4
AD6 | 65.334 | 73.689 | 8.354 | 12.787 | 65.334 | 73.781 | 3 | 3
AD7 | 64.947 | 69.895 | 4.948 | 7.618 | 65.222 | 70.132 | 3 | 1
AD8 | 74.203 | 74.082 | -0.121 | -0.163 | 74.241 | 74.632 | 2 | 2
AD9 | 73.612 | 69.791 | -3.821 | -5.191 | 74.366 | 70.394 | 2 | 1
AD10 | 77.963 | 81.073 | 3.11 | 3.989 | 77.963 | 81.073 | 4 | 2
AD11 | 103.554 | 82.228 | -21.326 | -20.594 | 103.554 | 83.605 | 2 | 3
AD12 | 101.871 | 86.433 | -15.438 | -15.155 | 101.871 | 86.433 | 3 | 3
AD13 | 113.195 | 86.691 | -26.504 | -23.414 | 113.195 | 87.391 | 2 | 2
AD14 | 108.456 | 116.654 | 8.197 | 7.558 | 108.456 | 116.654 | 2 | 2
AD15 | 134.837 | 135.081 | 0.244 | 0.181 | 139.912 | 140.156 | 2 | 1
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

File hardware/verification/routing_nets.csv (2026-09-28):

net | FNK0099_track_mm | WeAct_track_mm | delta_mm | FNK0099_vias | WeAct_vias
/BOARD_3V3 | 48.314 | 49.232 | 0.919 | 0 | 0
/CART_3V3 | 109.224 | 103.607 | -5.617 | 1 | 1
/CART_A16_D0 | 71.486 | 52.381 | -19.105 | 2 | 0
/CART_A17_D1 | 56.663 | 49.928 | -6.734 | 1 | 1
/CART_A18_D2 | 67.035 | 59.612 | -7.423 | 1 | 1
/CART_A19_D3 | 68.99 | 66.465 | -2.525 | 1 | 1
/CART_A20_D4 | 69.528 | 62.149 | -7.379 | 1 | 1
/CART_A21_D5 | 72.656 | 64.458 | -8.198 | 1 | 2
/CART_A22_D6 | 72.533 | 66.189 | -6.344 | 1 | 1
/CART_A23_D7 | 79.625 | 73.224 | -6.401 | 1 | 1
/CART_AD0 | 33.089 | 33.089 | -0.0 | 1 | 1
/CART_AD1 | 27.107 | 29.39 | 2.283 | 1 | 2
/CART_AD10 | 57.893 | 57.737 | -0.156 | 3 | 1
/CART_AD11 | 67.13 | 55.593 | -11.538 | 1 | 1
/CART_AD12 | 77.303 | 60.714 | -16.589 | 2 | 1
/CART_AD13 | 88.166 | 62.35 | -25.817 | 1 | 1
/CART_AD14 | 82.968 | 83.229 | 0.261 | 1 | 1
/CART_AD15 | 98.514 | 97.628 | -0.886 | 2 | 1
/CART_AD2 | 31.36 | 34.672 | 3.312 | 1 | 2
/CART_AD3 | 32.973 | 34.776 | 1.802 | 1 | 2
/CART_AD4 | 37.264 | 36.991 | -0.273 | 1 | 2
/CART_AD5 | 40.917 | 38.184 | -2.732 | 2 | 2
/CART_AD6 | 43.424 | 47.66 | 4.236 | 2 | 1
/CART_AD7 | 43.61 | 43.194 | -0.416 | 2 | 1
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

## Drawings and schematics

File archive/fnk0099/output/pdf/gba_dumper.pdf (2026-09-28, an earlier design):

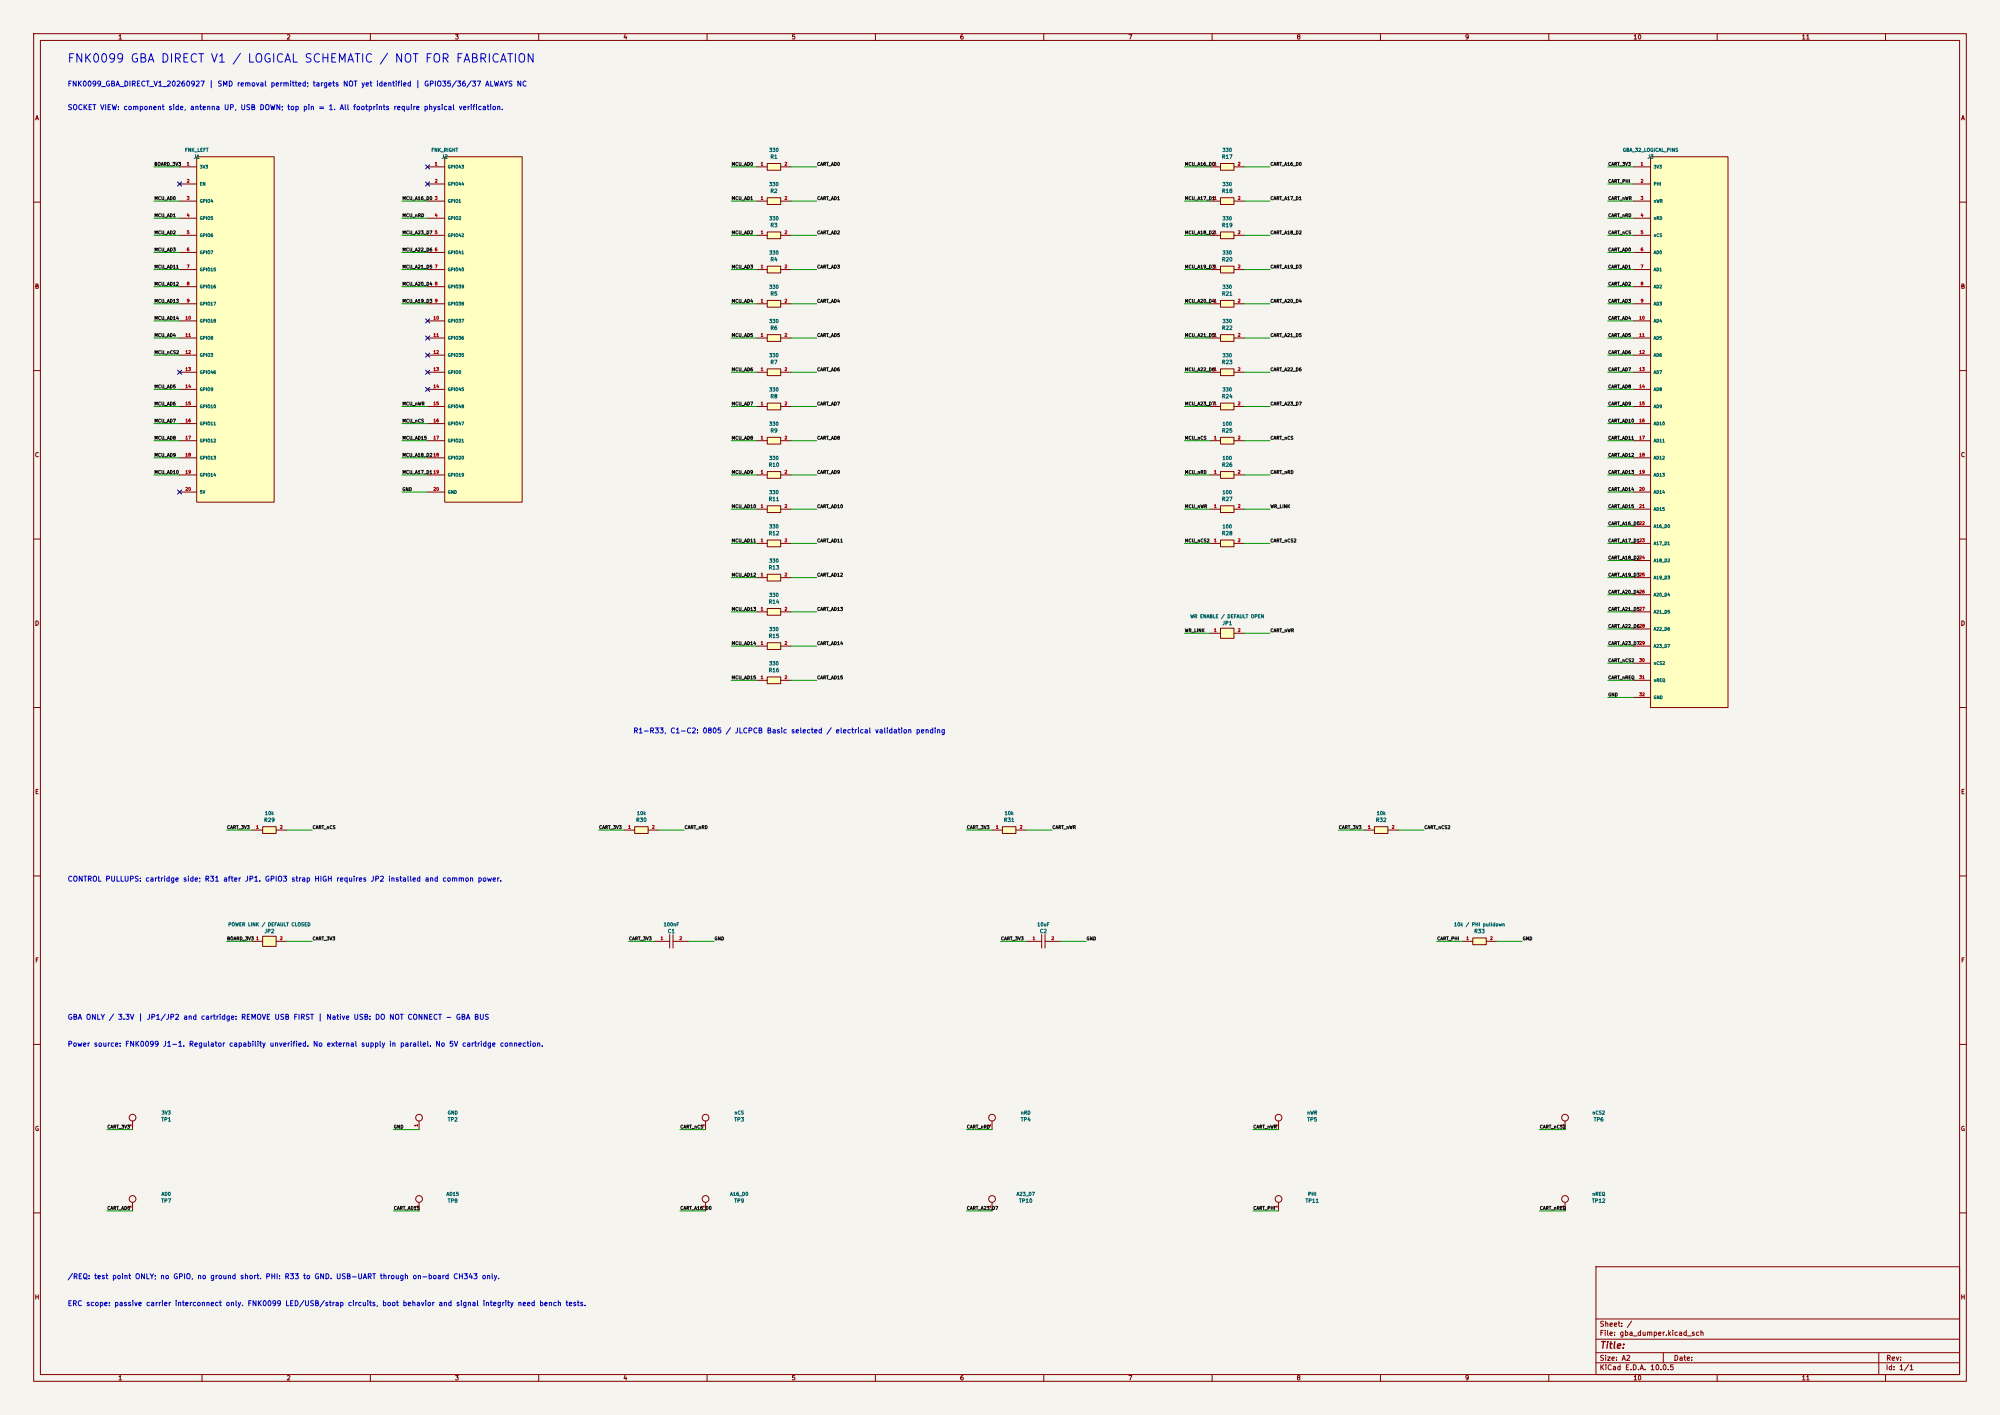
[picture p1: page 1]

FNK0099 GBA DIRECT V1 / LOGICAL SCHEMATIC / NOT FOR FABRICATION

FNK0099_GBA_DIRECT_V1_20260927 | SMD removal permitted; targets NOT yet identified | GPIO35/36/37 ALWAYS NC

SOCKET VIEW: component side, antenna UP, USB DOWN; top pin = 1. All footprints require physical verification.

JP1 WR ENABLE / DEFAULT OPEN

R1-R33, C1-C2: 0805 / JLCPCB Basic selected / electrical validation pending

CONTROL PULLUPS: cartridge side; R31 after JP1. GPIO3 strap HIGH requires JP2 installed and common power.

POWER LINK / DEFAULT CLOSED

GBA ONLY / 3.3V | JP1/JP2 and cartridge: REMOVE USB FIRST | Native USB: DO NOT CONNECT - GBA BUS

Power source: FNK0099 J1-1. Regulator capability unverified. No external supply in parallel. No 5V cartridge connection.

/REQ: test point ONLY; no GPIO, no ground short. PHI: R33 to GND. USB-UART through on-board CH343 only.

ERC scope: passive carrier interconnect only. FNK0099 LED/USB/strap circuits, boot behavior and signal integrity need bench tests.

Size: A2 | Rev:
KiCad E.D.A. 10.0.5 | Id: 1/1

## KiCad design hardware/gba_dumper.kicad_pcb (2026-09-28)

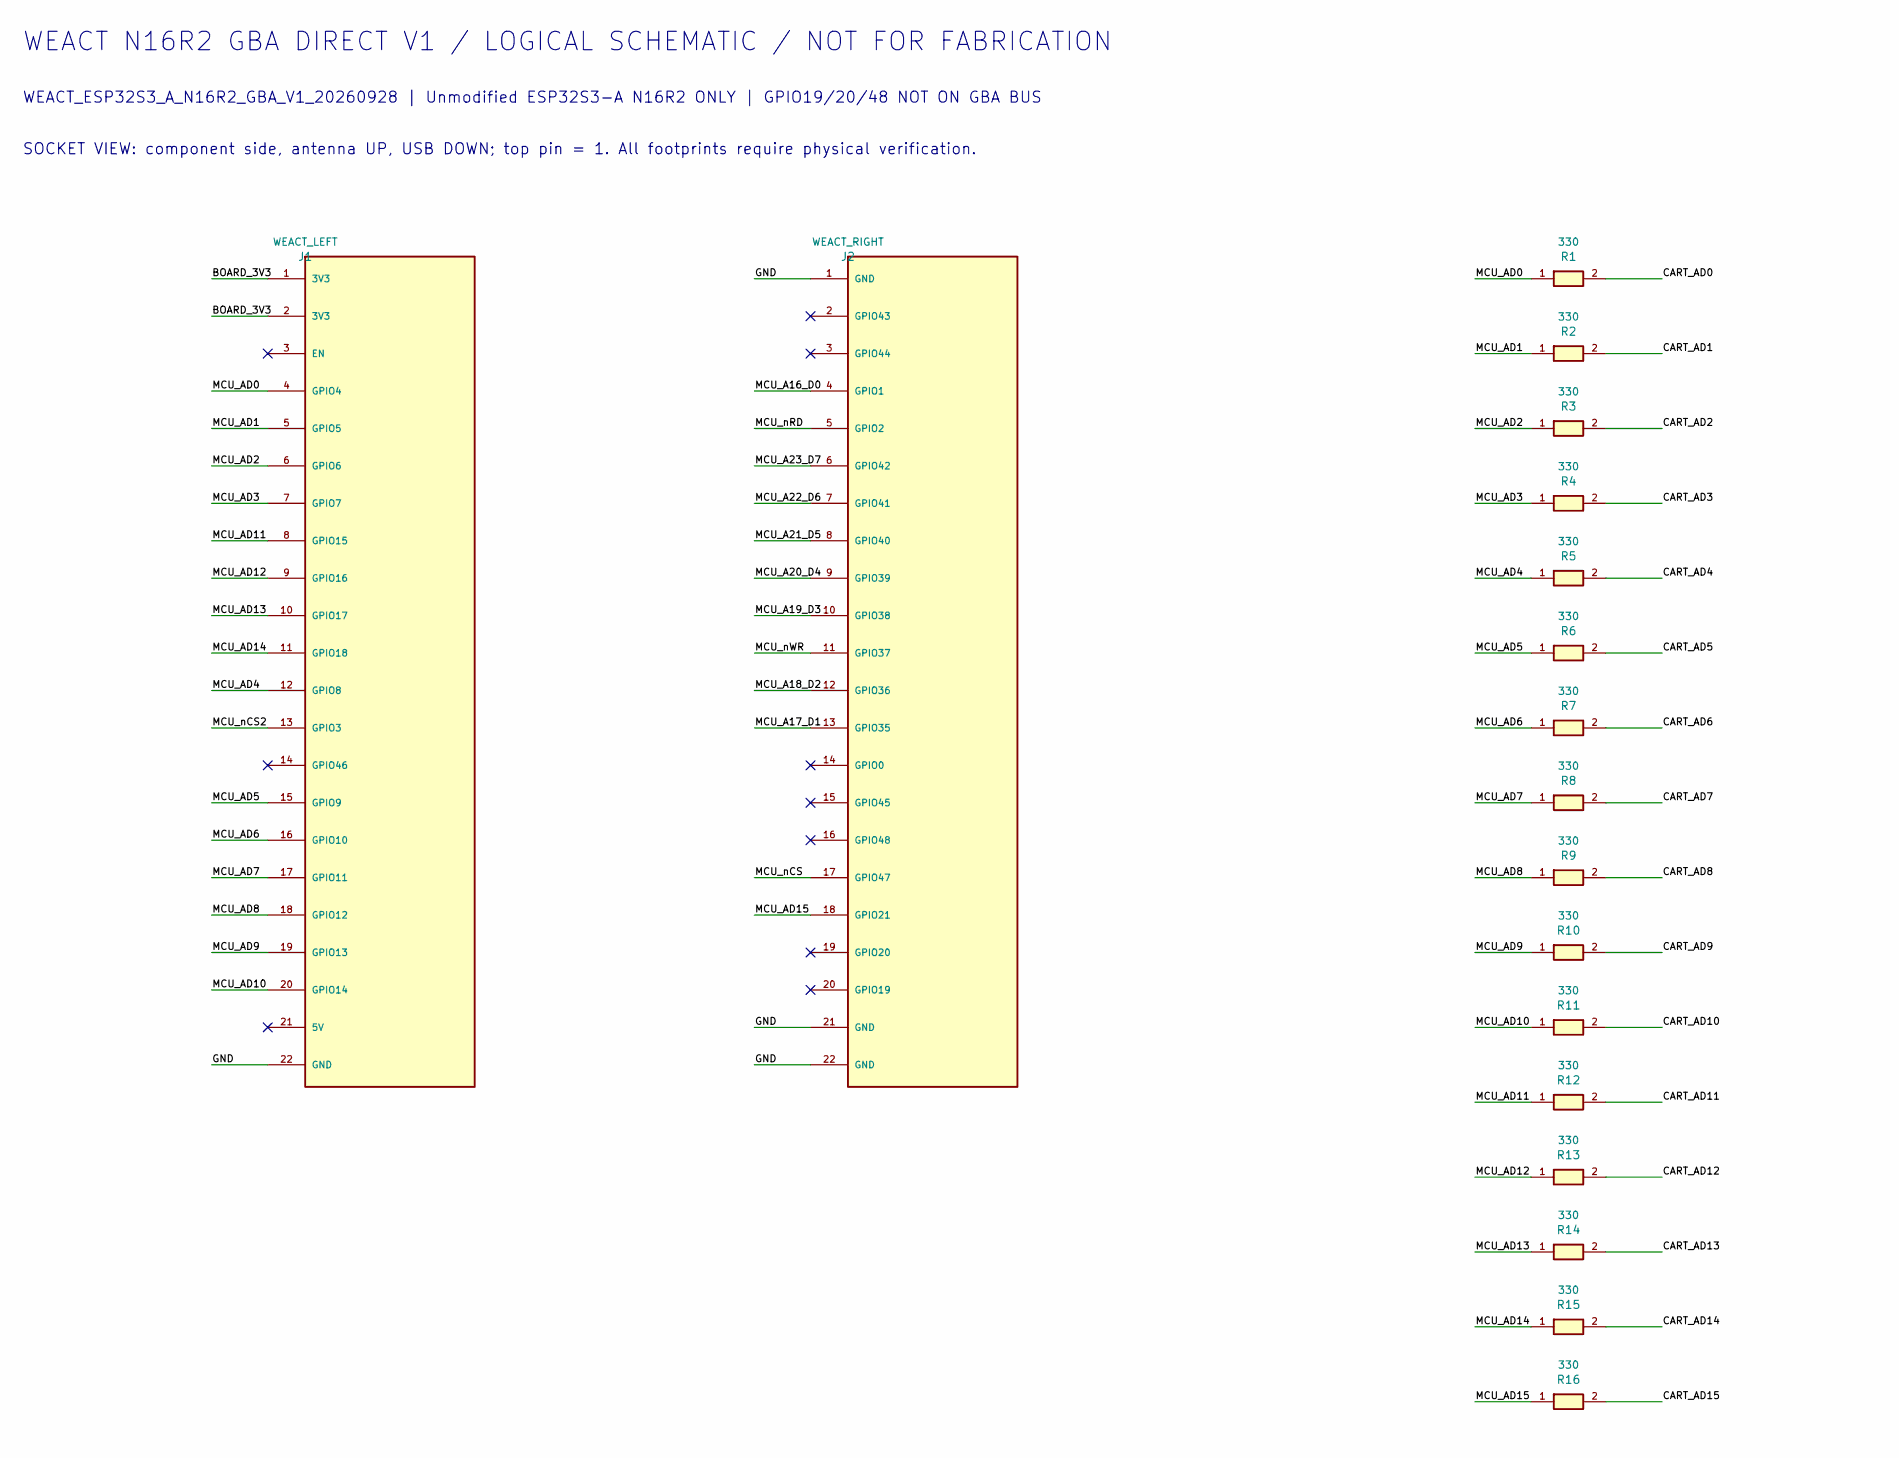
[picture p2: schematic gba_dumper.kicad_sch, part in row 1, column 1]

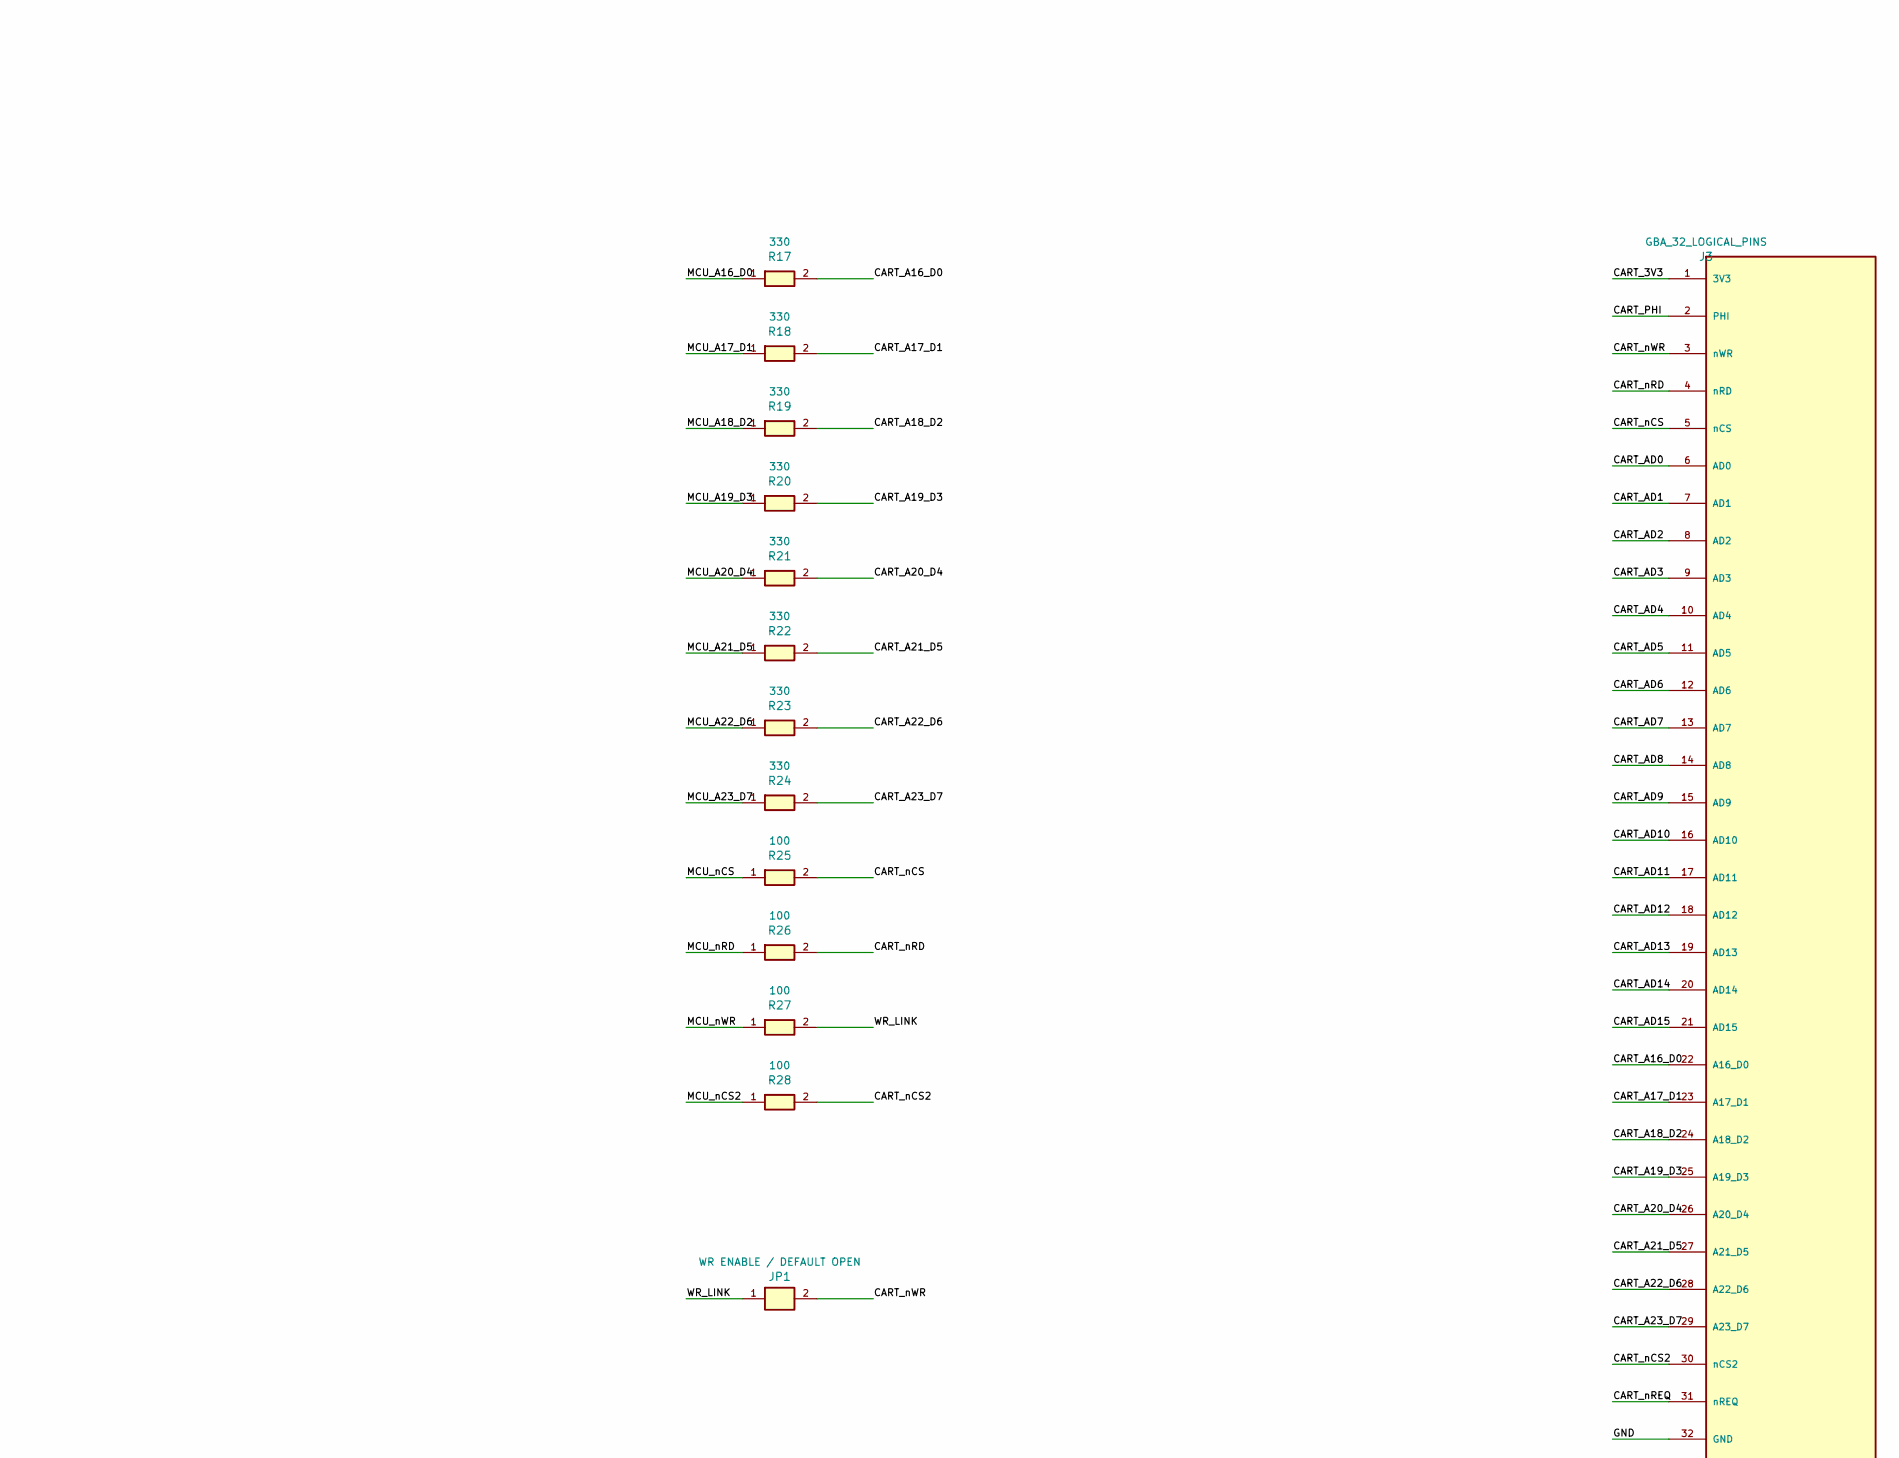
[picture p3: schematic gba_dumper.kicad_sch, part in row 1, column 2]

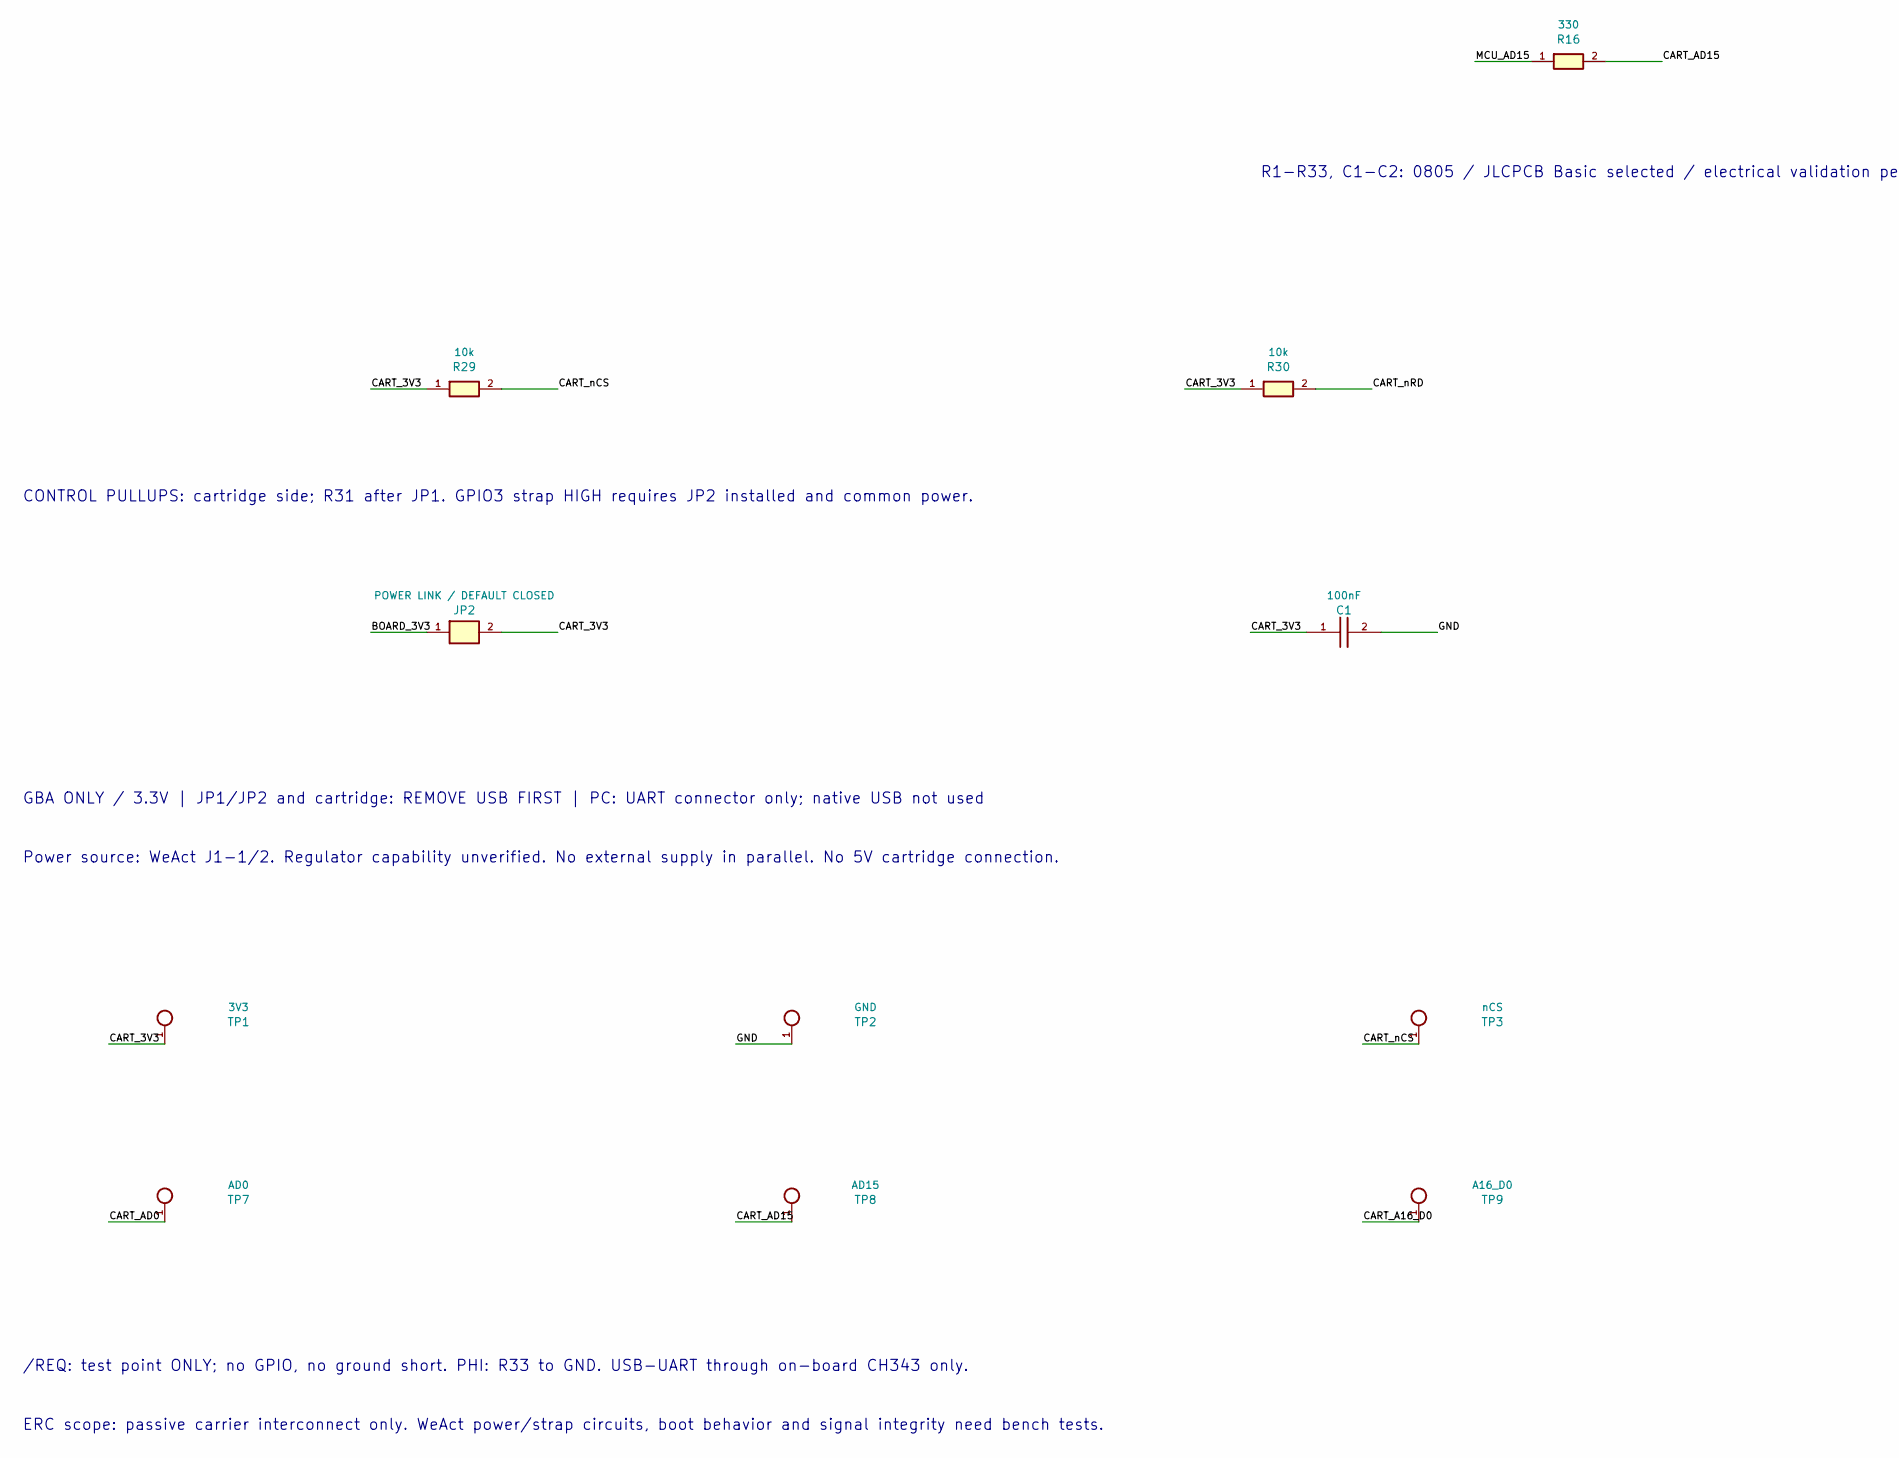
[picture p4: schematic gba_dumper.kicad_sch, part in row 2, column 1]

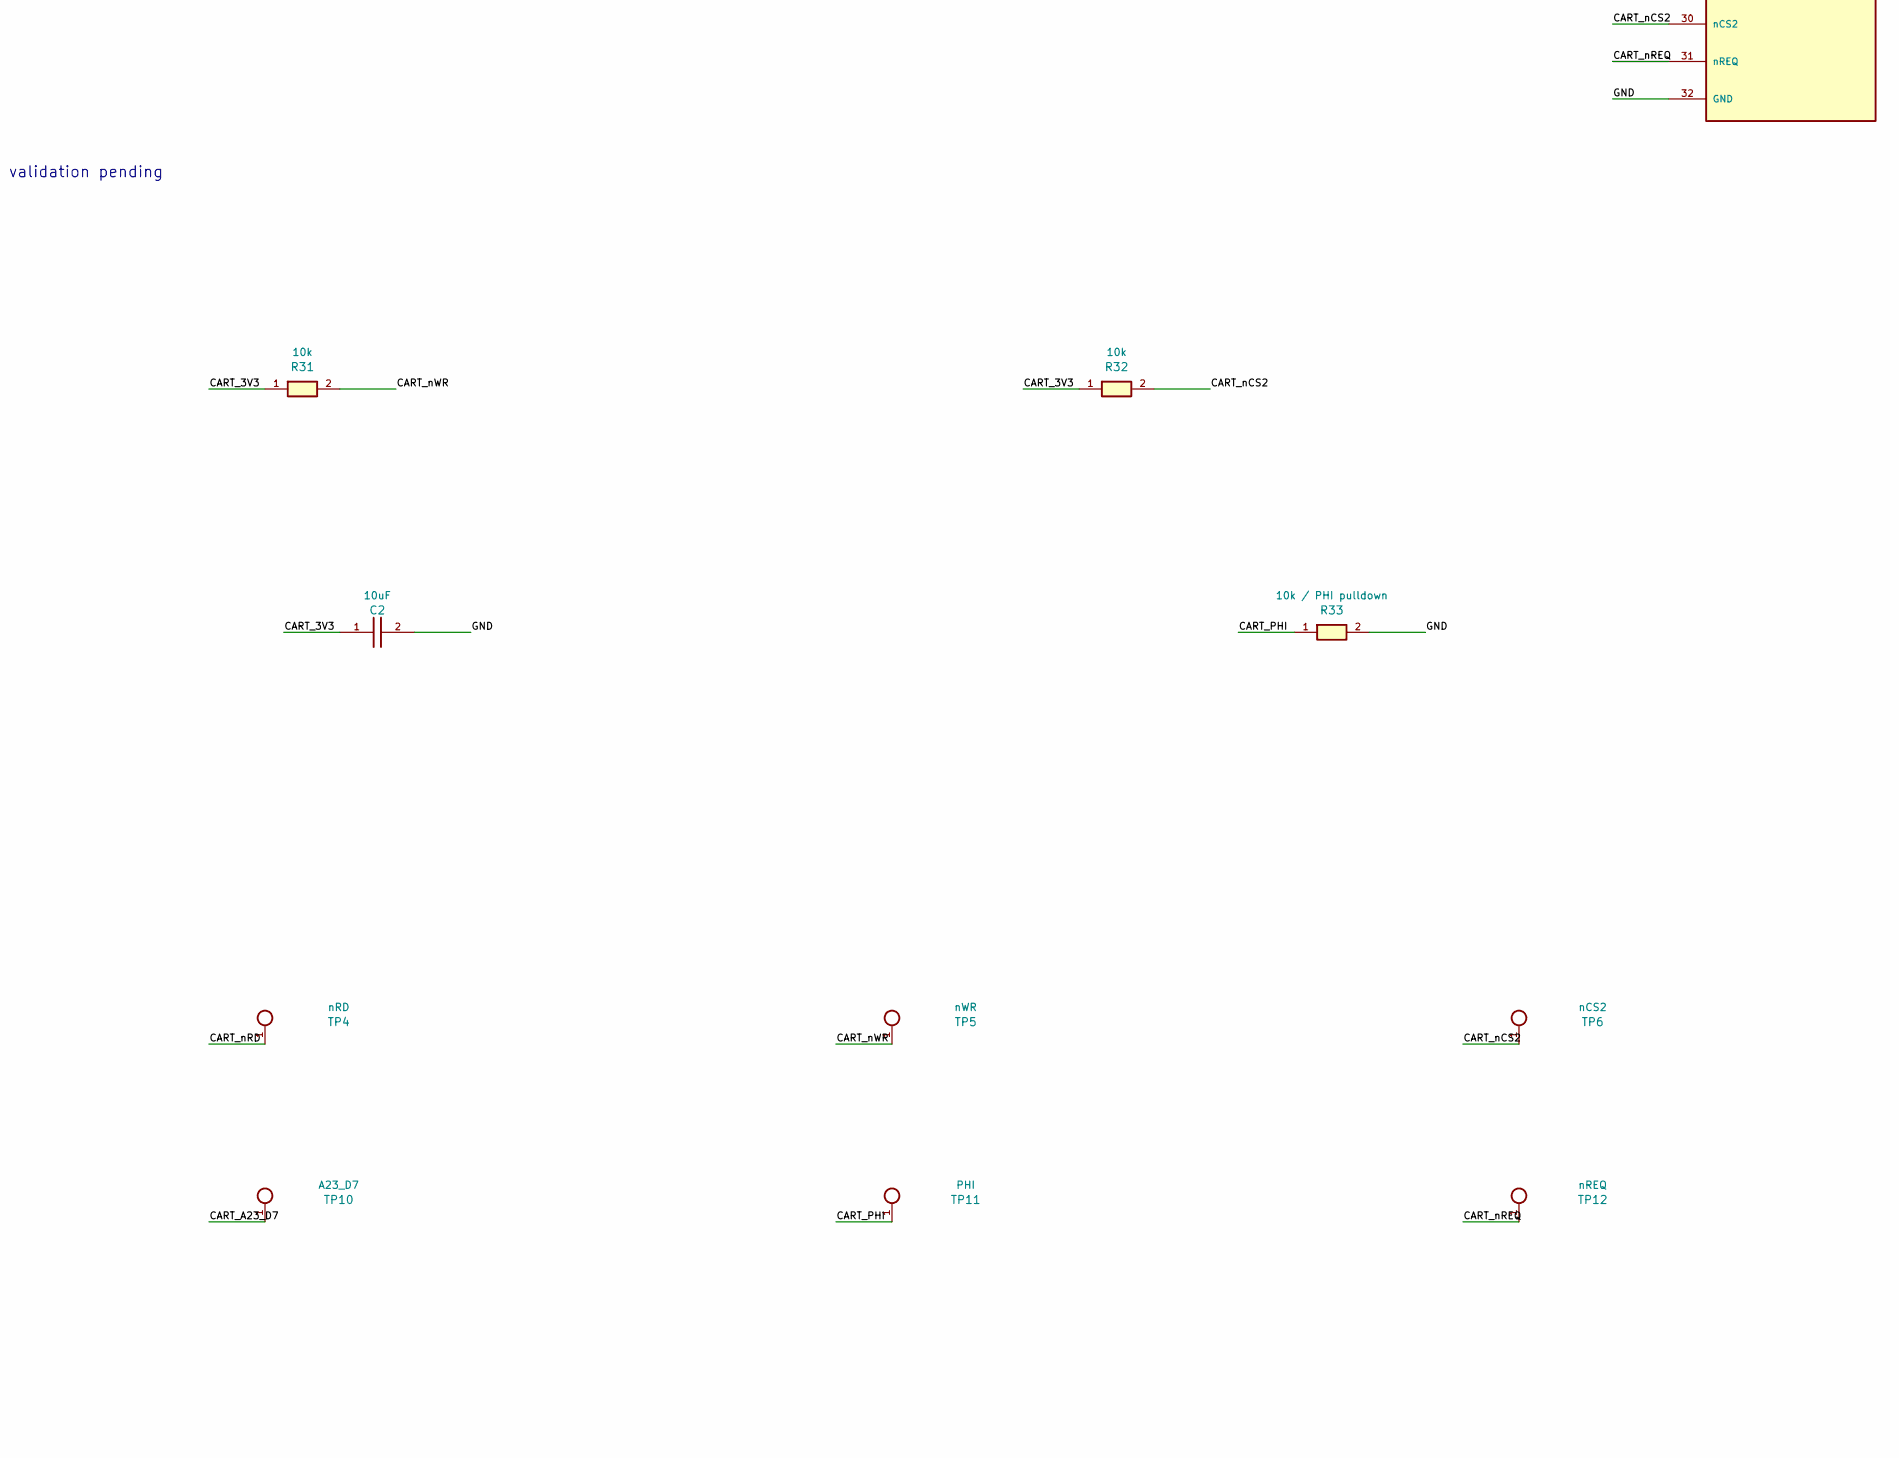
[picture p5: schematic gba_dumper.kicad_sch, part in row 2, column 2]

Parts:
C1: 100nF; C_0805_2012Metric; Rating 50V; X7R; +/-10%; MPN CC0805KRX7R9BB104; LCSC C49678
C2: 10uF; C_0805_2012Metric; Rating 25V; X5R; +/-10%; MPN CL21A106KAYNNNE; LCSC C15850
J1: WEACT_LEFT; PinSocket_1x22_P2.54mm_D1.02mm; Rating 3A; 2.54mm; housing 8.5mm; WeAct header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; MPN FH2.54-40U1GF8.5-0.5
J2: WEACT_RIGHT; PinSocket_1x22_P2.54mm_D1.02mm; Rating 3A; 2.54mm; housing 8.5mm; WeAct header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; MPN FH2.54-40U1GF8.5-0.5
J3: GBA_32_LOGICAL_PINS; GameBoy_Cartridge_AGB_1x32_P1.50mm_Socket_Horizontal; Rating GBA 32 contacts; user-approved footprin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; MPN N/A - manufacturer part number not iden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
JP1: WR ENABLE / DEFAULT OPEN; PinHeader_1x02_P2.54mm_D1.02mm; Rating 3A; 2.54mm pitch; 0.64mm square pins; MPN PH-1X2SG
JP2: POWER LINK / DEFAULT CLOSED; PinHeader_1x02_P2.54mm_D1.02mm; Rating 3A; 2.54mm pitch; 0.64mm square pins; MPN PH-1X2SG
R1, R2, R3, R4, R5, R6, R7, R8, R9, R10, R11, R12, R13, R14, R15, R16, R17, R18, R19, R20, R21, R22, R23, R24: 330; R_0805_2012Metric; Rating 125mW; 150V; +/-1%; +/-100ppm/C; MPN 0805W8F3300T5E; LCSC C17630
R25, R26, R27, R28: 100; R_0805_2012Metric; Rating 125mW; 150V; +/-1%; +/-100ppm/C; MPN 0805W8F1000T5E; LCSC C17408
R29, R30, R31, R32: 10k; R_0805_2012Metric; Rating 125mW; 150V; +/-1%; +/-100ppm/C; MPN 0805W8F1002T5E; LCSC C17414
R33: 10k / PHI pulldown; R_0805_2012Metric; Rating 125mW; 150V; +/-1%; +/-100ppm/C; MPN 0805W8F1002T5E; LCSC C17414
TP1: 3V3; TestPoint_Pad_D2.0mm
TP2: GND; TestPoint_Pad_D2.0mm
TP3: nCS; TestPoint_Pad_D2.0mm
TP4: nRD; TestPoint_Pad_D2.0mm
TP5: nWR; TestPoint_Pad_D2.0mm
TP6: nCS2; TestPoint_Pad_D2.0mm
TP7: AD0; TestPoint_Pad_D2.0mm
TP8: AD15; TestPoint_Pad_D2.0mm
TP9: A16_D0; TestPoint_Pad_D2.0mm
TP10: A23_D7; TestPoint_Pad_D2.0mm
TP11: PHI; TestPoint_Pad_D2.0mm
TP12: nREQ; TestPoint_Pad_D2.0mm

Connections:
/BOARD_3V3: J1.1 (3V3), J1.2 (3V3), JP2.1
/CART_3V3: C1.1, C2.1, J3.1 (3V3), JP2.2, R29.1, R30.1, R31.1, R32.1, TP1.1
/CART_A16_D0: J3.22 (A16_D0), R17.2, TP9.1
/CART_A17_D1: J3.23 (A17_D1), R18.2
/CART_A18_D2: J3.24 (A18_D2), R19.2
/CART_A19_D3: J3.25 (A19_D3), R20.2
/CART_A20_D4: J3.26 (A20_D4), R21.2
/CART_A21_D5: J3.27 (A21_D5), R22.2
/CART_A22_D6: J3.28 (A22_D6), R23.2
/CART_A23_D7: J3.29 (A23_D7), R24.2, TP10.1
/CART_AD0: J3.6 (AD0), R1.2, TP7.1
/CART_AD1: J3.7 (AD1), R2.2
/CART_AD2: J3.8 (AD2), R3.2
/CART_AD3: J3.9 (AD3), R4.2
/CART_AD4: J3.10 (AD4), R5.2
/CART_AD5: J3.11 (AD5), R6.2
/CART_AD6: J3.12 (AD6), R7.2
/CART_AD7: J3.13 (AD7), R8.2
/CART_AD8: J3.14 (AD8), R9.2
/CART_AD9: J3.15 (AD9), R10.2
/CART_AD10: J3.16 (AD10), R11.2
/CART_AD11: J3.17 (AD11), R12.2
/CART_AD12: J3.18 (AD12), R13.2
/CART_AD13: J3.19 (AD13), R14.2
/CART_AD14: J3.20 (AD14), R15.2
/CART_AD15: J3.21 (AD15), R16.2, TP8.1
/CART_PHI: J3.2 (PHI), R33.1, TP11.1
/CART_nCS: J3.5 (nCS), R25.2, R29.2, TP3.1
/CART_nCS2: J3.30 (nCS2), R28.2, R32.2, TP6.1
/CART_nRD: J3.4 (nRD), R26.2, R30.2, TP4.1
/CART_nREQ: J3.31 (nREQ), TP12.1
/CART_nWR: J3.3 (nWR), JP1.2, R31.2, TP5.1
/GND: C1.2, C2.2, J1.22 (GND), J2.1 (GND), J2.21 (GND), J2.22 (GND), J3.32 (GND), R33.2, TP2.1
/MCU_A16_D0: J2.4 (GPIO1), R17.1
/MCU_A17_D1: J2.13 (GPIO35), R18.1
/MCU_A18_D2: J2.12 (GPIO36), R19.1
/MCU_A19_D3: J2.10 (GPIO38), R20.1
/MCU_A20_D4: J2.9 (GPIO39), R21.1
/MCU_A21_D5: J2.8 (GPIO40), R22.1
/MCU_A22_D6: J2.7 (GPIO41), R23.1
/MCU_A23_D7: J2.6 (GPIO42), R24.1
/MCU_AD0: J1.4 (GPIO4), R1.1
/MCU_AD1: J1.5 (GPIO5), R2.1
/MCU_AD2: J1.6 (GPIO6), R3.1
/MCU_AD3: J1.7 (GPIO7), R4.1
/MCU_AD4: J1.12 (GPIO8), R5.1
/MCU_AD5: J1.15 (GPIO9), R6.1
/MCU_AD6: J1.16 (GPIO10), R7.1
/MCU_AD7: J1.17 (GPIO11), R8.1
/MCU_AD8: J1.18 (GPIO12), R9.1
/MCU_AD9: J1.19 (GPIO13), R10.1
/MCU_AD10: J1.20 (GPIO14), R11.1
/MCU_AD11: J1.8 (GPIO15), R12.1
/MCU_AD12: J1.9 (GPIO16), R13.1
/MCU_AD13: J1.10 (GPIO17), R14.1
/MCU_AD14: J1.11 (GPIO18), R15.1
/MCU_AD15: J2.18 (GPIO21), R16.1
/MCU_nCS: J2.17 (GPIO47), R25.1
/MCU_nCS2: J1.13 (GPIO3), R28.1
/MCU_nRD: J2.5 (GPIO2), R26.1
/MCU_nWR: J2.11 (GPIO37), R27.1
/WR_LINK: JP1.1, R27.2

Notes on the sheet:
WEACT N16R2 GBA DIRECT V1 / LOGICAL SCHEMATIC / NOT FOR FABRICATION
WEACT_ESP32S3_A_N16R2_GBA_V1_20260928 | Unmodified ESP32S3-A N16R2 ONLY | GPIO19/20/48 NOT ON GBA BUS
SOCKET VIEW: component side, antenna UP, USB DOWN; top pin = 1. All footprints require physical verification.
R1-R33, C1-C2: 0805 / JLCPCB Basic selected / electrical validation pending
CONTROL PULLUPS: cartridge side; R31 after JP1. GPIO3 strap HIGH requires JP2 installed and common power.
GBA ONLY / 3.3V | JP1/JP2 and cartridge: REMOVE USB FIRST | PC: UART connector only; native USB not used
Power source: WeAct J1-1/2. Regulator capability unverified. No external supply in parallel. No 5V cartridge connection.
/REQ: test point ONLY; no GPIO, no ground short. PHI: R33 to GND. USB-UART through on-board CH343 only.
ERC scope: passive carrier interconnect only. WeAct power/strap circuits, boot behavior and signal integrity need bench tests.

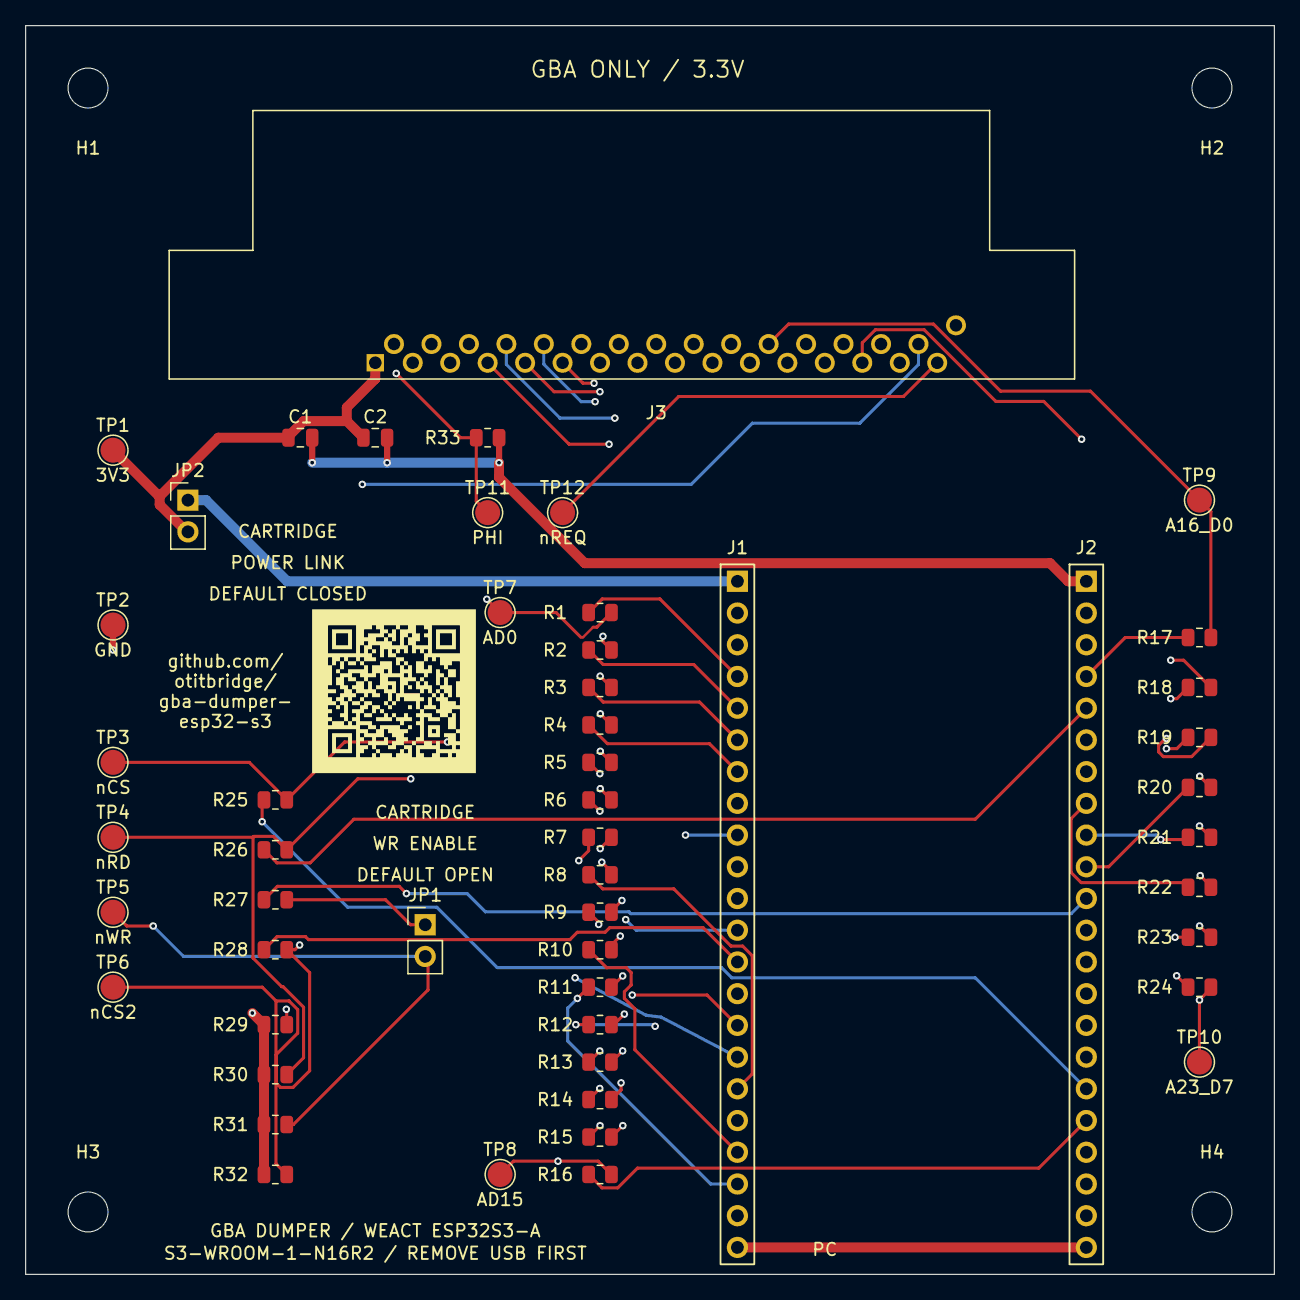
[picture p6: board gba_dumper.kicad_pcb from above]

Board: 4 copper layers, 100.0 x 100.0 mm, 56 parts (0 on the bottom side), 62 nets.

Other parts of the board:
H1, H2, H3, H4: M3 / 14mm foot; MountingHole_3.2mm_M3

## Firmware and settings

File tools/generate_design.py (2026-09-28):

"""Generate the logical design and BOM from explicit part selections."""
from pathlib import Path
import json, csv, uuid
ROOT=Path(__file__).resolve().parents[1]
def write(p,s): (ROOT/p).write_text(s)
_uid_counter=0
def uid():
 global _uid_counter
 _uid_counter+=1
 return str(uuid.uuid5(uuid.NAMESPACE_URL,f'WEACT_ESP32S3_A_N16R2_GBA_V1_20260928/{_uid_counter}'))
def q(s): return json.dumps(str(s),ensure_ascii=False)
AD=[4,5,6,7,8,9,10,11,12,13,14,15,16,17,18,21]
AH=[1,35,36,38,39,40,41,42]
left=['3V3','3V3','EN',4,5,6,7,15,16,17,18,8,3,46,9,10,11,12,13,14,'5V','GND']
right=['GND',43,44,1,2,42,41,40,39,38,37,36,35,0,45,48,47,21,20,19,'GND','GND']
rows=[]
for i,g in enumerate(AD): rows.append(dict(signal=f'AD{i}',gpio=g,cart_pin=i+6,resistor=f'R{i+1}',ohms=330))
for i,g in enumerate(AH): rows.append(dict(signal=f'A{i+16}_D{i}',gpio=g,cart_pin=i+22,resistor=f'R{i+17}',ohms=330))
for i,(s,g,p) in enumerate([('nCS',47,5),('nRD',2,4),('nWR',37,3),('nCS2',3,30)]): rows.append(dict(signal=s,gpio=g,cart_pin=p,resistor=f'R{i+25}',ohms=100))
for r in rows:
 for j,arr in [('J1',left),('J2',right)]:
  if r['gpio'] in arr: r.update(socket=j,socket_pin=arr.index(r['gpio'])+1)
write('hardware/pinmap.json',json.dumps({'id':'WEACT_ESP32S3_A_N16R2_GBA_V1_20260928','signals':rows},indent=2)+'\n')
bygpio={r['gpio']:r for r in rows}
cart={r['cart_pin']:r['signal'] for r in rows}; cart.update({1:'3V3',2:'PHI',31:'nREQ',32:'GND'})
pintext='# GPIO・ソケット配線正本\n\n識別子: `WEACT_ESP32S3_A_N16R2_GBA_V1_20260928`。実機未検証。\n\nJ1/J2は部品面、アンテナ上・USB下で左/右、上から1–22。\n\n|GBA端子|信号|GPIO|ソケット|直列抵抗|\n|---:|---|---:|---|---|\n'
for p in range(1,33):
 r=next((r for r in rows if r['cart_pin']==p),None)
 pintext+=f'|{p}|{cart[p]}|{r["gpio"] if r else "—"}|{r["socket"]+"-"+str(r["socket_pin"]) if r else {1:"J1-1 → JP2",32:"J2-22 (共通GND)"}.get(p,"TPのみ" if p==31 else "R33 → GND + TP")}|{r["resistor"]+" / "+str(r["ohms"])+" Ω" if r else "—"}|\n'
pintext+='\n|位置|J1|J2|\n|---:|---|---|\n'
for i,(a,b) in enumerate(zip(left,right),1): pintext+=f'|{i}|{a if isinstance(a,str) else "GPIO"+str(a)}|{b if isinstance(b,str) else "GPIO"+str(b)}|\n'
pintext+='\nGPIO0/19/20/43/44/45/46/48、EN、5Vは親基板でNC。UART0はWeAct上のCH343に接続されたまま。/WRはR27→JP1→CART_nWR、R31はJP1よりカートリッジ側。/CS2プルアップはJP2装着時のみ給電される。\n'
write('docs/pinmap.md',pintext)
write('firmware/main/pinmap.hpp','''#pragma once
#include <array>
#include <cstddef>
#include <cstdint>
namespace gba_pins {
inline constexpr char ID[] = "WEACT_ESP32S3_A_N16R2_GBA_V1_20260928";
inline constexpr std::array<int,16> AD = {'''+','.join(map(str,AD))+'''};
inline constexpr std::array<int,8> AH = {'''+','.join(map(str,AH))+'''};
inline constexpr int NCS=47, NRD=2, NWR=37, NCS2=3;
inline constexpr int UART_TX=43, UART_RX=44;
inline constexpr std::array<int,4> CTRL={NCS,NRD,NWR,NCS2};
constexpr std::uint64_t bit(int gpio) { return std::uint64_t{1} << gpio; }
template<std::size_t N> constexpr std::uint64_t mask(const std::array<int,N>& pins) {
    std::uint64_t v=0; for(int p:pins) v |= bit(p); return v;
}
constexpr unsigned popcount(std::uint64_t v) {
    unsigned n=0; while(v) { n += unsigned(v&1U); v >>= 1U; } return n;
}
inline constexpr auto AD_MASK=mask(AD), AH_MASK=mask(AH), CTRL_MASK=mask(CTRL);
inline constexpr auto ALL_MASK=AD_MASK|AH_MASK|CTRL_MASK;
inline constexpr auto FORBIDDEN_MASK=bit(0)|bit(19)|bit(20)|bit(48)|bit(43)|bit(44)|bit(45)|bit(46);
static_assert(popcount(AD_MASK)==16 && popcount(AH_MASK)==8 && popcount(CTRL_MASK)==4);
static_assert(popcount(ALL_MASK)==28,"Duplicate GPIO assignment");
static_assert((ALL_MASK & FORBIDDEN_MASK)==0,"Reserved GPIO used");
static_assert((AD_MASK >> 32U)==0,"AD must stay in bank 0");
static_assert(((AD_MASK|AH_MASK)&(bit(2)|bit(3)|bit(37)))==0);
}
''')
# Native KiCad schematic with embedded, passive connector models. External board electronics are not modeled.
parts=json.loads((ROOT/'hardware/bom/selected_parts.json').read_text())
manual_parts=json.loads((ROOT/'hardware/bom/manual_parts.json').read_text())
selected={ref:part for part in parts+manual_parts for ref in part['refs']}
rootid=uid(); lib=[]; body=[]; expected={}; bom=[]
def font(size=1): return f'(effects (font (size {size} {size})))'
def symbol_def(name,pins,shape):
 s=f'(symbol "GBA:{name}" (pin_names (offset 0.8)) (in_bom yes) (on_board yes) (property "Reference" "X" (at 0 0 0) {font()}) (property "Value" "{name}" (at 0 -3 0) {font()}) (symbol "{name}_0_1" {shape}) (symbol "{name}_1_1" '
 for n,label,x,y,angle,length in pins:
  s+=f'(pin passive line (at {x} {y} {angle}) (length {length}) (name {q(label)} {font(0.9)}) (number "{n}" {font(0.9)}))'
 lib.append(s+'))')
 return pins
def rectangle(x1,y1,x2,y2): return f'(rectangle (start {x1} {y1}) (end {x2} {y2}) (stroke (width 0.254) (type default)) (fill (type background)))'
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

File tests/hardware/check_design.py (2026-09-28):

"""Independent checks against the WeAct official ESP32S3-A header table and approved migration."""
from pathlib import Path
import json, re, xml.etree.ElementTree as ET
root=Path(__file__).resolve().parents[2]
rows=json.loads((root/'hardware/pinmap.json').read_text())['signals']
gpios=[4,5,6,7,8,9,10,11,12,13,14,15,16,17,18,21,1,35,36,38,39,40,41,42,47,2,37,3]
pads=[('J1',p) for p in [4,5,6,7,12,15,16,17,18,19,20,8,9,10,11]]+[('J2',18)]+[('J2',p) for p in [4,13,12,10,9,8,7,6,17,5,11]]+[('J1',13)]
assert [r['gpio'] for r in rows]==gpios
assert [(r['socket'],r['socket_pin']) for r in rows]==pads
assert [r['cart_pin'] for r in rows]==list(range(6,30))+[5,4,3,30]
assert len(set(gpios))==28
assert not set(gpios)&{0,19,20,43,44,45,46,48}
header=(root/'firmware/main/pinmap.hpp').read_text()
for name,want in [('AD',gpios[:16]),('AH',gpios[16:24])]:
 actual=list(map(int,re.search(r'\b'+name+r'\s*=\s*\{([^}]+)',header)[1].split(',')))
 assert actual==want
for name,want in [('NCS',47),('NRD',2),('NWR',37),('NCS2',3),('UART_TX',43),('UART_RX',44)]:
 assert int(re.search(r'\b'+name+r'\s*=\s*(\d+)',header)[1])==want
xml=ET.parse(root/'hardware/verification/gba_dumper.xml')
nets={n.attrib['name'].lstrip('/'): {(p.attrib['ref'],p.attrib['pin']) for p in n.findall('node')} for n in xml.findall('.//nets/net')}
expected={k:set(map(tuple,v)) for k,v in json.loads((root/'hardware/verification/expected_nets.json').read_text()).items()}
for net,nodes in expected.items(): assert nets[net]==nodes,(net,nets[net],nodes)
# Independently enforce the entire signal chain, not just the generated expectation file.
for i,r in enumerate(rows):
 ref=f'R{i+1}'; s=r['signal']; cartpin=str(r['cart_pin'])
 assert nets['MCU_'+s]=={(r['socket'],str(r['socket_pin'])),(ref,'1')}
 cartnodes=nets['CART_'+s]
 assert ('J3',cartpin) in cartnodes
 assert (('JP1','2') if s=='nWR' else (ref,'2')) in cartnodes
 assert nets['WR_LINK']=={('R27','2'),('JP1','1')}
for ref,s in zip(range(29,33),['nCS','nRD','nWR','nCS2']):
 assert (f'R{ref}','1') in nets['CART_3V3'] and (f'R{ref}','2') in nets['CART_'+s]
assert nets['BOARD_3V3']=={('J1','1'),('J1','2'),('JP2','1')}
assert nets['CART_3V3']=={('JP2','2'),('J3','1'),('C1','1'),('C2','1'),('TP1','1')}|{(f'R{i}','1') for i in range(29,33)}
assert nets['CART_nREQ']=={('J3','31'),('TP12','1')}
assert nets['CART_PHI']=={('J3','2'),('R33','1'),('TP11','1')}
assert nets['GND']=={('J1','22'),('J2','1'),('J2','21'),('J2','22'),('J3','32'),('C1','2'),('C2','2'),('R33','2'),('TP2','1')}
connected=set().union(*expected.values())
for pad in [('J1','3'),('J1','14'),('J1','21')]+[('J2',str(p)) for p in [2,3,14,15,16,19,20]]:
 assert pad not in connected
 unexpected=[n for n,v in nets.items() if pad in v and not n.startswith('unconnected-')]
 assert not unexpected,(pad,unexpected)
components={c.attrib['ref']:c for c in xml.findall('.//components/comp')}
assert len(components)==52
for i in range(1,34): assert components[f'R{i}'].findtext('value')==('330' if i<=24 else '100' if i<=28 else '10k' if i<=32 else '10k / PHI pulldown')
assert 'Errors 0  Warnings 0' in (root/'hardware/verification/erc.rpt').read_text()
print('PASS: 28 GPIO; independent 32-pin/socket mapping; C++ arrays; 62 logical nets; series paths; JP1/JP2; NC; BOM; ERC')
# Selected PCBA parts must agree with the exported schematic and the supplier BOM.
import csv
parts=json.loads((root/'hardware/bom/selected_parts.json').read_text())
assert len(parts)==5
refs=[ref for p in parts for ref in p['refs']]
assert len(refs)==35 and len(set(refs))==35
assert set(refs)=={f'R{i}' for i in range(1,34)}|{'C1','C2'}
assert [p['lcsc'] for p in parts]==['C17630','C17408','C17414','C49678','C15850']
for p in parts:
 assert p['classification']=='Basic' and p['package']=='0805'
 for ref in p['refs']:
  comp=components[ref]
  assert comp.findtext('footprint')==p['footprint']
  fields={f.attrib['name']:f.text for f in comp.findall('fields/field')}
  assert fields['LCSC']==p['lcsc'] and fields['MPN']==p['mpn']
with (root/'hardware/bom/jlcpcb_pcba.csv').open() as f: supplier=list(csv.DictReader(f))
assert len(supplier)==5
for row,p in zip(supplier,parts):
 assert row['Designator'].split(',')==p['refs']
 assert row['LCSC Part Number']==p['lcsc']
 assert row['Footprint']==p['footprint'].split(':')[1]
print('PASS: PCBA BOM 5 Basic part numbers / 35 placements; schematic MPN/LCSC and footprints match')
for ref in ['JP1','JP2']:
 comp=components[ref]
 assert comp.findtext('footprint')=='GBA_Mechanical:PinHeader_1x02_P2.54mm_D1.02mm'
 fields={f.attrib['name']:f.text for f in comp.findall('fields/field')}
 assert fields['MPN']=='PH-1X2SG' and fields['Supplier Code']=='108593'
fp=(root/'hardware/lib/GBA_Mechanical.pretty/PinHeader_1x02_P2.54mm_D1.02mm.kicad_mod').read_text()
assert re.findall(r'\(drill ([^)]+)\)',fp)==['1.02','1.02']
assert re.findall(r'\(pad "(\d+)"',fp)==['1','2']
assert '(at 0 2.54)' in fp
manual=json.loads((root/'hardware/bom/manual_parts.json').read_text())
assert [(p['mpn'],p['quantity']) for p in manual if p['mpn'] in {'PH-1X2SG','2228GG'}]==[('PH-1X2SG',2),('2228GG',2)]
assert not any('JP' in row['Designator'] for row in supplier)
print('PASS: JP1/JP2 PH-1X2SG; two 1.02mm holes at 2.54mm pitch; 2 caps; excluded from PCBA')
for ref in ['J1','J2']:
 fields={f.attrib['name']:f.text for f in components[ref].findall('fields/field')}
 assert fields['MPN']=='FH2.54-40U1GF8.5-0.5' and fields['Supplier Code']=='110073'
assert components['J3'].findtext('footprint')=='Gekkio_Connector_PCBEdge:GameBoy_Cartridge_AGB_1x32_P1.50mm_Socket_Horizontal'
for i in range(1,13):
 assert components[f'TP{i}'].findtext('footprint')=='GBA_Mechanical:TestPoint_Pad_D2.0mm'
tp=(root/'hardware/lib/GBA_Mechanical.pretty/TestPoint_Pad_D2.0mm.kicad_mod').read_text()
assert '(size 2 2)' in tp and '(layers "F.Cu" "F.Mask")' in tp
assert 'F.Paste' not in tp and '(drill' not in tp
assert all(c.findtext('footprint') for c in components.values())
with (root/'hardware/bom/assembly_parts.csv').open() as f: assembly=list(csv.DictReader(f))
assert next(p for p in assembly if p['MPN']=='FH2.54-40U1GF8.5-0.5')['Quantity per board']=='2'
assert next(p for p in assembly if p['Usage']=='J3')['Supplier Code']=='1005005472303111'
print('PASS: all 52 footprints assigned; TP pads without paste/drill; socket strip quantity; J3 procurement identity')
